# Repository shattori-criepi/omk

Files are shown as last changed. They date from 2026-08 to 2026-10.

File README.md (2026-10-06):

# OMK — おうちモニタキット

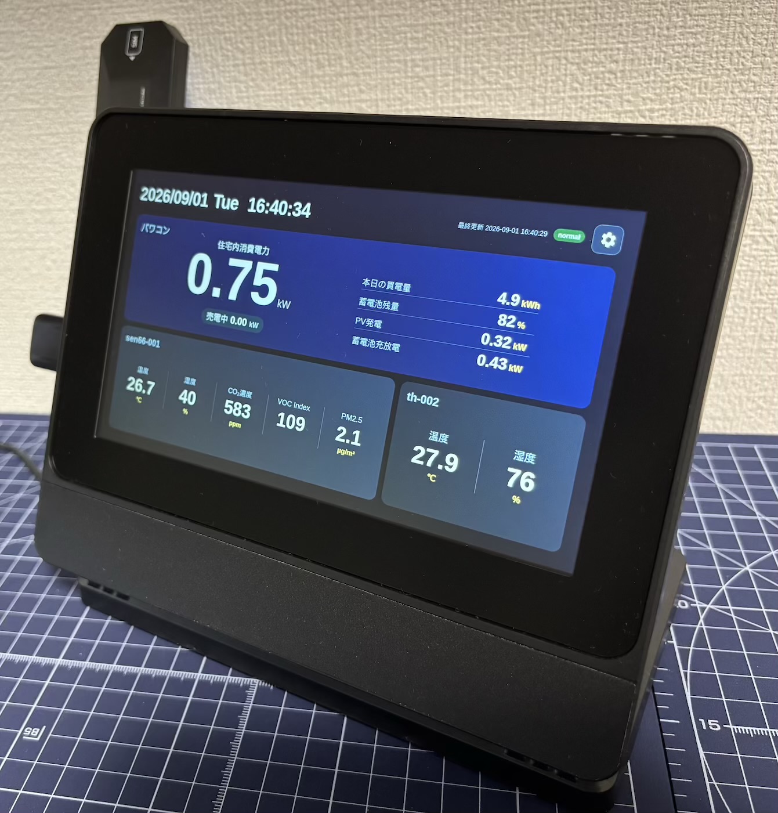
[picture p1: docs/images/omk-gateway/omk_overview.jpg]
OMK Gateway


おうちモニタキット（OMK）は、一般財団法人電力中央研究所が開発した、住宅内の電力・環境・行動を計測するオープンなIoT基盤です。計測したい項目に合わせてセンサを組み合わせ、Raspberry Piをデータ収集・保存の中心となるGatewayとして使います。標準構成では、構築後は住宅側ネットワークに依存せず運用できます。

## できること

- 対応するセンサ・機器から、住宅の温度、湿度、空気質、電力、在不在などのデータを計測・収集できます。
- Raspberry Piに計測データを保存し、長期間の履歴として蓄積できます。
- Gateway内のローカルDashboardで、現在の計測値と機器の状態を確認できます。
- 保存済みデータをCSV/ZIPとしてUSBメモリへ書き出せます。
- SORACOM Harvestを利用する場合は、計測データをクラウドへ送信して保管できます。

## OMKの製作方法

初めて製作する方は、以下を上から順に読み、各ページ末尾の「次へ」で進めてください。GatewayとSEN66 Nodeを製作し、4-1のDashboardで計測確認まで完了します。

### 1. OMKの概要

- [1-1. OMK導入ガイド](docs/user/getting-started.md)
- [1-2. 対応センサ・機器と取得データ](docs/user/supported-devices.md)

### 2. OMK Gatewayを製作・セットアップする

- [2-1. OMKのパーツ構成](docs/user/parts-list.md)
- [2-2. Gatewayの組み立て](docs/user/gateway-assembly.md)
- [2-3. Gatewayセットアップ](docs/user/gateway-setup.md)

### 3. SEN66 Nodeを製作・セットアップする

- [3-1. SEN66 Nodeの組み立て](docs/user/sen66-node-assembly.md)
- [3-2. SEN66 Nodeをセットアップする](docs/user/esp32-node-setup.md)

### 4. Dashboardを使う

- [4-1. Dashboardの使い方](docs/user/dashboard.md)

ここまでで、推奨構成のOMKの製作・セットアップとSEN66による計測確認は完了です。

## 必要に応じて行う作業

製作完了後に、目的に合うページを選んでください。

- [BLEセンサを追加する](docs/user/ble-sensor-setup.md)
- [Bルートでスマートメーターを追加する](docs/user/broute-setup.md)
- [OMK Nodeで計測範囲を拡張する](docs/user/node-and-sensors.md)
- [中継専用OMK Nodeをセットアップする](docs/user/relay-node-setup.md)
- [Gatewayソフトウェアを更新・保守する](docs/user/gateway-maintenance.md)
- [OMK Nodeを更新・再設定する](docs/user/node-maintenance.md)
- [標準構成以外・高度な構成](docs/user/advanced-configuration.md)

## 参考情報

- [用語集](docs/user/glossary.md)
- [トラブルシューティング](docs/user/troubleshooting.md)

## 対応機器と取得データ

主な対応機器と取得データは次のとおりです。計測項目、接続方式、対応範囲の詳細は[「1-2. 対応センサ・機器と取得データ」](docs/user/supported-devices.md)を参照してください。

| 機器・センサ | 主な取得データ |
| --- | --- |
| 低圧スマートメーター（Bルート） | 系統の瞬時電力、買電・売電の積算電力量、30分ごとの買電量・売電量 |
| Sensirion SEN66 | 温度、相対湿度、CO₂濃度、粒子状物質、VOC Index、NOx Index |
| SwitchBot BLEセンサ | 温湿度、CO₂濃度、人感、開閉、プラグの消費電力・スイッチ状態、防水温湿度 |

## 動作確認環境と利用上の前提

OMKで動作確認している推奨構成は次のとおりです。

- Gateway：**Raspberry Pi 4、Raspberry Pi Touch Display 2（7インチ）、SORACOM Onyx**。OSは64ビットのRaspberry Pi OSを使用します。
- SEN66 Node：Sensirion SEN66とAtomS3 Lite。

初期セットアップには、既存Wi-Fiなどのインターネット接続を使います。APはAccess Point（アクセスポイント）の略です。OMK APを有効にすると、Raspberry Piの内蔵Wi-FiはOMK AP専用となり、外部Wi-Fiには接続できません。推奨構成ではSORACOM Onyxを外部通信と遠隔管理に使います。

標準構成以外の対応範囲と制約は、[「標準構成以外・高度な構成」](docs/user/advanced-configuration.md)を参照してください。

## OMKを開発する

- [アーキテクチャ](docs/developer/architecture.md)
- [開発ガイド](docs/developer/development.md)
- [Gatewayネットワーク設計](docs/developer/networking.md)
- [データ経路とMQTT仕様](docs/developer/data-and-mqtt.md)
- [リポジトリ構成](docs/developer/repository-structure.md)
- [設計判断の記録](docs/decisions/)

各サービスとファームウェアのREADMEには、個別の起動・設定・テスト・デバッグ方法を記載しています。

## 利用上の注意

OMKは研究・実験用途のシステムであり、商用製品やサービスではありません。計測値の正確性、完全性、継続性、対応機器との互換性、安定動作および安全性は保証しません。利用、改変、機器への接続、再配布は各利用者の判断と責任で行ってください。料金精算、契約上の計量、安全制御、保護制御など、高い信頼性を要する用途での利用は想定していません。

無保証および責任制限は[LICENSE](LICENSE)を参照してください。

## 成果発表

OMKを使用した技術開発等の成果を発表・報告する際は、可能な範囲でOMKを使用した旨の表示をお願いします。

## サポートと開発方針

GitHub等から利用する場合、機器の準備、構築、設定、運用、保守は利用者自身で行います。研究所および開発者は、個別環境への導入・設定支援、機器の製作代行、トラブル対応などの個別サポート、保守、動作保証を提供しません。

活用例、アイデア、改善案など、OMK全体に有用な情報の共有は歓迎します。ただし、相談や要望に対する回答、調査、機能追加、機器対応、修正などの対応は約束しません。

特定の利用者だけに必要な機能は、利用者自身のforkで開発・維持することを想定します。OMK全体に有用なアイデアは、研究目的、汎用性、保守性、開発優先度などを踏まえて採用を検討します。提案者にPR作成を求めるとは限らず、OMK開発側が実装する場合や、実装を見送る場合もあります。

GitHubでの情報共有・提案は、次の方針で受け付けます。

- GitHub Discussions：アイデア、活用例、利用方法の情報共有に使います。無償の個別サポート窓口ではありません。
- Issue：再現可能な不具合や、対応が決まった課題の管理に使います。単なる機能追加要望はDiscussionへ投稿してください。
- コード変更・機能追加の提案：まずDiscussionで目的、背景、想定用途、OMK全体への有用性を共有してください。OMKリポジトリへの取り込みを検討する場合は、必要に応じてIssue化やPR提出を案内します。PRの常時募集は行わず、事前相談のないPRへのレビュー、マージ、対応は約束しません。

電力中央研究所が主体となる研究・実証・被験者実験で設置する場合は、研究計画に基づき、研究実施側が設置、運用、保守、トラブル対応等を行います。上記の自己責任・サポート方針によって、実験協力者へ保守責任を転嫁することはありません。

## ライセンス

OMKのソフトウェアは[使用、複製および頒布に関する条件](LICENSE)で公開します。OMKの著作権は一般財団法人電力中央研究所に帰属します。

利用、改変、再配布、商用利用については、使用許諾条件に従ってください。

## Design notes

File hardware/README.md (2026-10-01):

# ハードウェア成果物

このディレクトリには、現行構成で再現可能な筐体などのハードウェア成果物を置いています。Gateway、Docker、NetworkManagerの設定手順は[Gatewayセットアップ](../docs/user/gateway-setup.md)、内部のネットワーク設計は[ネットワーク設計](../docs/developer/networking.md)を参照してください。

## 現在の構成

- Gateway: Raspberry Pi 4、64-bit Raspberry Pi OS
- Node: AtomS3 LiteのOMK Node。SEN66等のI2CセンサとBLE relayを扱う
- Bルート: 対応USBシリアルアダプタをGatewayのhost serviceで利用
- BLE: Gateway direct BLEを主系、Node relayを補助経路として利用
- 住宅用PV・蓄電池・PCS: 現行の単一検証profile向けECHONET Lite連携はGatewayホストに任意導入するサービス

## ディレクトリ

- [`enclosures/sen66-node/`](enclosures/sen66-node/README.md): SEN66 Node試作筐体の格納済みSTLと使用上の注意
- [`enclosures/omk-gateway/`](enclosures/omk-gateway/README.md): SORACOM OnyxをGatewayへ取り付けるための固定用3Dプリント部品

SEN66計測にもBLE中継にも、AtomS3 Liteの共通Node firmwareを使用します。

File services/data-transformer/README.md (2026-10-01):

# data-transformer

`sensor-collector` が保存した日次JSONLを、分析用のParquetへ変換する独立コンポーネントです。collectorの一次データは変更しません。

```bash
cd services/data-transformer
python -m venv .venv
.venv/bin/pip install -r requirements-dev.txt
PYTHONPATH=src .venv/bin/python -m data_transformer --input ../../data/sensors/2026/07/30.jsonl --output /tmp/omk-parquet-example
PYTHONPATH=src .venv/bin/pytest -v
```

上の単体変換例は試験用出力先を使います。稼働中の`data/processed`を再処理する場合は、下記の入力パス規約を維持してください。

Raspberry Pi 4（Python 3.13.5、aarch64）では`pyarrow==20.0.0`、`duckdb==1.3.2`、`pytest==9.1.1`で検証しています。

## Parquet検証

DuckDB CLIは不要です。リポジトリ直下から、この仮想環境のPython版DuckDBで読み取り専用の検証を実行できます。

```bash
services/data-transformer/.venv/bin/python scripts/verify_parquet.py
```

`services/data-transformer`から実行する場合は、`.venv/bin/python ../../scripts/verify_parquet.py`です。

対象は`sen66`、`broute_power`、`broute_cumulative_energy`、`broute_interval_energy`です。全日付パーティションを自動で横断し、基本情報、パーティション別件数、NULL・時間別集計、SEN66受信間隔、30分値と積算差分の照合、SEN66と瞬時電力のASOF結合を表示します。Parquetや外部DBファイルを変更しません。別の出力先を確認する場合は`--data-root /path/to/processed`を指定できます。

## 変換対象と出力

変換CLIの`python -m data_transformer`では、`--input`の代わりに`--date 2026-07-30 --data-root data/sensors`を指定できます。`--dry-run`、`--log-level DEBUG`も変換CLIのオプションです。これらは上記の`verify_parquet.py`のオプションではありません。パスはコマンドを実行するディレクトリからの相対パスです。

計測トピックのBルート`power`、`cumulative-energy`、`interval-energy`、SEN66の`sen66`、Ichijoの`power-flow`、BLEの`environment`、`motion`、`contact`、`power`をParquetへ変換します。BLEは旧payloadの`sensor_id`を`device_id`として正規化し、`measured_at`がない場合はcollector受信時刻を使用します。`/power`はpayloadの`net_power_w`をBルート、`power_w`をBLEとして識別します。`omk/<device_id>/status`、`omk/node/<node_id>/status`、`omk/node/<node_id>/registration/status`、`omk/node/<node_id>/registration/ack`、`omk/node/<node_id>/registration/config`は管理情報として意図的に除外し、`ignored`と`ignored_topics`にだけ記録します。未知・不正トピックは`data/errors/transform/YYYY-MM-DD.jsonl`へ原因と元行を記録します。

出力は `data/processed/<dataset>/date=YYYY-MM-DD/data.parquet` です。データセットは`broute_power`、`broute_cumulative_energy`、`broute_interval_energy`、`sen66`、`ichijo_power_flow`、`ble_environment`、`ble_motion`、`ble_contact`、`ble_power`です。日付はBルート瞬時電力・BLE・Ichijoでは計測時刻、積算電力量では計量時刻、30分値では終了時刻、SEN66ではファームウェアが時計を持たないためcollector受信時刻のJST日付を使用します。Ichijoの`quality=degraded`レコードは計測値がnullでも`errors`（string list）とともに保持しますが、`quality=normal`では主要計測値を引き続き必須とします。今回の正常行があるpartitionは一時ファイルから原子的に置換します。置換前に同じ`source_file`の既存行だけを外してから今回の行を追加するため、同じ`source_file`表記による入力の再実行では重複せず、遅延レコードの処理で別source file由来の既存行を消しません。

### 入力パスと再処理の制約（再現確認済み）

処理済みcheckpointや別state fileはなく、毎回JSONL全体を読みます。Parquetの`source_file`に入力パスの文字列表現を保存し、merge時は今回と文字列が一致する行だけを置換します。`source_line_number`は来歴であり、record-levelの重複排除キーではありません。mtime、size、content hash、inode、timestamp/device IDによる同一性判定も行いません。

同じJSONLを同じ出力先へ別表記で投入すると、変換対象の正常行がdataset/date partitionごとに追加されます。別プロセスでの再実行でも同じ結果です。同じ表記を繰り返すだけなら増殖しませんが、既に別表記で保存された行は残ります。今回の入力に正常行がないpartitionは置換しないため、入力行の削除を既存Parquetへ反映する機能でもありません。

Python 3.13.15、固定依存のPyArrow 20.0.0 / DuckDB 1.3.2で、次を一時JSONLと新しい出力先だけを使って確認しました。

| 同じ実ファイルへの表記変更 | 再実行後 |
| --- | --- |
| 同一表記、先頭`./`、末尾スラッシュ | 重複なし。後二者はCLIの`Path`変換で除去される |
| 相対→絶対、`data/../data/...` | 重複する |
| ファイルsymlink、ディレクトリsymlink経由 | 重複する |
| リポジトリルートの`data/sensors/...`→サービス配下の`../../data/sensors/...` | 重複する |

再現試験では同一timestamp/device IDの30分値が2行になり、買電量合計も1.5 kWhから3.0 kWhへ増えました。Dashboardの日計はParquetを合計するため影響を受け、CSV exportにも重複が出ます。元JSONL、latest cache、MQTTを直接購読するHarvestの集約は、このParquet再変換では変更しません。

標準timerはホストのリポジトリルートで`--date`・`--data-root data/sensors`を使用します。同じ構成でのservice restart、Gateway reboot、setup再実行、通常updateは入力表記を変えません。collectorのDocker内`/app/data/sensors`は入力JSONL内のsource識別子ではなく、通常のtransformerはDocker外で動きます。一方、手動復旧、`--input`への切替、絶対パスの指定、別cwdからの実行、独自container/mount構成への変更では発生し得ます。

本番の手動再処理も標準timerと同じcwd・入力指定を使い、timerとの同時実行は避けてください。これは新しい別表記を増やさないための暫定運用であり、既存の重複は修復しません。

### path正規化を導入する際の互換性

新規保存だけを`Path.resolve()`へ変更すると、旧相対`source_file`と一致せず初回mergeで二重化します。旧値まで現在のcwd/symlinkで解決すると、当時と異なる実体へ対応付けて別入力の行を消す危険があります。旧Parquetは当時のcwdやsymlink先を記録しておらず、異なるcwdにある別ファイルから同一の`source_file`・行内容が生成されるケースも確認しました。この情報だけから安全な自動移行はできません。

修正候補は、新しい入力について解決済み絶対パスを保存し、同一表記差を同じ入力にする方法です。symlinkの実体切替やファイル移動は別入力として扱い、同内容の別ファイルをhashでまとめません。ただし導入には、旧形式を識別して無条件mergeを止める仕組みと、確認済みの旧source対応付け、または元JSONLが揃った状態での新しい出力先への全量再生成・比較・明示的切替が必要です。リポジトリ移動やmount先変更も移行対象になります。今回、機能コードの変更や既存Parquetの移行・修復は行っていません。

### 既存Parquetの重複候補を調べる

次はDuckDBで実行する読み取り専用SQLです。対象datasetの全partitionから、`source_file`以外の全列（`source_line_number`を含む）が同じで、source表記が複数ある行を探します。Python版DuckDBの`execute()`でも実行できます。ファイルがないdatasetには実行しません。

```sql
SELECT * EXCLUDE (source_file),
       count(*) AS copies,
       list(DISTINCT source_file) AS source_paths
FROM read_parquet('data/processed/broute_interval_energy/date=*/data.parquet')
GROUP BY ALL
HAVING count(DISTINCT source_file) > 1;
```

これは候補検出であり、同じtimestamp/device IDだけで削除を判断しません。正当な別入力に同一行がある場合も候補になり、行順変更等による重複は検出できないことがあります。元JSONL、当時の実行場所、source表記を照合して修復範囲を決めます。今回の作業環境には既存のJSONL/Parquetがなく、稼働Gatewayで既に発生しているかは未確認です。

## Raspberry Piでの1時間間隔実行

DockerではなくRaspberry Piホストのsystemd timerで実行します。リポジトリルートで次を実行してください。runtime依存のみを使うため、セットアップは`requirements.txt`をインストールします（`requirements-dev.txt`は使いません）。

```bash
chmod +x scripts/setup-data-transformer.sh scripts/run-data-transformer.sh
./scripts/setup-data-transformer.sh
```

セットアップはPython、venv、pip、`flock`を提供する`util-linux`を確認し、不足時だけ導入します。`services/data-transformer/.venv`、`data/processed`、`data/errors/transform`を作成し、実行ユーザーとリポジトリパスを埋め込んだunitを`/etc/systemd/system`へ配置します。実行ログは`logs/setup/`にも保存されます。

`omk-data-transformer.timer`は起動約2分後に開始し、その後1時間ごとに動作します。JST当日と前日をこの順で処理します。前日処理は日付切替直後に遅れて到着したレコードを取り込むためで、JSONLが存在しない日は「処理対象なし」として正常終了します。一方の日付で失敗してももう一方を処理し、最後に失敗があれば終了コード1として次回timerで再試行します。

同時起動は`data/.data-transformer.lock`への`flock`で防止します。すでに実行中ならその回は正常終了でスキップします。進行中の追記の末尾行が一時的に`invalid_json`になっても、次回の全量再変換で回復します。NULバイトなどの不正行は`data/errors/transform`へ記録され、正常行の変換は継続します。

確認と停止は次のとおりです。

```bash
sudo systemctl status omk-data-transformer.timer --no-pager
systemctl list-timers omk-data-transformer.timer
sudo journalctl -u omk-data-transformer.service --since today --no-pager
sudo systemctl disable --now omk-data-transformer.timer
```

`./scripts/setup-data-transformer.sh --print-units` は`/etc`を書き換えずにservice templateの展開結果を表示します。

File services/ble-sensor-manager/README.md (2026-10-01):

# OMK BLEセンサマネージャー

このRaspberry Piホストサービスは、BlueZ/BleakでペアリングせずBLEアドバタイズを受信し、物理的な`device_key`をOMKの論理的な`sensor_id`へ対応付け、`omk/living-env-01/environment`のようなベンダー非依存のMQTT topicをpublishします。

このサービスはDashboardコンテナの外で動作し、Dockerはホストゲートウェイ経由でポート8787へ接続します。BlueZのDBusソケットや特権コンテナは不要なため、Bluetoothへのアクセスはホストサービスに分離されたままです。setupが導入する`omk-ble-api.service`とnftables規則により、ポート8787への入力はloopbackとDocker bridgeに限定します。このAPI自体には認証がないため、この制限を維持し、ブラウザからはDashboard backendを経由します。

Pi上で`scripts/setup-ble-sensor-manager.sh`を実行すると、virtualenvの作成とsystemd unitの導入・再起動を行えます。unitは`OMK_BLE_REGISTRY`と`OMK_NODE_REGISTRY`をそれぞれ`data/ble/sensors.json`と`data/ble/nodes.json`へ設定し、`data/ble`だけを書込み可能にしたまま`ProtectSystem=strict`を維持します。登録情報はこれらの可読なJSONへ保存します。

## ESP32 Node初回Wi-Fi設定

Nodeの初回Wi-Fi設定はBLE Sensor Managerでは行わない。一般利用者はNodeをGatewayへUSB接続し、[Dashboardのセットアップ](../../docs/user/esp32-node-setup.md)でsystem-managerにprebuilt書込みとWi-Fi設定を要求する。通常firmware導入済みNodeへの開発用Wi-Fi設定には`python3 scripts/provision_omk_node_via_usb.py`も利用できる。USB transportはNode IDを取得し、credential保存・software reboot・MQTT registration statusまでを確認する。通常のBLE scan、SwitchBot relay、MQTT Node registrationはこの操作から独立して継続する。

Nodeの`node_id`はeFuse由来の物理IDであり、`logical_id`はNode自身が測定値を`omk/<logical_id>/...`へ送る場合だけの論理IDである。`logical_id`は全Nodeで一意でなければならず、Gatewayは重複した登録要求・ACK・registration statusを拒否する。BLE relay専用Nodeはrelay topicに`node_id`を使うため、`logical_id`を登録する必要はない。

新品Gatewayでも、NodeがMQTT接続時に送るretained `registration/status`の`logical_id`から登録情報を復元する。Node自身のNVSを情報源とし、以前のGateway registryやACKは不要。IDのない旧firmwareのregistered statusも受理し、既存のLogical IDを保持する。`provisioned` statusは従来どおり登録を解除する。payloadと互換性の詳細は[MQTT仕様](../../docs/developer/data-and-mqtt.md#payload)を参照。

機器管理画面では登録済みSEN66 NodeのLogical ID変更と登録解除ができる。変更はNodeのACKを受けるまでGateway上の現在値を変更せず、解除はWi-Fi credentialを残したままNodeのlogical registrationとretained ACKを消去する。オフライン中の解除要求もretain付き設定で次回接続時に適用される。

`device_key`は物理的な識別子（`switchbot:<コロンを除いた小文字MAC>`）、`sensor_id`はOMKの論理的な識別子です。registryには`device_key`、`sensor_id`、`sensor_type`、vendor、model、location、`display_name`、`enabled`だけを保存します。最新の測定値、RSSI、受信時刻、生のBLEアドバタイズデータはruntime stateとして保持し、registryへは書き込みません。

## ESP32 Node relay入力

ESP32 NodeはGatewayの`sensor_id`、SwitchBotの機種判定、decoderを持たない。Nodeはmanufacturer data、service data、BLE address、RSSIをraw observationとして次の内部MQTT topicへpublishし、Gatewayがdirect BLEと同じdecoderで`device_key`を決定する。

```text
omk-relay/<relay_node_id>/ble/raw
```

このサービスはこのtopicを購読し、既存registryで`device_key`に対応するsensorを特定します。登録済みかつ`enabled=true`のenvironment、motion、contact、power sensorだけを、Gateway受信時刻を`measured_at`として通常のsensor topicへ`source: "relay"`と`relay_node_id`を保ったまま再publishします。未登録・disabledのdevice_keyは通常sensor topicへpublishせず、自動登録もしません。

direct BLEも同じ通常のsensor topicへ`source: "direct"`でpublishします。Gatewayは有効なdirect observationを受信してから30秒未満のrelayを抑止し、direct復帰時は同値でも最初のdirectを即時publishします。経路の冗長化とJSONL/Harvestでの重複排除は[`docs/decisions/ble-direct-relay-route-selection.md`](../../docs/decisions/ble-direct-relay-route-selection.md)を参照してください。

Dashboardの機器管理内のセンサ登録フローでは、未登録のBLEアドバタイズを発見・分類し、IDを提案した後、選択した表示名とlocationで登録します。`temperature_humidity_sensor`と`waterproof_sensor`には未使用で最小の`th-xxx`、`co2_sensor`には`co2-xxx`、状態センサには対応する`motion-xxx`（人感センサーとPresence Sensor Pro）/ `contact-xxx`を提案します。センサを交換した場合は、原則として新しい論理IDを発行します。

未知のSwitchBot BLEアドバタイズは、セットアップ中にmanufacturer dataとservice dataの生hexを付けて意図的に表示します。推測した値をpublishせずに、Meter Pro CO2、人感センサ、開閉センサを実機で検証できるようにするためです。

OMKでは製品名と内部modelを分離しています。SwitchBot MeterおよびMeter Plusは`temperature_humidity_sensor`、SwitchBot Meter Pro CO2は`co2_sensor`を使用します。旧来の`meter`、`meter_plus`、`meter_pro_co2`を持つ既存registryは互換的に読み込み、次回のregistry更新時に現行名へ書き換えます。

| OMK model | Dashboard表示名 | sensor type | 正規化後の値 |
| --- | --- | --- | --- |
| `temperature_humidity_sensor` | SwitchBot 温湿度計 | `environment` | `temperature_c`, `relative_humidity_percent` |
| `co2_sensor` | SwitchBot CO2センサー | `environment` | 温度、湿度、`co2_ppm` |
| `motion_sensor` | SwitchBot 人感センサー | `motion` | `motion_state` (0=不在, 1=検知) |
| `presence_sensor` | SwitchBot Presence Sensor Pro | `motion` | `motion_state` (0=不在, 1=検知), `battery_percent`, `light_level` |
| `contact_sensor` | SwitchBot 開閉センサー | `contact` | `contact_state` (0=閉, 1=開) |
| `waterproof_sensor` | SwitchBot 防水温湿度計 | `environment` | `temperature_c`, `relative_humidity_percent` |
| `plug_sensor` | SwitchBot プラグミニ | `power` | `power_w`, `switch_state` (0=OFF, 1=ON) |

`waterproof_sensor`は屋外専用ではありません。設置用途は`location`（例: 屋外、浴室）で表します。`humidity_percent`、`outdoor_meter`、`waterproof_meter`はOMKのschema/model名ではありません。

## 登録の削除と交換

管理画面の`/admin/sensors`では、編集画面から登録済みBLEセンサを`device_key`単位で登録解除できます。この操作はregistryの登録情報だけを削除し、JSONL、Parquet、Harvest retry queue、SORACOM Harvest Data、MQTTの過去履歴には一切触れません。削除された`sensor_id`は空くため、故障交換時は旧センサを削除し、セットアップモードで発見した新品へ同じ`sensor_id`を再使用できます。

`enabled=false`は一時的な停止であり、registryと`sensor_id`の占有を維持しつつruntime stateの更新だけを続け、MQTT publishを止めます。一方、削除後はregistryから完全に外れ、以後MQTT publishしません。周囲で同じ物理デバイスのBLEアドバタイズを受信し続けていれば、未登録candidateとして再び表示され、セットアップから再登録できます。

BLEアドバタイズはペアリングなしで継続受信します。`enabled=true`のenvironmentセンサは、最初に有効な値を受信した時点で即時publishし、その後は`device_key`ごとに最短10秒間隔でpublishします。runtime stateはBLE受信ごとに更新します。motionとcontactは状態変化時に即時publishし、加えて現在状態を最短10秒間隔でpublishします。これらの制限にはmonotonic clockを使用します。Plug Miniの電力も同じ10秒制限に従いますが、`switch_state`の変化時は即時publishします。`enabled=false`のセンサもruntime stateは更新しますが、MQTTはpublishしません。Plug Miniには`plug-xxx`を提案し、`power_w`と`switch_state`を含む`omk/<sensor_id>/power`をpublishします。

対応serviceのdevice typeを先に選び、登録済みmodel hintと矛盾したらunknownにします。serviceがないmanufacturer-only packetは、既存登録のhintに対応する形式だけを検証します。長さ・実測marker・正常値だけで新規機種を判定しません。MeterとMeter Pro CO2の観測済みmanufacturer形式も同じ方針です。CO2の2個体での実測は値形式の根拠であり、16-byte長の機種固有性を保証しません。

manufacturer-only packetは自動ではunknownになります。対応するmanufacturer decoderで再検証し、成立するmodelがちょうど1種類の候補だけに「候補（未確認）」と参考値を表示します。たとえば防水温湿度計では温度・相対湿度、人感センサーでは検知状態を確認できます。複数modelが成立するpacket、不正値、矛盾するservice dataには登録ボタンを出しません。参考値はcandidate APIとDashboardの確認専用で、利用者が機種を確認して登録するまでhint、MQTT通常topic、保存・集約には使いません。Meterの`0x54` / `0x69`、CO₂センサーの`0x35`、Motion Sensorの`0x73` serviceは自動識別を維持します。Motionは妥当なmanufacturer statusがあれば、その検知状態をservice値より優先します。firmware/broadcast modeやservice取得可否により、対応製品でも未認識となる可能性があります。不正値・矛盾は空valuesとし、登録・測定値publishに使いません。登録済み一覧の未識別packetは「機種・データ未確認」と表示します。根拠分類、移行上の注意、実機確認計画は[model evidence設計](docs/switchbot-model-evidence.md)を参照してください。

将来のclassifier変更では、[2026-08-20 SwitchBot raw capture監査](docs/switchbot-raw-capture-audit-2026-08-20.md)に記録した個体数・capture数・byteごとの根拠レベルも参照してください。

## Raspberry Piでの確認事項

Pi内蔵Bluetoothでは、SwitchBot BLEアドバタイズが`manufacturer_data[0x0969]`だけで報告されることがあり、Presence Sensor ProのScan ResponseをHCIレベルで取得できない実機差が確認されている。そのため`service_data`が空でもエラーではない。AtomS3 Lite Node relayはactive scanでScan Responseを取得でき、Presence Sensor Proのmanufacturer dataとfd3d service dataを結合したraw observationを実機確認済みである。新しいfixtureを取得する際、`raw_scan`は両方の構造を出力する。

公開前の追加実機確認では、利用者が新品microSDから標準Pi4 Gatewayを構築し、旧registryなしでPresence Sensor Proを初回登録できたと報告している。service dataの取得には環境差があるという上記の観測記録と、このfresh登録成功は区別して保持する。

```sh
PYTHONPATH=src .venv/bin/python -m omk_ble.raw_scan --seconds 30
```

サービスを起動する前に、`rfkill list bluetooth`と`bluetoothctl show`でアダプタを確認します。soft blockされている場合は、`sudo rfkill unblock bluetooth`、続いて`sudo bluetoothctl power on`を実行してください。セットアップスクリプトも可能な範囲でこれらを実行します。アダプタがない、または電源を投入できない場合は、導入を失敗させず警告を記録します。

過去のRaspberry Pi実機確認記録（今回の判定変更後の実機確認は未実施）:

- SwitchBot 温湿度計: BLEアドバタイズの受信、温度・湿度のdecode。
- SwitchBot CO2センサー: BLEアドバタイズの受信、温度・湿度・CO2 ppmのdecode（2台の実機で確認）。
- SwitchBot 人感センサー: BLEアドバタイズの受信、状態遷移、定期MQTT publish。
- SwitchBot Presence Sensor Pro: BLEアドバタイズの受信、在不在状態・battery・照度のdecode。
- SwitchBot 開閉センサー: BLEアドバタイズの受信、状態遷移、定期MQTT publish。
- SwitchBot 防水温湿度計: BLEアドバタイズの受信、専用temperature/humidity manufacturer layoutのdecode。
- SwitchBot プラグミニ: BLEアドバタイズのみからの電力・switch stateのdecode。公開されている`0x67`および国内実機で観測した`0x6a`のservice typeをmanufacturer推定より優先します。電力値はMSBのoverload flagをmaskしてから、0.1 W scaleを適用します。

### SwitchBot プラグミニ実機確認

Raspberry Piと実Plug Miniで、ペアリングなしのBLEアドバタイズ受信からDashboardのBLEセットアップ、`plug-001`登録、MQTT、JSONL保存、Harvest 1分集約、SORACOM Harvest Data送信までを確認した。内部modelは`plug_sensor`、sensor typeは`power`、Dashboard表示名は「SwitchBot プラグミニ」である。

manufacturer dataではstate byteのbit 7を`switch_state`として用い、0=OFF、1=ONを実機のOFF→ON操作と照合した。電力は公式仕様に従い`raw_power = ((byte10 & 0x7f) << 8) | byte11`、`power_w = raw_power / 10.0`でdecodeする。byte10のbit 7はoverload flagであり電力値から除外する。低負荷で`0x0034`=5.2 W、`0x0035`=5.3 W（アプリ表示約5.1〜5.2 W）、高負荷で`0x05f2`=152.2 W、`0x06c4`=173.2 W、`0x06cd`=174.1 W（実負荷約170 W）を確認し、低負荷・高負荷とも0.1 W scaleが成立した。

国内実機ではfd3d Service Dataとして`6a0064`を観測した。`0x6a`は参照した公式実装にもあるが、公式BLE仕様書の`0x67`とは根拠を区別する。どちらもPlug選択の根拠とし、12-byte manufacturer layoutは選択後の値検証に使用する。

国内Plug Miniの複数個体で12-byte manufacturerアドバタイズデータを確認している。byte 8は旧個体で`0x16`、新品個体で`0x10`を観測したため、固定classifierには使用しない。service dataの公開device type `0x67`または国内実測値`0x6a`で識別できる場合、state byte（index 7）と末尾2 byteから値をdecodeする。state byteのbit 7は`switch_state`、電力は`((data[10] & 0x7f) << 8) | data[11]`に0.1 W scaleを適用する。新品実機の`...8010370037`はON / 5.5 Wとして確認した。service dataがない場合は登録済みPlug hintを要求し、未登録ではunknownにする。`0x16` markerだけでの初回識別は廃止した。`0x10`および`0x16`の意味は現時点で断定しない。

Piで行指向のraw captureを取得するには、`PYTHONPATH=src .venv/bin/python -m omk_ble.raw_scan --seconds 30`を使用します。

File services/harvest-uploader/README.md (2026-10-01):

# harvest-uploader

`harvest-uploader`はMQTTを独立クライアントとして`omk/#`購読し、受信時刻（Asia/Tokyo）の00秒から59秒までを住宅全体の1分レコードへ集約してSORACOM Harvest DataへPOSTします。受信した測定・管理メッセージのJSONL一次保存は`sensor-collector`が担い、本サービスはJSONLやParquetを読まず変更もしません。

## MQTT入力

| トピック | 使用フィールド |
| --- | --- |
| `omk/<device_id>/sen66` | `temperature_celsius`、`relative_humidity_percent`、`co2_ppm`、`pm1_0_ug_m3`、`pm2_5_ug_m3`、`pm4_0_ug_m3`、`pm10_0_ug_m3`、`voc_index`、`nox_index` |
| `omk/<device_id>/power` | `net_power_w` |
| `omk/<device_id>/cumulative-energy` | `cumulative_energy_import_kwh`、`cumulative_energy_export_kwh` |
| `omk/<device_id>/power-flow` | `pv_power_w`、`load_power_w`、`grid_import_power_w`、`grid_export_power_w`、`pcs_ac_output_power_w`、`battery_soc_percent`、`battery_charge_power_w`、`battery_discharge_power_w` |
| `omk/<sensor_id>/environment` | `temperature_c`、`relative_humidity_percent`、`co2_ppm`（存在する項目のみ） |
| `omk/<sensor_id>/motion` | `motion_state` |
| `omk/<sensor_id>/contact` | `contact_state` |
| `omk/<sensor_id>/power` | `power_w`、`switch_state`（Plug Mini等の電力センサ） |

Bルート`power`の`net_power_w`は正値が買電、負値が売電です。Plugの`power_w`とは区別します。電圧・電流・力率、蓄電池の運転状態はHarvestへ送信しません。不正JSON、JSON objectではないpayload、非有限数は安全に無視します。

### Thread model

Paho MQTTのnetwork callbackは、topic・payload・callback時点のJST受信時刻をthread-safeなFIFO inboxへ投入するだけです。集約、SQLite durable outbox、Harvest送信、retryは実行ループのmain threadだけがinboxをdrainした後に処理します。このため、処理遅延が分境界をまたいでも集約にはcallback時点の受信分を使い、SQLite connectionを複数threadで共有しません。

## Harvestフィールドと集約

SEN66はMQTT topicのLogical ID（1〜48文字の英数字、`-`、`_`）をfield prefixに使います。たとえば`omk/sen66-001/sen66`は`sen66-001_temperature_c`、`sen66-001_relative_humidity_percent`、`sen66-001_co2_ppm`、`sen66-001_pm1_0_ug_m3`、`sen66-001_pm2_5_ug_m3`、`sen66-001_pm4_0_ug_m3`、`sen66-001_pm10_0_ug_m3`、`sen66-001_voc_index`、`sen66-001_nox_index`を生成します。`sen66-002`も同じ規則で別fieldになり、同一分の平均値はSEN66ごとに独立します。Bルートは`broute_grid_power_w`、`broute_grid_import_power_w`、`broute_grid_export_power_w`、`broute_grid_import_energy_kwh`、`broute_grid_export_energy_kwh`です。電力系は`power_system_pv_power_w`、`power_system_load_power_w`、`power_system_grid_import_power_w`、`power_system_grid_export_power_w`、`power_system_pcs_ac_output_power_w`、`power_system_battery_soc_percent`、`power_system_battery_charge_power_w`、`power_system_battery_discharge_power_w`です。

`time`は区間開始時刻（例: `2026-08-05T10:34:00+09:00`）です。温湿度・空気質・各瞬時電力は有効サンプルの平均、積算買売電量とSOCは区間末の最新値です。欠測フィールドはJSONから省略し、全項目欠測の区間は送信しません。開いた1分区間はメモリだけに保持するため、再起動時には意図的に破棄されます。

`environment` は汎用のセンサ入力です。許可された `sensor_id`（英数字、`-`、`_`）ごとに、`<sensor_id>_temperature_c`、`<sensor_id>_relative_humidity_percent`、`<sensor_id>_co2_ppm` を生成し、存在する各項目を1分平均で送信します。これらはSEN66のLogical IDベースfieldと独立して共存します。

`motion` は `<sensor_id>_motion_state` をその1分の最大値として送信します（0=その分に検知なし、1=一度以上検知）。`contact` は開閉回数を保存せず、状態変化が一度でもあれば `<sensor_id>_contact_changed` を1、最後に観測した状態を `<sensor_id>_contact_state` として送信します（0=閉、1=開）。分境界をまたぐ状態変化は次の分の変化として扱い、再起動後の最初の観測は変化に数えません。

電力センサの`power` payloadに`power_w`または`switch_state`がある場合は、許可された`sensor_id`ごとに`<sensor_id>_power_w`（1分平均）と`<sensor_id>_switch_state`（分内の最後の正常値、0=OFF、1=ON）を送信する。Bルートの既存`power` fieldとは独立して共存する。

SwitchBot Plug MiniのPi実機では、`plug-001_power_w`と`plug-001_switch_state`が SORACOM Harvest Dataへ送信されることを確認した。分内で負荷を変えた例では瞬時値が約170 Wに達する一方、1分平均の`plug-001_power_w`は137.3 W、最後の状態`plug-001_switch_state`は1となった。これは電力を平均、switch stateを最後の正常値として扱う仕様どおりである。

## 再送と設定

HTTP成功は2xxです。確定した1分レコードは送信前にoutboxへ保存し、成功後に削除します。失敗したレコードは`HARVEST_QUEUE_PATH`のSQLite outboxに保持され、再送時刻に到達したものを古い順に1回の処理で最大1件ずつ、最大60秒の指数バックオフで再送します。作成から`HARVEST_RETRY_MAX_AGE_SECONDS`（既定3600秒）を超えたものは警告ログとともに破棄します。SQLiteにより再起動後も再送待ちデータを保持します。

環境変数は`MQTT_HOST`（既定`mosquitto`）、`MQTT_PORT`（`1883`）、`MQTT_CLIENT_ID`（`omk-harvest-uploader`）、`MQTT_TOPIC`（`omk/#`）、`HARVEST_ENDPOINT`（`http://harvest.soracom.io`）、`HARVEST_TIMEOUT_SECONDS`（`10`）、`HARVEST_RETRY_MAX_AGE_SECONDS`（`3600`）、`HARVEST_QUEUE_PATH`、`TZ`です。認証情報・APIキーをpayloadやソースへ入れません。

Compose外で起動する場合や既定値を確認する場合は、secretを含まない[`.env.example`](.env.example)を参照してください。必要に応じてこれをローカルの`.env`へコピーし、接続先などを設定します。アプリ自体は`.env`を自動読込みしないため、Compose外では起動するプロセスへ環境変数として渡してください。

Harvest Data側では、731日保持とカスタムタイムスタンプを利用できる設定を別途有効化してください。

## 起動・テスト

```bash
docker compose up -d --build harvest-uploader
docker compose logs -f harvest-uploader

cd services/harvest-uploader
python3 -m venv .venv
.venv/bin/pip install -r requirements-dev.txt
PYTHONPATH=src .venv/bin/python -m pytest
```

ローカルでHTTP送信を確認する場合は、POSTを受け付けて2xxを返すモックサーバーを用意し、`HARVEST_ENDPOINT`へそのURLを指定します。`python3 -m http.server`の標準ハンドラはPOSTを受け付けないため、送信成功の確認には使えません。HTTP応答と再送の単体テストは上記のpytestで実行できます。実Harvestへの本番送信はこのリポジトリのテスト対象外です。

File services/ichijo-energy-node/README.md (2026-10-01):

# ichijo-energy-node

開発者宅の住宅用PV・蓄電池・PCS設備がローカルLANで公開するECHONET Lite値を、OMKのMQTTブローカーへ送る読み取り専用サービスです。標準ライブラリの小さなUDP実装を使い、GET以外のECHONET Lite要求、機器設定変更、探索、ブロードキャスト、ルーティングは行いません。

## 位置づけ

`ichijo-energy-node`は、OMKの標準構成や必須サービスには含まれないオプションサービスです。service名は検証profileの由来を示す内部識別子であり、住宅販売会社や機器メーカーの対応範囲を表すものではありません。

現時点では、開発者宅の**1住宅・1メーカー・単一機種／設備構成**でのみ動作確認しています。同一または近い設備を含め、他個体、他型番、他構成での動作は保証しません。住宅販売会社・機器メーカーが公式提供または想定するAPI／利用方法ではありません。対象設備がないOMK環境では、導入、設定、起動する必要はありません。

既存のBルート、SEN66、sensor-collectorとは独立したサービスであり、未使用時にOMKの標準機能へ影響しません。同種の住宅設備やパワーコンディショナのローカルデータをMQTTへ変換するエッジノードを実装する際の参考実装として、OMKリポジトリ内に保持します。

この検証profile固有のECHONET Liteオブジェクト、プロパティ、単位、符号規則、状態コードを前提とするため、現時点では汎用的な`power-conditioner-node`などへ改名しません。collectorの固定EOJ/EPCは、この単一の実機確認済みprofile専用であり、EOJやinstanceの自動探索は行いません。他設備へ流用する場合は、対象実機でEOJ、EPC、単位、符号、状態コードをあらためて確認してください。

```text
Validated PV / battery / PCS ECHONET Lite profile -- UDP/3610, GET only --> Raspberry Pi --> MQTT --> OMK collector (omk/#)
```

`sensor-collector`はすでに`omk/#`を購読しているため、`power-flow`と`status`は変更なしでJSONL一次保存されます。正常な`power-flow`は表示用の`data/latest/ichijo_power_flow.json`も更新し、dashboardのPV・蓄電池表示に使用されます。

## Validated equipment profile

このprofileは開発者宅の1住宅・1メーカー・単一機種／設備構成での確認結果であり、他設備への互換性を示すものではありません。検証profileの由来として住宅販売会社名を内部service名に残していますが、同社または各機器メーカーの公式API／公式利用方法ではありません。

| 項目 | 現在の記録 |
| --- | --- |
| PCS manufacturer / model | **TODO — human confirmation required** |
| battery manufacturer / model | **TODO — human confirmation required** |
| communication device manufacturer / model | **TODO — human confirmation required** |
| firmware version | **TODO — human confirmation required** |
| verification date | **TODO — human confirmation required** |
| 接続方式 | 同一L2上のIPv4 UDP/3610、ECHONET Lite Format 1、GET-only/read-only |

ここにない機器情報は推測しません。型番または構成が異なる設備へ適用する前に、下記のEOJ、EPC、単位、符号、状態コードを実機で確認してください。

## 対象と変換

| 値 | EOJ / EPC | EDT | 実機確認済みの規則 |
| --- | --- | --- | --- |
| PV瞬時発電 | `027901` / `E0` | unsigned 2 bytes | W、正値 |
| 蓄電池SOC | `027D01` / `E4` | unsigned 1 byte | % |
| 蓄電池充放電 | `027D01` / `D3` | signed 4 bytes | 正=充電、負=放電 |
| 蓄電池運転状態 | `027D01` / `CF` | unsigned 1 byte | `42` charging、`43` discharging、`44` standby |
| 系統瞬時電力 | `028701` / `C6` | signed 4 bytes | 正=買電、負=売電 |
| PCS交流瞬時電力 | `02A501` / `E7` | signed 4 bytes | 実機で負=交流側出力 |

未知の状態コードは`unknown`とし、`battery_operating_state_raw`にも生コードを残します。PCS E7は現時点の実機確認範囲に基づき`pcs_ac_output_power_w = max(-raw, 0)`とします。正値の意味（系統から蓄電池への充電など）は未確認です。

住宅消費電力は`PCS交流出力 + 買電 - 売電`で計算します。PVと蓄電池電力は個別の計測値として保持しますが、各ECHONET Liteプロパティは順次取得されるため、急変時の時刻差の影響を抑える目的で住宅消費の計算には使いません。必須値が欠けた場合は`load_power_w`を`null`、`quality`を`degraded`にします。負の収支値は0に丸めず保持し、同じく`degraded`とします。`measured_at`は全プロパティを読み終えた取得サイクル終了時刻で、JSTのISO 8601です。

## 設定と起動

`cp .env.example .env`の後、実機値に合わせて環境変数を設定します（`.env`はGit管理外）。主な値は`ICHIJO_DEVICE_ID`（既定`ichijo-001`）、`ICHIJO_ECHONET_TARGET_IP`（必須。空欄不可）、`ICHIJO_ECHONET_INTERFACE`（`eth0`）、`ICHIJO_POLL_INTERVAL_SECONDS`（`10`）、`ICHIJO_ECHONET_TIMEOUT_SECONDS`（`2`）、`ICHIJO_ECHONET_RETRY_COUNT`（`1`）、`ICHIJO_PROPERTY_INTERVAL_SECONDS`（`0.05`）、`MQTT_HOST`（Gateway上では`127.0.0.1`）、`MQTT_PORT`（`1883`）、`MQTT_KEEPALIVE_SECONDS`（`60`）です。ローカルIPは指定インターフェースから取得し、UDP送受信とも3610を使います。

```bash
cd services/ichijo-energy-node
python3 -m venv .venv
.venv/bin/pip install -r requirements-dev.txt
# 自分で作成・確認した.envを環境変数へ読み込む（アプリは自動読込みしない）
set -a
. ./.env
set +a
PYTHONPATH=src .venv/bin/python -m ichijo_energy_node

# 実機導入時: MQTTへ送らず1サイクルを標準出力
PYTHONPATH=src .venv/bin/python -m ichijo_energy_node --once --no-mqtt

# 実機ネットワークなしの単体テスト
PYTHONPATH=src .venv/bin/python -m pytest
```

## Raspberry Piでのsystemd常時運用

実運用では、リポジトリルートから次を実行します。スクリプト全体を`sudo`で起動せず、必要な管理操作だけでsudoを使います。runtime依存だけを`requirements.txt`から導入し、systemdサービスを有効化して起動します。

```bash
./scripts/setup-ichijo-energy-node.sh --dry-run
./scripts/setup-ichijo-energy-node.sh --print-unit
./scripts/setup-ichijo-energy-node.sh
```

事前にsystemdユニットの展開結果だけを確認する場合は、root権限やファイル変更を必要としません。

```bash
scripts/setup-ichijo-energy-node.sh --print-unit
```

実運用の設定は`/etc/omk/ichijo-energy-node.env`に置きます。初回セットアップ時だけ`.env.example`から`root:root`・`0600`で生成されます。その直後は`ICHIJO_ECHONET_TARGET_IP`を設定してsetupを再実行するまでserviceを有効化・起動しません。既存ファイルは上書きせず、必要なキー名と対象IPの設定有無だけを検査します。旧`ICHJO_*`キーを検出した場合は内容を変更せず、`ICHIJO_*`へ移行してから再実行するよう安全に停止します。設定値はdry-runやログへ表示しません。systemdの`EnvironmentFile`として読むため、`KEY=value`だけを記述し、`export`やshell展開には依存しないでください。設定を編集しただけでは反映されないため、次で再起動します。

```bash
sudo systemctl restart omk-ichijo-energy-node.service
```

unitは内容が異なる場合だけ更新され、同一なら維持されます。通常setupはpipを実行するため、activeなサービスへ依存関係を反映する目的でrestartします。setupログは`logs/setup/ichijo-energy-node-setup-YYYYMMDD-HHMMSS.log`です。既存の実測データや`data/latest/ichijo_power_flow.json`には影響しません。状態とログは次で確認できます。

```bash
sudo systemctl status omk-ichijo-energy-node.service --no-pager
sudo journalctl -u omk-ichijo-energy-node.service -f
systemctl is-enabled omk-ichijo-energy-node.service
systemctl is-active omk-ichijo-energy-node.service
```

停止して自動起動を無効化するには次を実行します。

```bash
sudo systemctl disable --now omk-ichijo-energy-node.service
```

`network-online.target`はネットワーク準備の補助に留めます。起動時に`eth0`へIPv4がなければアプリケーションは終了し、systemdが10秒ごとに再起動して後から復旧します。MQTT未接続中もECHONETの収集は続きますが、MQTTメッセージのローカル永続バッファはありません。systemd導入後も、上記の`--once --no-mqtt`診断モードを手動で使えます。

## MQTT

QoSは0です。`omk/<device_id>/power-flow`はサイクルごとに1件、retainなしで送ります。`omk/<device_id>/status`はretainありで、接続時`online`、正常終了時`offline`を送信し、Last Willにも`offline`を設定します。Paho MQTTの1～30秒指数バックオフを使用します。

```json
{"device_id":"ichijo-001","measured_at":"2026-08-03T15:32:14+09:00","pv_power_w":410,"battery_soc_percent":48,"battery_charge_power_w":0,"battery_discharge_power_w":683,"battery_operating_state":"discharging","battery_operating_state_raw":67,"grid_import_power_w":14,"grid_export_power_w":0,"pcs_ac_output_power_w":1093,"load_power_w":1107,"quality":"normal","errors":[]}
```

## トラブルシューティングと未確認事項

`Network configuration error`は対象インターフェースにIPv4がない状態です。`ECHONET timeout`は対象IP、同一L2接続、UDP 3610、送信元が3610であることを確認します。DEBUGログで生フレームを確認できますが、通常ログへは出しません。

対象IPの将来的な変更、自動探索、E7正値の意味、長期連続運転、ネットワーク切断からの実機復旧、OMK専用AP経由のMQTTは未実装・未確認です。`power-flow`のJSONL→Parquet変換とlatest JSON経由のdashboard表示は対応済みです。dashboardはこのprofileのデータが10分を超えて古い場合、Bルート電力へフォールバックします。

旧設定で`MQTT_HOST=192.168.50.1`を指定している場合は、`/etc/omk/ichijo-energy-node.env`を`127.0.0.1`へ変更してからsetupを再実行してください。setupはこの旧設定を検出すると、service変更前に停止します。

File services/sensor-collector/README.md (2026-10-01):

# sensor-collector

Mosquittoの`omk/#`を購読し、payloadの機種別仕様を解釈せず日次JSONLへ追記するサービスです。`status`トピックも収集します。ただし通常のBLE測定topicでは保存前に`device_id`と`source`を確認し、direct受信から30秒未満のrelay観測を除外します。対象は`environment`、`motion`、`contact`、`power`で、値が同じかどうかによる重複除去ではありません。

各取得処理と保存処理を分離するための一次保存サービスです。MQTTトピックは`omk/<device_id>/<data_type>`を基本とし、新しいセンサや測定項目の追加にcollectorの変更は必要ありません。CSV変換、分析、可視化、外部送信は別コンポーネントで行います。Harvest uploaderはMQTTを独立して購読し、JSONL保存の完了を待ちません。

## 設定

| 環境変数 | デフォルト | 説明 |
| --- | --- | --- |
| `MQTT_HOST` | `mosquitto` | MQTT brokerのComposeサービス名 |
| `MQTT_PORT` | `1883` | MQTT brokerポート |
| `MQTT_TOPIC` | `omk/#` | 購読トピック |
| `DATA_ROOT` | `/app/data/sensors` | JSONL保存先 |
| `LATEST_DATA_ROOT` | `/app/data/latest` | dashboard向け最新状態JSONの保存先 |
| `TZ` | `Asia/Tokyo` | コンテナのタイムゾーン |
| `LOG_LEVEL` | `INFO` | ログレベル |

各行には、Raspberry Pi側で付与した`received_at`、`topic`、`qos`、`retain`、および受信payloadを入れます。通常のJSON payloadは`payload`にそのままネストします。不正JSONは`payload_raw`と解析エラーを、UTF-8でないデータはBase64を保存します。

## 汎用latest store（Dashboard可変化の基盤）

JSONLへの保存成功後、正常なJSON payloadのうち、`omk/<topic-device-id>/<data-type>`かつ payloadに文字列`device_id`を持つレコードから、表示候補になり得るscalar値を`LATEST_DATA_ROOT/items/<stable-item-id>.json`へ保存します。同時に`LATEST_DATA_ROOT/catalog.json`を更新するため、Dashboardは全候補をディレクトリ走査なしで列挙できます。Dashboardはこのstoreを表示候補と表示設定の基準として使用します。

stable item IDは`SHA-256(topic + NUL + device_id + NUL + field)`のhexに`item_v1_`を付けたものです。したがって同じ`power` topic typeや`temperature_c` fieldでも、topicまたはdevice_idが異なれば衝突しません。itemファイルには最新のraw scalar値、型、`measured_at`（payloadにある場合）、`received_at`、MQTT QoS/retainを、catalogにはID、source、型、最終受信時刻を保存します。catalogは検出済み候補を自動削除しないため、受信停止や collector再起動後も候補は残ります。

候補は有限のnumber、boolean、64文字以下の制御文字を含まないstringです。`device_id`、`*_at`、`*_id`、`*_raw`、quality、errors、source、firmware、uptime等の時刻・識別子・診断メタデータは除外します。表示名、単位、精度、カテゴリ、意味上の電力スロットはDashboardで解釈します。

各JSONは同一ディレクトリの一時ファイルからatomic replaceで更新し、`0644`で公開します。10秒程度の更新頻度では、対象scalarごとのitem置換と1回の小さなcatalog置換だけを行います。

### 既存Dashboardとの互換性

互換性のため固定latestも併行して維持します。Bルート`power`で`net_power_w`を持つものは`broute_power.json`、`sen66`は`sen66.json`、`power-flow`は`ichijo_power_flow.json`へ従来どおり保存します。BLE Plugの`power_w`/`switch_state`はgeneric storeには保存されますが、`broute_power.json`を上書きしません。

不正JSON、Base64 payload、topic形式または`device_id`が不正なpayloadはgeneric latestを更新しません。最新状態の保存に失敗しても、JSONL収集は継続します。

latest JSONは置換後に`0644`へ設定するため、ホストユーザーおよび読み取り専用でマウントしたdashboardから読み取れます。

## 実行と確認

```bash
docker compose up -d --build sensor-collector
docker compose logs --tail=100 sensor-collector
tail -n 1 data/sensors/$(date +%Y)/$(date +%m)/$(date +%d).jsonl | python3 -m json.tool
```

MQTTの初回接続、broker再起動後の再接続には、Paho MQTTの上限60秒の指数バックオフを使用します。collectorを再起動しても既存の日次ファイルへ追記します。

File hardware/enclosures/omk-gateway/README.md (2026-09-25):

# OMK Gateway筐体

このディレクトリには、SORACOM OnyxをOMK Gatewayへ省スペースに取り付けるための3Dプリント部品を格納しています。

## 用途

回転式USB-A変換コネクタを使ってOnyxの向きを90度変更し、この部品でOnyxを固定する参考構成です。Onyxの利用や設定に必須ではありません。

## 使用する参考部品

- [SORACOM Onyx LTE USBドングル](https://soracom.jp/store/7326/)
- [エスエスエーサービス USB A変換コネクタ（Aメス/Aオス 回転式）](https://www.amazon.co.jp/dp/B00OPYC7DK)

## STL

- [onyx-usb-holder.stl](onyx-usb-holder.stl): Onyx固定用部品

## 注意

- この部品は試作ハードウェア成果物です。
- Raspberry Pi、ケース、USBコネクタなどの個体差を確認して使用してください。
- USB端子へ無理な力を加えないでください。
- Onyxの放熱や通信を妨げないよう、実際の設置状態を確認してください。

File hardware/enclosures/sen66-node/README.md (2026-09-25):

# SEN66 Node試作筐体

このディレクトリには、AtomS3 LiteとSEN66を主な対象とするSEN66 Node用3Dプリント試作筐体のSTLを格納しています。

## 格納済みSTL

- [sen66-node-body.stl](sen66-node-body.stl): 本体
- [sen66-node-lid.stl](sen66-node-lid.stl): 蓋
- [sen66-node-cable-jig.stl](sen66-node-cable-jig.stl): USB-Cケーブルの引張による抜けを軽減するための固定治具

現時点では試作筐体です。SEN66の吸気・排気を塞がず、センサの設置向きと通気を考慮して使用してください。

組み立てにはM3×8mmネジを6本使用します。3Dプリントしたネジ穴にはM3タップ加工が必要です。印刷方向、材料、積層条件は未確定のため、根拠のない推奨値は記載しません。筐体成果物はこのディレクトリで管理します。

ケーブル固定治具は、現在Anker Zolo USB-C & USB-A ケーブルでのみ適合を確認しています。USB-Cプラグのモールド形状が異なるケーブルには適合しない可能性があります。

利用者向けの組み立て概要は[SEN66 Nodeの組み立て](../../../docs/user/sen66-node-assembly.md)を参照してください。

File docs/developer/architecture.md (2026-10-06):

# アーキテクチャ

この文書は現行OMK実装の構成を説明します。利用手順は[利用者向け文書](../user/getting-started.md)、設計判断の採否履歴は[decisions](../decisions/)、原則は[設計原則](../design-principles.md)を参照してください。

## 全体構成

```text
センサ / Bルート / パワコン / BLE / ESP32 Node
                     ↓ MQTT
Mosquitto → sensor-collector → JSONL → data-transformer → Parquet → Dashboard
                                                        └→ data-exporter → CSV/ZIP → USB
     └── harvest-uploader → 1分集約 → SORACOM Harvest
```

Gatewayの正式な動作確認対象はRaspberry Pi 4（64-bit Raspberry Pi OS）です。Docker ComposeにはMosquitto、sensor-collector、Dashboard、harvest-uploaderを置き、OS権限や物理デバイスに強く依存するものはhost systemdで動作します。

## Gatewayとhost service

- `omk-system-manager.service`: DashboardからのBルート設定、Gateway reboot/shutdown、OMK AP credential参照、USB Nodeセットアップ・再セットアップ、USBデータ書き出し開始を限定APIで仲介する。Bルート専用ではない。
- `data-exporter`: 既存のParquetを読み、CSV/ZIPを生成する。JSONLやParquetを変更せず、data-transformerも起動しない。
- `omk-broute-meter.service`: USBシリアル、PANA認証を要するBルート計測。
- `omk-ble-sensor-manager.service`: BlueZによるBLE探索・登録・受信。
- `omk-data-transformer.timer`: 1時間ごとにJST当日・前日のJSONLを日付partition済みParquetへ変換。
- `omk-dashboard-kiosk.service`: GUI session内で起動する標準のChromium kiosk。ディスプレイがない場合もunitと設定は標準setupで準備される。
- `omk-ichijo-energy-node.service`: Gatewayホストで動作する任意導入の、単一の検証profile向け住宅用PV・蓄電池・PCS ECHONET Lite連携。汎用PCS collectorではない。

DashboardのUSB書き出しはDashboard backendから認証済みsystem-managerを経由して固定の`omk-export-usb`を起動する。system-managerは非rootのまま、mount/unmountだけを限定root helperへ委譲する。helperはbrowserやsystem-managerから任意のdevice pathを受け取らず、自身で対応USBを再検出する。system-managerのfilesystem sandboxを維持するため、helperは`nsenter --mount=/proc/1/ns/mnt`でPID 1のhost mount namespace内に入り、USB検出、mount、unmountを実行する。

system-managerはDashboardの`host.docker.internal`経由の要求をBearer tokenで認証します。ブラウザへhost権限やこのtoken、保存済みBルート認証情報は渡しません。APのSSID/PSKは管理画面の明示的な「表示」操作でブラウザへ返すため、Dashboardの公開先をloopbackとOMK APに限定します。USB Node書込みはsystem-managerの非rootユーザーがdialout権限と固定版esptoolで行い、USBデータ書き出しのmount helperとは分離します。

## 限定的な動作確認済み住宅設備連携

**動作確認は、開発者宅の一条工務店住宅1戸・単一の設備構成に限られます。** 他の住宅・機種・構成での動作は未確認で、太陽光発電・蓄電池・PCSやECHONET Lite対応機器全般に対応する機能ではありません。

| 設備 | 接続方法 | 取得できる値・状態 | 対応上の注意 |
| --- | --- | --- | --- |
| 太陽光発電・蓄電池・PCS設備（上記の確認済み構成） | OMK APとは別に、対象設備と同じローカルネットワークへGatewayを接続 | 太陽光発電電力（W）、蓄電池残量（%）、蓄電池の充電電力・放電電力（W）、蓄電池の運転状態、買電電力・売電電力（W）、PCS交流出力電力（W）、住宅内消費電力（W） | 読み取り専用の任意連携で、OMKの標準構成には含まれません。住宅販売会社・機器メーカーの公式APIではありません。 |

実装と設定は[「ichijo-energy-node」](../../services/ichijo-energy-node/README.md)を参照してください。

## Node、ESP-WIFI-MESH、BLE

共通ESP32 NodeはUSB Serial/JTAG Provisioning、ESP-WIFI-MESH、Wi-Fi/IP/MQTT、SEN66などのI2Cセンサ、BLE relayを同時に扱います。SEN66が未接続でもBLE relayとして利用でき、SEN66とBLE relayを接続したNodeも同じfirmwareで動作します。production対象はAtomS3 Liteです。初回登録に物理ボタン操作は必要ありません。

保存済みGateway SSID/PSKを使ってESP-WIFI-MESHを自動形成する。topologyはrootを頂点に各childがparentへ接続するtreeであり、全Nodeが相互に直接通信する構成ではない。Nodeごとのparent、root、SSID、IPの手動指定は行わない。rootはGateway APへ通常STA接続し、childはMesh parent経由のinternal IP networkへDHCP接続する。rootはinternal subnet (`10.0.0.1/16`) のDHCP/DNS/NAPTを提供するため、root/childのどちらも通常TCPのMQTTで`192.168.50.1:1883`へ到達できる。

Nodeは計測・BLE relay・Mesh中継を兼ねる。配置と電波条件に応じてroot/parent/childは自動選択され、parentまたはrootを失うとMeshが再構成される。Gatewayは通常のAPとMosquittoだけを提供し、専用Mesh daemonや独自relay protocolを必要としない。市販Wi-Fi中継機は必須ではないが、到達性はNode配置、壁、階層、RSSIに依存する。AC電源を前提とし、電池駆動の省電力Meshとしては設計しない。

SwitchBot BLE sensorはGateway direct BLEを主系とし、ESP32 Node raw relayをfallbackにします。Nodeはactive scanでADVとScan Responseを取得してGateway decoderへ渡し、directが30秒以上途絶した場合だけrelayのデータを通常のsensor topicへpublishします。direct復帰時は同値でも最初のdirectから戻ります。BLEアドバタイズ単位の厳密dedupより、1分集約用途の経路冗長化を優先します。詳細な入力topicと選択理由は[データ経路とMQTT](data-and-mqtt.md)および[decision](../decisions/ble-direct-relay-route-selection.md)を参照してください。

Mesh診断status、credential導出、再構成時の観測上の注意は[ESP-WIFI-MESH Node networking decision](../decisions/esp-wifi-mesh-node-networking.md)に記載しています。

## 保存・表示・送信

`sensor-collector`は`omk/#`を購読してJSONLへ一次保存し、generic latest storeと互換latest JSONを更新します。Dashboardはlatest JSONから瞬時値を、DuckDBのメモリ内接続でParquetから日計を読み、表示設定を`data/dashboard/settings.json`へ保存します。`data-exporter`は保存済みParquetをCSV/ZIPとして書き出す別経路であり、CSVを一次保存形式として扱いません。`harvest-uploader`はJSONLやParquetを読まず、MQTTを別clientとして直接購読し1分集約します。確定した送信レコードは`data/harvest-uploader/queue.sqlite3`へ保存し、送信成功後に削除します。SQLiteはこのoutbox用で、Dashboardや計測履歴のDBではありません。

MQTT topic、payload、保存形式は[データ経路とMQTT](data-and-mqtt.md)で定義します。OMK APの隔離とDocker公開ポートの扱いは[ネットワーク設計](networking.md)を参照してください。

## セキュリティ境界

USB書き出しの権限境界は`Browser → Dashboard backend → authenticated system-manager → fixed USB export command → narrow root helper`です。Browserへsystem-manager token、root権限、device path指定能力を渡しません。

OMK AP clientはGatewayのローカルサービスと公開MQTT/Dashboardへ接続できますが、Internetへは転送されません。MQTTは現在OMK専用LAN内の匿名・平文接続です。認証、ACL、TLSは未実装の将来課題です。

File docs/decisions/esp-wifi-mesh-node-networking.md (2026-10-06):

# ESP-WIFI-MESHを共通Nodeの通信層として採用

- **決定日:** 2026-08-20
- **ステータス:** 採用
- **production対象:** AtomS3 Lite

## 決定

共通Node firmwareの通信層としてESP-WIFI-MESH internal IP networking/NAPTを採用する。1台のNodeはSEN66計測、BLE scan/SwitchBot relay、Mesh中継、通常TCP MQTT publishを同時に担う。root/parent/childは固定せず、保存済みGateway SSID/PSKを共通入力としてMeshが自動選択・自動再構成する。

Meshはrootを頂点とするtree topologyであり、各childはparentを経由する。rootはGateway APへ通常STA接続し、internal subnet `10.0.0.1/16`のDHCP/DNS/NAPTを提供する。childはMesh parent経由でDHCP接続し、rootのNAPTを通じて`mqtt://192.168.50.1:1883`へ通常TCP接続する。Gatewayには特別なMesh daemon、routing daemon、独自relay protocolを追加しない。市販Wi-Fi中継機は必須にしない。NodeはAC電源前提である。

## credential導出

Mesh IDとMesh AP passwordはsource固定値、NVSの別平文値、Node固有値ではない。保存済みGateway credentialから次の固定バイト列をSHA-256へ入力してruntime導出する。

```text
SHA-256("OMK-MESH-ID-v1" || NUL || SSID bytes || NUL || PSK bytes)[0:6]
SHA-256("OMK-MESH-PSK-v1" || NUL || SSID bytes || NUL || PSK bytes)[0:16]
```

`NUL`は1 byteの`0x00`を表す。後者の16 byteはlowercase hex 32文字をMesh AP passwordとして使う。SSID、PSK、hash入力、導出値はログへ出さない。決定的な非秘密test vectorをfirmwareとhost pytestで検証する。

Gateway SSID/PSKはNVS namespace `omk_net`、key `gw_cred`のversioned recordとしてread-back検証付きで保存する。これはESP-WIFI-MESHがroot router接続やchild parent接続に使うruntime `WIFI_IF_STA` configurationと意図的に分離する。新recordがない旧Nodeは、legacy STA configがBSSID固定でなく、かつ既定Mesh内部AP名でもない場合だけ一度移行する。内部parent stateまたは判定不能な値は移行せず、USB再Provisioningを要求する。

この安全側migrationでは、credential分離版へ更新した既存NodeにUSB再Provisioningが必要になる場合がある。特にMesh runtimeが旧`WIFI_IF_STA`へ親Nodeの内部AP情報を書いた後は、その値をGateway credentialとして採用しない。GatewayへNodeをUSB接続して次を実行し、`USB provisioning confirmed for node_id=...`を確認する。

```bash
python3 scripts/provision_omk_node_via_usb.py --device /dev/ttyACM0 --profile omk-ap
```

この復旧手順はNodeの物理ボタン操作やUSB抜き差しを通常のreboot手段として要求しない。

## 診断と運用上の解釈

diagnostic topicと全fieldは[データ経路とMQTT仕様](../developer/data-and-mqtt.md#mesh診断status)で定義する。`parent_disconnect_count`はraw Mesh event回数であり、利用者が知覚する通信断回数ではない。起動やtopology再構成時に複数回増加してよい。`mesh_layer=-1`や旧parent BSSIDなどのtransient観測値も起こり得る。parent切断時のcurrent IPは`0.0.0.0`へclearする。現行BLE managerのNode online判定はDiscovery BLE、raw relay、SEN66の受信鮮度を使い、このMesh診断topicによるstabilization判定は実装していない。

Mesh/MQTTの復旧判断は、全Node共通の`mesh_recovery.c`に集約する。MQTT-onlyの180秒liveness条件は維持し、parent lossと共通の永続restart budgetを使う（下記）。rootlessはtreeにrootがない状態であり、ローカルparentのSTA切断とは別に保持する。

実住宅試験では、同一SSID・異BSSIDのGateway／市販Wi-Fi中継機が同時に見える環境で、別root/treeが形成されるリスクを確認した。また、非同期起動やNode移設後に最適rootへ自動復帰するとは限らない。採用当初は診断収集を先行したが、現在は下記の2段階root recoveryを実装している。市販中継機との併用や配置ごとの最適性は引き続き実機評価対象である。

WPA2暗号化Mesh APのassociation expiryはESP-IDFの推奨に従い30秒とする。router BSSIDの固定やmanual parent選択は行わない。同一Meshの複数root競合は`esp_mesh_allow_root_conflicts(false)`で無効化している。

## 標準parent selection・RSSI policy（2026-10-06）

最優先はSEN66/BLEの長期データ到達性である。ESP-WIFI-MESH標準のpreferred parent選択は候補の浅いlayerを優先し、同じlayerではchild数の少ない候補を優先する。OMK独自の最小layer最適化は追加しない。候補にRSSI thresholdがあることと、`mesh_rssi_threshold_t.low`が厳密な候補足切り値であることは同義ではない。ローカルheaderが説明するhigh/medium/lowはparent間のRSSI range比較と継続的なweak RSSI通知の境界である。

AtomS3 Liteを含めhigh/medium/lowをESP-IDF標準の **−78/−82/−85 dBm** に統一する。Atom固有の−78/−80/−82を廃止し、実住宅で通信できた−84〜−85 dBm付近を過度に厳しく扱わない。これは任意の−85 dBmリンクの採用・維持を保証しない。

### IDF 6.0.1で確認したAPIと確認限界

実装前にローカル`framework-espidf/version.txt`、`components/esp_wifi/include/{esp_mesh.h,esp_mesh_internal.h}`、`examples/mesh/{ip_internal_network,internal_communication,manual_networking}/main/mesh_main.c`を確認した。Mesh実装は`components/esp_wifi/lib/esp32s3/libmesh.a`のbinary配布で、parent switching内部sourceは含まれない。公開header・exampleと[同版の公式self-organized networking仕様](https://docs.espressif.com/projects/esp-idf/en/v6.0.1/esp32s3/api-reference/network/esp-wifi-mesh.html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)を根拠とする。

| API・型・event | 確認した意味／今回の扱い |
| --- | --- |
| `mesh_switch_parent_t.duration_ms` | parentの弱RSSI監視時間。継続すると新parentを探索する |
| `cnx_rssi` | parent接続のRSSI閾値。−120 dBmより大きい設定で監視timerがarmされる |
| `select_rssi` / `switch_rssi` / `backoff_rssi` | headerはそれぞれ選択閾値／切断・切替閾値／root接続閾値と説明し、`select_rssi > switch_rssi`を要求する。ただし改善幅や内部相互作用・全制約は確定できない |
| `esp_mesh_get_switch_parent_paras()` / `esp_mesh_set_switch_parent_paras()` | read/set APIは存在するが、数値defaultの公開定義はない。setterは使わず、Mesh start後に全fieldとself-organized状態をread-back/loggingする。実機を操作しない今回、実測runtime defaultは未取得 |
| `esp_mesh_set_rssi_threshold()` | headerに標準−78/−82/−85が明記されている。設定後read-backする |
| `esp_mesh_set_self_organized(true, true)` | non-rootはpreferred parentを選び直す。接続済みなら一度切断する。rootはrouterとchildを切断しroot roleを放棄する |
| `esp_mesh_set_self_organized(true, false)` + `esp_mesh_connect()` | root roleを維持してrouterへ再接続する公式手順。前段が失敗したらconnectは呼ばない |
| `PARENT_CONNECTED` / `PARENT_DISCONNECTED` | ローカルSTA parentの接続／切断。rootではrouter。切断payloadは`wifi_event_sta_disconnected_t`のalias |
| `NETWORK_STATE` | `mesh_event_network_state_t.is_rootless`。rootless解除をSTA再接続eventの代用にしない |
| `NO_PARENT_FOUND` | `mesh_event_no_parent_found_t.scan_times`。回数・最後のscan_times・孤立中の理由を記録する。eventごとに猶予timerを延長しない |
| `STOP_RECONNECTION` | headerはrootのrouter再接続／non-rootのparent再接続停止と定義する。exampleはログのみで、詳細な発生条件はbinary内のため未確定。回数・孤立中の理由を記録し、接続状態と経過時間と併用する。単独eventで切断扱い・再起動しない |

self-organized networkingは標準で有効で、root選択・preferred parent選択・再接続を担当する。OMKでswitchパラメータを設定していなかったことは、標準parent switching無効の根拠にはならない。−82 dBm前後・30〜60秒・明確な改善幅という独自hysteresis設定は、今回の情報だけでは安全に定義できないため採用せず、runtime値を維持する。標準動作と同じ周期の探索をOMKで追加しない。

manual networking、`esp_mesh_set_parent()`、applicationからのWi-Fi scan/connect/disconnectは追加しない。独自parent選択にはscan制御、layer、loop防止、child capacity、root整合、self-organizedとの排他まで必要になる。実住宅評価後も不足する場合に限りPhase 2としてparent scoringを検討する。

## 全Nodeのparent-loss recoveryとbounded restart

30秒のstatus周期で`mesh_recovery.c`が1つのactionを選ぶ。Mesh/IP eventと周期処理をdefault event loopへ直列化し、timer callbackはeventをpostするだけにする。切断・rootless・IP lossも観測へ渡し、周期間の短い断絶で正常継続時間が誤って繋がらないようにする。MQTTはdisconnect counterの変化も見る。

- `healthy`: Mesh起動済み、parent接続、非rootless、有効IP、MQTT接続。parentだけ戻った場合は`wait_ip`または`mqtt_wait`であり、正常扱いしない。
- `self_healing`: 起動後parent未接続、parent切断、rootlessで開始。短い断絶ではOMKからAPIを呼ばない。parent接続かつ非rootlessでloss timerとexplicit状態をclearする。
- `explicit`: 猶予後、non-rootは`true,true`、router未接続rootは`true,false`＋`connect()`。rootがrouterに接続したままrootless通知を受けた場合はroleを放棄しない。実行直前にもrole・接続状態を確認する。
- `restart_pending` / `budget_hold`: 下表の時間と成功したexplicit要求が揃った場合のみrestart候補になる。budget消費済みなら再起動せず低頻度の再選択を継続する。APIが失敗し続けて要求を受け付けられない場合もrestartしない。

| 条件 | 時間 | 選定理由 |
| --- | --- | --- |
| self-healing猶予 | 120秒＋ID jitter 0〜60秒 | 短い断絶・標準再構成を待つ |
| explicit成功後の次回探索 | 300秒＋同0〜60秒 | 探索を繰り返して収束を妨げない |
| parent/rootless restart | 孤立600秒＋ID jitter 0〜120秒、かつ最後のexplicit成功後180秒以上 | 再選択に十分な猶予を与えた最終fallback |
| budget消費後 | 300秒＋同0〜60秒で探索。API失敗でも同間隔 | 届かないNodeでもrestart loopやAPI stormを起こさない |
| budget回復 | `healthy`が900秒連続 | root recoveryの15分cooldownと揃え、一時復帰では再armしない |
| MQTT-only | 既存の適格条件で180秒＋ID jitter 0〜120秒 | broker断時にも同時再起動を減らす |
| 未受付API失敗 | 次のstatus周期で再試行 | 成功時のgrace/cooldownを誤って消費しない |

時刻はunsigned差分で32-bit ms wrapを扱う。ID全byteのhashからjitterを決定し、全Nodeを同じtimeoutで再起動させない。hash衝突や30秒周期への丸めによる同時動作の可能性は残る。event起点の判定からactionまでは最大1 status周期が加わり、起動時未接続は最初の周期で観測する。

NVS `omk_recovery/budget_v1`の単一versioned blobに、消費済みflag・累積restart予約回数・最後の理由を保存する。**commit後にhandleを開き直してread-back一致した場合だけ** `esp_restart()`へ進む。NVS open/read/format/write/commit/read-back失敗はrestartを禁止し、RAM budgetも閉じる。初回のkey未作成だけを新規budgetと扱う。再起動直前に電源断しても、markerが永続化済みならbudgetは消費したままとなる（予約回数と実際のsoftware reset回数はこの境界で一致しない場合がある）。

parent lossとMQTT-onlyは同じbudgetを消費する。再起動、role変更、短いparent/MQTT復帰、理由の変化ではbudgetを回復しない。900秒正常継続後、NVSへのclear・read-backが成功して初めて次episodeの1回を許可する。再起動後も孤立なら同episodeのまま探索を継続する。NVS初期化・factory eraseはこの保証の範囲外であり、自動recoveryではNVSを消去しない。

優先順位は **parent/rootless → weak-root Level 2 → root Level 1 → MQTT-only**。上位の猶予中も下位へfall-throughしない。root router再接続の2 APIは1つのactionとして扱い、失敗時も同じ周期に別actionを呼ばない。budgetの再armもこのarbiterで行う。

## 既存2段階root recoveryとの統合

`mesh_root_recovery.c`は、30秒ごとのstatus処理でGatewayリンクを観測し、次の2段階を同じ制御経路から選択する。実行時にもroot・parent接続済み・rootlessでないことを確認する。

- **Level 1: root再選挙。** rootでの`MESH_EVENT_ROUTING_TABLE_ADD`後に60秒の安定待ちを置く。待機中の追加参加は待ち時間を延長する。また、rootの有効RSSIが−80 dBm以下で、前回観測からの増分が「parent切断3回以上」または「MQTT切断2回以上」の場合も要求する。`esp_mesh_waive_root(NULL, MESH_VOTE_REASON_ROOT_INITIATED)`で、より良いroot候補への交代を試みる。候補がなければ現在のrootが残るため、この段階では弱RSSIだけを理由に投票しない。API成功後はLevel 1に15分のcooldownを置く。
- **Level 2: root放棄とparent再探索。** rootかつRSSI validかつGateway RSSIが−85 dBm以下の観測が180秒継続した場合、`esp_mesh_set_self_organized(true, true)`を呼ぶ。ESP-IDF 6.0.1ではrootがrouterおよびchildとの接続を解除し、root roleを放棄して通常Nodeとしてpreferred parentを探索する。parentの選択はESP-WIFI-MESHへ任せ、OMKによるparent固定や独自の周辺RSSI scanは行わない。短時間の切断回数やLevel 1の実行有無は、この段階の必須条件にしない。

Level 2の継続時間とcooldownはLevel 1と分離する。Level 1を実行しても継続時間はリセットせず、たとえば最初の弱RSSI観測を`t=0`として、`t=30秒`のLevel 1後もroot／−89 dBmのままなら`t=180秒`でLevel 2へ進める。RSSIが−85 dBmより改善、non-root化、RSSI invalidのいずれかをstatus処理で観測すると継続時間をリセットする。最初の該当観測から180秒を数えるため、物理的な劣化開始からの遅れには最大1 status周期が加わる。

同じ周期で両段階が成立した場合はLevel 2を優先し、API失敗時にも同じ周期でLevel 1を続けて呼ばない。Level 2成功後は専用の15分cooldownへ入り、継続時間と未実行のLevel 1要求をリセットし、Level 1にも15分のcooldownを適用して再構成を保護する。cooldown中もリンク観測を続け、終了時に再び180秒の継続条件を満たしていれば再実行できる。Level 2 API失敗では成功時刻・cooldown・graceを更新せず、条件が続けば次の30秒周期で再試行する。時刻比較は`uint32_t`のwrapを考慮する。

どちらのAPI成功後も120秒はparent-loss actionとMQTT-only restartを抑止する。通常通信条件が失われればliveness計測をリセットし、grace後も上記の共通budget・jitterを通してのみrestartを許可する。APIの`ESP_OK`は回復要求の成功として扱い、実際のroot交代・parent接続・MQTT復旧の完了を意味しない。

Level 1は`root reelection requested/executed: ... (level=1)`、Level 2は`root recovery requested: sustained_weak_root (level=2)`と`root parent reselection executed: sustained_weak_root (level=2)`で区別する。失敗時は理由と`esp_err_to_name()`によるESP-IDF errorを記録する。既存`omk/node/<node_id>/status`の1152-byte上限とfieldを維持し、追加診断は30秒周期の`omk/node/<node_id>/mesh_recovery/status`（768-byte buffer、QoS 0、非retain）へ分ける。stage、最後の理由、no-parent/stop/reselection回数、scan_times、loss秒数、budget、永続restart予約回数と理由を送る。孤立中はGatewayへ送れないため、復帰後のstatusとbootを跨ぐrestart理由を併用する。data-transformerはこのtopicをstatusとして扱い、計測変換エラーにしない。

[ESP-IDF 6.0.1のself-organized networking仕様](https://docs.espressif.com/projects/esp-idf/en/v6.0.1/esp32s3/api-reference/network/esp-wifi-mesh.html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)と同版の`esp_mesh.h`の型・利用条件に基づく。特定treeへの統合や最適rootへの交代を保証するものではない。root conflicts無効化と最大layerは維持し、Atom固有RSSI閾値は今回標準値へ戻した。下記の過去のフェイルオーバー試験と、この追加policyの実機検証は区別する。継続時間のリセット、段階間の優先順位、API失敗、cooldown、liveness grace、時刻wrapはhost testで確認する。実機では弱rootとそのchildの再接続、既存treeへの統合可否、MQTT／SEN66／BLE relay復旧、15分以内の再探索抑止を確認する。

## 今回の根拠と未検証範囲

実住宅でroot `09dda0d5a8f2` → layer2 `55f94c790e12` → layer3 `9490b46aee0d`（`sen66-002`）が成立し、前者リンクが約−84〜−85、後者が約−63〜−65 dBmだったという報告を入力とする。後に後二者が消失し、layer2物理再起動後も2分超復帰せず、別のroot/childは通信継続した。

コードから確定できるのは、旧livenessが`parent_connected=true`を要し、parent未接続の長期孤立を処理しなかったこと、Atom profileが標準より厳しかったこと、旧MQTT restartに永続budgetがなかったことである。実際の切断trigger、候補不足、scan/reconnect停止、別tree形成、IP/NAPT停滞のいずれが原因かは、報告だけでは確定しない。今回のpolicy・時間定数・parent switching runtime値は実機未検証であり、以下の過去確認済み項目からその効果を推定しない。

host testは短い断絶、起動時孤立、再選択成功／失敗、同episodeの再起動抑止、NVS障害と複数boot、正常900秒の再arm、途中のIP/parent/rootless/MQTT断、role変更、Level 1/2/MQTT排他、event連発、ms wrap、ID jitter、実際のdiagnostic formatter容量を対象とする。NVS実デバイスでの電源断耐性やRF挙動はhost stubだけでは検証できない。

次回の最小実機確認は、起動時のRSSI/switch read-back、短いparent断で無介入、長いparent断とGateway/router断でAPI分岐が正しいこと、圏外継続でboot_countが1回だけ増加すること、復帰後のMQTT/SEN66/BLEのデータ受信と900秒後のbudget回復である。MQTT-onlyのbroker断も共通budgetで最大1回となることを確認する。新しい良好なparentの存在・別tree統合・無欠測は保証しない。parent接続済みかつ非rootlessのままIP未取得だけが永久に続くケースは`wait_ip`として診断し、この変更では新たなDHCP再起動policyを追加しない。

## 実機確認済み範囲

- AtomS3 Lite単体のroot/layer 1、Gateway MQTT、30秒status publish
- BLE relayとMesh/MQTTの同時動作
- SEN66、BLE relay、Mesh/MQTTの同時動作
- AtomS3 Lite 2台のroot/layer 1とchild/layer 2
- 遠方layer 2から約10秒周期のSEN66とBLE relay同時publish
- layer 2 RSSI約`-75`〜`-77 dBm`での継続通信

AtomS3 Lite 2台で、root/layer 1とchild/layer 2、childからのSEN66約10秒周期publish、registration status/ack、BLE relay、Mesh/MQTTの並行動作を確認した。root/child役割、MAC、IPアドレスは固定割当仕様ではない。既存Nodeでcredential分離用のNVS recordがない場合は、USB provisioningで`omk_net/gw_cred`を保存してから接続する。

### Gateway AP一時消失後の自動復旧

Gateway APの一時消失・復帰後も、root external STAはDHCP、IPv4、MQTTを自動再確立することを確認済みの採用要件とする。root/parent/childの固定、特定MACへの依存、固定IP割当をこの要件の実現方法にしない。childのinternal DHCPとrootのDHCP/DNS/NAPT経路は維持する。

root parent再接続時は`esp_netif_action_connected()`でnetifをupにし、DHCP clientを開始する。parent disconnect時にはdiagnostic statusのcurrent IPを`0.0.0.0`相当にclearする。Gateway APの一時消失・復帰後、rootのDHCP、IPv4、MQTT、SEN66 publish、BLE relay publishが自動復帰することをAtomS3 Lite 2台で確認した。Node再起動、USB操作、手動再Provisioningは不要である。

検討したnon-rootからraw Mesh application packetでrootへ送りMQTT relayする方式は採用しない。Espressif `ip_internal_network`方式でchildが通常LwIP/TCP/IPとESP-MQTTを使う構成が実機で成立したためである。

## 初期検証から移管した知見

初期検証から得た必要な知見、すなわちdefault STA netifをWi-Fi初期化前に作る順序、`esp_mesh_start()`成功後のreceive task開始、childからrootへの`MESH_PROTO_AP`/`MESH_DATA_TODS` frame転送、rootからchildへの`MESH_PROTO_STA` frame転送、root外部IP取得後のinternal DHCP/DNS/NAPT開始は`firmware/esp32/omk-node/`へ移植済みで、host testで重要な順序とframe経路を回帰確認する。

routing-table配布、button入力、`/topic/ip_mesh` demo publish、固定Mesh credentialを含む実験固有処理は本番要件ではなく、移植しない。本番仕様は`firmware/esp32/omk-node/`とこのdecisionに記載する。

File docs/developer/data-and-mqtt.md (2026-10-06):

# データ経路とMQTT仕様

MQTTは、各データ取得処理をRaspberry Piへ集約するLAN内の内部データバスである。ESP32などのセンサノードはOMK専用Wi-Fi経由で`192.168.50.1:1883`へ送信し、クラウドへ直接接続しない。Composeはbrokerを`127.0.0.1:1883`だけへ公開し、`wlan0`にbindしたsystemd socket proxyがAP clientの接続を中継する。Gateway上のhost serviceは`127.0.0.1:1883`を使用する。

現行の主経路は、センサ・Bルート・パワコン・BLEからMQTT、`sensor-collector`、JSONL、`data-transformer`、processed Parquet、Dashboardです。`harvest-uploader`は別clientとしてMQTTを直接購読し、JSONLやParquetを読まずに1分集約してSORACOM Harvestへ送信します。

## トピックとdevice_id

`device_id`は測定元を識別する論理設定値である。SEN66ではNodeの`logical_id`、BLEではregistryの`sensor_id`、Bルート・Ichijoでは各サービスの設定値を使う。物理Nodeの`node_id`やBLEの`device_key`とは区別する。測定トピックは`omk/<device_id>/<data_type>`を基本とする。OMK Nodeの登録状態は、eFuse由来の`node_id`を使う専用のregistration topicで通知する。

| 用途 | トピック | QoS | retain |
| --- | --- | --- | --- |
| Bルート瞬時電力 | `omk/<device_id>/power` | 0 | false |
| Bルート積算電力量 | `omk/<device_id>/cumulative-energy` | 0 | false |
| Bルート30分電力量 | `omk/<device_id>/interval-energy` | 0 | false |
| Ichijo電力フロー | `omk/<device_id>/power-flow` | 0 | false |
| Bルート・Ichijo可用性 | `omk/<device_id>/status` | 0 | true |
| Node登録設定 | `omk/node/<node_id>/registration/config` | 1 | 登録/変更はfalse、解除はtrue |
| Node登録ACK | `omk/node/<node_id>/registration/ack` | 1 | true |
| Node raw BLE relay | `omk-relay/<relay_node_id>/ble/raw` | 0 | false |
| SEN66測定値 | `omk/<device_id>/sen66` | 0 | false |
| 論理device可用性 | `omk/<logical_id>/status` | 0 | true |
| OMK Node登録状態 | `omk/node/<node_id>/registration/status` | 1 | true |
| OMK Node Mesh診断 | `omk/node/<node_id>/status` | 0 | false |
| BLE環境センサ | `omk/<sensor_id>/environment` | 0 | false |
| BLE人感状態変化 | `omk/<sensor_id>/motion` | 0 | false |
| BLE開閉状態変化 | `omk/<sensor_id>/contact` | 0 | false |
| BLEプラグ電力 | `omk/<sensor_id>/power` | 0 | false |

表のQoSはpublisher側の設定である。Bルート・Ichijoがそれぞれの測定値と可用性を、NodeがSEN66・可用性・registration status/ack・Mesh診断・raw relayをpublishする。BLE Sensor Managerはraw relayをdecodeして通常のBLE測定値をpublishし、Nodeへのregistration configも送信する。Nodeは自分のconfigをQoS 1で購読する。BLE Sensor Managerはregistration status/ackをQoS 1、SEN66とraw relayをQoS 0で購読し、Node registryと受信鮮度を更新する。

collectorとHarvestは`omk/#`をQoS 0で購読する。collectorは管理メッセージもJSONLへ保存するが、transformerは管理topicをParquetから除外し、Harvestも測定対象以外を集約しない。USB provisioningの完了確認も対象Nodeのregistration statusを使用する。

SEN66測定トピックの例は`omk/sen66-001/sen66`である。

登録済みOMK NodeはMQTT接続時に`omk/<logical_id>/status`へretain付きで`online`を送信する。予期しないMQTT切断時は同一topicのretain付きLast Will`offline`がbrokerから送信される。これはlogical deviceのMQTT到達性であり、SEN66など個別測定値の鮮度は最新telemetryのGateway受信時刻で判定する。したがって復旧後の接続時`online`が古いretained `offline`を必ず上書きする。

## Payload

### Bルート・Ichijo

Bルートpayloadはすべて`device_id`を持ち、次のfieldを送る。

| data type | 時刻field | 測定field・品質 |
| --- | --- | --- |
| `power` | `measured_at` | `net_power_w`（買電が正、売電が負） |
| `cumulative-energy` | `metered_at`、`received_at` | `cumulative_energy_import_kwh`、`cumulative_energy_export_kwh` |
| `interval-energy` | `start_at`、`end_at` | `import_energy_kwh`、`export_energy_kwh`、`quality_status` |

時刻はoffset付きISO 8601。積算payloadの`received_at`はBルート取得側の時刻で、collectorの外側の`received_at`とは別である。30分値は正常時`quality_status=normal`、逆方向非対応時は`reverse_not_supported`で売電量が`null`となる。前回値なし・非30分間隔・負の積算差分では30分値自体を生成・publishしない。瞬時・積算payloadには`quality`や`source`を付けない。

Ichijoの`power-flow`は取得サイクル終了時の`measured_at`、PV・系統・蓄電池・PCS・負荷の値、`quality`（`normal`/`degraded`）、`errors`を持つ。取得失敗は`null`で保持する。全fieldとJSON例は[Ichijo README](../../services/ichijo-energy-node/README.md#mqtt)を参照する。Bルート・Ichijoの可用性payloadは`device_id`と`status`（`online`/`offline`）を持ち、Ichijoだけが`timestamp`も付ける。statusは接続時・正常終了時・Last Will用で、計測時刻や品質の代わりにはならない。

### SEN66・Node登録

測定値はSEN66の取得成功時に送信する。未取得値は非標準の`NaN`ではなくJSONの`null`にする。ESP32は時刻同期をしていないため`measured_at`を含めず、sensor-collectorが付与するGateway受信時刻`received_at`を保存・集計に使用する。

```json
{"device_id":"sen66-001","uptime_ms":123456,"pm1_0_ug_m3":4.1,"pm2_5_ug_m3":6.8,"pm4_0_ug_m3":8.2,"pm10_0_ug_m3":10.5,"relative_humidity_percent":48.2,"temperature_celsius":25.3,"voc_index":92.0,"nox_index":null,"co2_ppm":612.0}
```

`harvest-uploader`はSEN66のtopic中のLogical IDをHarvest field prefixに使う。たとえば`omk/sen66-001/sen66`は`sen66-001_temperature_c`と`sen66-001_co2_ppm`を生成し、`omk/sen66-002/sen66`は別の`sen66-002_temperature_c`と`sen66-002_co2_ppm`を生成する。複数SEN66の1分平均は相互に混合しない。

OMK NodeはMQTT接続後と登録変更時に、QoS 1・retain付きでregistration statusを送信する。登録済みの場合はNodeのNVSから読んだ`logical_id`を含める。

```json
{"protocol_version":1,"node_id":"112233445566","registration_state":"registered","logical_id":"sen66-001","capabilities":3,"connected_sensors":["sen66"]}
```

新品Gatewayは、このstatusだけからNode registryのLogical IDを復元できる。旧Gatewayのregistryやretained ACKは不要。GatewayはIDの形式（1〜48文字のASCII英数字・`-`・`_`）と、他Nodeの確定済み・要求中IDとの重複を検証する。既存のprotocol version、capabilities、connected sensors、registration state、status受信時刻も保存する。

旧firmwareの`logical_id`を含まないregistered statusも受理し、Gatewayに保存済みのIDは消さない。明示的な`provisioned` statusは登録情報を解除する。firmwareはこの状態で`logical_id`を出力しない。Gatewayで解除済みの登録は、古いretained statusでは復活させない。

登録・変更要求のconfigは`{"protocol_version":1,"logical_id":"sen66-001"}`、解除要求は`{"protocol_version":1,"logical_id":null}`である。登録ACKは`protocol_version`、`node_id`、`logical_id`、`registration_state: "registered"`を持つ。解除成功時はretained config/ackを空payloadで消去し、`provisioned` statusを送る。SEN66の診断情報がある場合、registration statusには`sen66_rc`（recovery総数）と`sen66_to`（liveness timeout数）も加わる。

`registration/ack`は引き続き設定要求への応答であり、単なるMQTT再接続では送らない。GatewayからのID変更要求が進行中の場合は、従来どおり対応するACKで現在値を確定する。retained registration status自体はNodeのonline判定には使わない。

### Mesh診断status

ESP-WIFI-MESH Nodeは30秒ごとに非retainの診断statusを送信する。

```text
omk/node/<node_id>/status
```

```json
{"node_id":"112233445566","mesh_layer":2,"is_root":false,"parent_bssid":"02:00:00:00:00:01","rssi_dbm":-76,"rssi_valid":true,"ip":"10.0.0.2","parent_change_count":0,"parent_disconnect_count":2,"is_rootless":false,"rootless_duration_s":0,"last_parent_disconnect_reason":201,"last_wifi_disconnect_reason":201,"root_switch_count":0,"mqtt_disconnect_count":1,"mqtt_connected":true,"mqtt_disconnected_duration_s":0,"mqtt_last_connected_uptime_s":123,"mesh_rx_success_count":456,"mesh_tx_success_count":78,"mesh_tx_failure_count":0,"mesh_last_rx_success_uptime_s":122,"mesh_last_tx_success_uptime_s":123,"uptime_s":123,"free_heap_bytes":223000,"minimum_free_heap_bytes":180000,"reset_reason":"poweron","reset_reason_code":1,"boot_count":4,"last_omk_restart_reason":"none","mesh_mqtt_liveness_restart_count":0}
```

| Field | 意味 |
| --- | --- |
| `node_id` | eFuse由来の12桁Node ID |
| `mesh_layer` | ESP-WIFI-MESH layer。transition中は`-1`になり得る |
| `is_root` | 観測時点のroot状態 |
| `parent_bssid` | 観測済みparent BSSID。transition中は旧値が残り得る |
| `rssi_dbm` / `rssi_valid` | STA接続先RSSIと取得可否。取得失敗時は`rssi_valid=false` |
| `ip` | 現在のSTA/internal-network IPv4。parent切断時は`0.0.0.0`へclearし、IP再取得時に更新する |
| `parent_change_count` | 前回と異なるparent BSSIDへの接続回数 |
| `parent_disconnect_count` | raw `MESH_EVENT_PARENT_DISCONNECTED` 回数 |
| `is_rootless` | `MESH_EVENT_NETWORK_STATE`が示す、現在のMesh networkにrootがいない状態 |
| `rootless_duration_s` | rootless状態の継続秒数。rootまたはparent接続成立時は0 |
| `last_parent_disconnect_reason` | 最後の`MESH_EVENT_PARENT_DISCONNECTED`のWi-Fi reason。未取得時は`0` |
| `last_wifi_disconnect_reason` | 最後のMesh管理STA切断reason。`MESH_EVENT_PARENT_DISCONNECTED` payloadから取得し、`201`は`WIFI_REASON_NO_AP_FOUND`。未取得時は`0` |
| `root_switch_count` | 初期root選出を除く、Node自身のroot role変化回数。同一transitionの重複eventは数えない |
| `mqtt_disconnect_count` | `MQTT_EVENT_DISCONNECTED` 回数 |
| `mqtt_connected` | status生成時点でMQTT brokerへ接続中か |
| `mqtt_disconnected_duration_s` | MQTT client開始後、現在の未接続状態が継続している秒数。接続中は0 |
| `mqtt_last_connected_uptime_s` | 最後にMQTT接続が成立した時点のNode uptime秒。一度も接続していない場合は0 |
| `mesh_rx_success_count` | Mesh internal networkで正常受信したpacketの累積数 |
| `mesh_tx_success_count` | `esp_mesh_send()`成功の累積数 |
| `mesh_tx_failure_count` | `esp_mesh_send()`失敗の累積数 |
| `mesh_last_rx_success_uptime_s` | 最後にMesh受信成功した時点のuptime秒 |
| `mesh_last_tx_success_uptime_s` | 最後にMesh送信成功した時点のuptime秒 |
| `uptime_s` | boot後秒数 |
| `free_heap_bytes` | 観測時点のfree heap |
| `minimum_free_heap_bytes` | boot後の最小free heap |
| `reset_reason` / `reset_reason_code` | ESP reset reasonの名前とコード |
| `boot_count` | NVSに保持するboot回数 |
| `last_omk_restart_reason` | OMK自身が意図的にsoftware restartした直近理由。liveness timeout時は`mesh_mqtt_liveness_timeout` |
| `mesh_mqtt_liveness_restart_count` | Mesh/MQTT liveness timeoutによるsoftware restart累積回数。NVSに保持する |

`parent_disconnect_count`と`mqtt_disconnect_count`は障害回数ではない。起動とtopology再構成の1回の事象で複数回増え得る。Dashboardや監視は単発のcounterで異常判定せず、MQTT接続状態、継続時間、計測欠測などを組み合わせて扱う。

Mesh/MQTT recoveryのpolicyは[networking decision](../decisions/esp-wifi-mesh-node-networking.md#全nodeのparent-loss-recoveryとbounded-restart)で定義する。MQTT-onlyはMesh起動・parent接続・非rootless・有効IP・MQTT開始済み・MQTT未接続が180秒＋Node ID jitter（0〜120秒）続いた場合の最終fallbackとする。parent-lossと共有するNVS budgetはepisode中1回だけ消費可能で、15分の正常継続後だけ回復する。従来の`last_omk_restart_reason`とMQTT restart countも継続する。

追加の復旧診断は`omk/node/<node_id>/mesh_recovery/status`へ30秒周期、QoS 0、非retainで送る。既存Node statusは1152-byte bufferを維持し、追加topicは768-byte bufferに収める。両方に`node_id`と`uptime_s`を含む。

| field | 意味 |
| --- | --- |
| `recovery_stage` | `idle` / `healthy` / `self_healing` / `explicit` / `wait_ip` / `mqtt_wait` / `budget_hold` / `restart_pending` |
| `last_recovery_reason` | `none` / `parent_loss` / `router_loss` / `rootless` / `no_parent_found` / `stop_reconnection` / `mqtt_only` / `sustained_weak_root` / `topology_change` / `root_link_unhealthy`。復帰後も直近理由を保持 |
| `no_parent_found_count`, `last_scan_times` | boot内のevent回数と最後のscan_times（payloadなしは−1） |
| `stop_reconnection_count` | boot内のreconnection停止event回数。これだけで再起動しない |
| `parent_reselection_count` | boot内のOMK parent再選択要求の受付成功回数（child lossとweak-root Level 2）。復旧完了回数ではない |
| `parent_loss_duration_s` | parent未接続またはrootlessの連続秒数。解除後は0 |
| `restart_budget_spent` | trueなら自動restart禁止。NVS障害時もtrue |
| `recovery_restart_count`, `last_restart_reason` | NVSの累積restart予約回数と最後の予約理由。bootを跨ぐ。commit後の電源断などでは実reset回数と異なり得る |

孤立中のMQTT送信はできない。復帰後のboot内counter・最後の理由と、bootを跨ぐrestart診断を合わせて読む。data-transformerではこのtopicもstatusとして計測変換から除外する。

`is_rootless`、layer、parent BSSID、IPも再構成の途中値である。特に同一SSIDで異なるBSSIDを持つGateway／市販中継機の環境では、異なるroot/treeが形成されるリスクを実機評価中である。非同期起動やNode移設後に最適rootへ自動復帰する保証はないため、現在はNode参加後の安定待ちや、弱いroot uplinkでの切断増加を条件にroot再選出を要求する。成功後のcooldownと120秒のliveness restart抑止を含む[現行policy](../decisions/esp-wifi-mesh-node-networking.md#現行のroot再選出とlivenessの関係)を参照する。市販中継機との併用自体は否定せず、今後の実住宅試験で評価する。

## 汎用JSONL収集

`sensor-collector`は`omk/#`をQoS 0で購読し、測定値とOMK Nodeのregistration statusを収集する。JSONLのpayloadを機種別の列へ展開しない。ただし保存前に、通常BLE topicの`device_id`と`source`に基づくdirect優先フィルタを適用する。direct受信から30秒未満のrelay観測はJSONL・latestともに更新しない。sourceがない旧payloadは従来どおり保存する。

Raspberry Pi側でAsia/Tokyoの受信時刻をミリ秒付きISO 8601形式で付与し、`data/sensors/YYYY/MM/DD.jsonl`へ1メッセージ1行で追記する。通常のJSON payloadの共通構造は次のとおりである。

```json
{"received_at":"2026-07-30T10:54:12.123+09:00","topic":"omk/sen66-001/sen66","qos":0,"retain":false,"payload":{"device_id":"sen66-001"}}
```

JSONとして解析できないUTF-8 payloadは`payload_raw`と`payload_parse_error`を記録する。UTF-8でないpayloadは`payload_base64`と`payload_encoding: "base64"`で保持し、メッセージを破棄しない。汎用経路のCSVはParquetから後段で生成する。Bルートサービスは別途、専用CSVをMQTT配送前にも保存する。

## latest状態キャッシュ

JSONL保存に成功した正常JSON payloadは、payloadの`device_id`、MQTT topic、payload fieldを組み合わせた汎用latest storeにも記録される。`data/latest/items/<stable-item-id>.json`は各scalar値の最新レコード、`data/latest/catalog.json`は検出済みsource/value候補の一覧である。IDは`SHA-256(topic + NUL + device_id + NUL + field)`由来のため、BルートとBLE Plugが同じ`power` data typeを使っても衝突しない。catalogは通信断で候補を削除しない。候補から除くメタデータと保存形式は[sensor-collector README](../../services/sensor-collector/README.md)を参照する。

現行Dashboardとの互換のため、Bルート`power`（`net_power_w`を持つpayload）、SEN66`sen66`、住宅用PV・蓄電池・PCS profileの`power-flow`は、それぞれ`data/latest/broute_power.json`、`sen66.json`、`ichijo_power_flow.json`にも更新する。Plugの`power`はこの旧Bルートcacheを更新しない。collectorは同一ディレクトリの一時ファイルをatomic置換するため、Dashboardは読取り途中のJSONを参照しない。Display Item選択、推奨表示、custom表示と設定保存は現在のDashboardに実装され、設定は`data/dashboard/settings.json`へ保存される。

## BLEセンサ

SwitchBot等のBLE受信は Dashboard ではなく Raspberry Pi ホスト上の`omk-ble-sensor-manager` が行う。登録の物理 `device_key` と論理`sensor_id` を分離し、MQTT payload の `device_id` には後者だけを使用する。environment payload は `device_id`、`measured_at`、`quality`、利用可能な `temperature_c`、`relative_humidity_percent`、`co2_ppm`、`battery_percent` を含む。collector は従来通り型を解釈せず JSONL に保存する。

Gateway direct BLEとESP32 Node relayを併用するSwitchBot BLE sensorでは、Nodeは論理`sensor_id`や`device_key`を生成せず、manufacturer data、service data、BLE address、RSSIを`omk-relay/<relay_node_id>/ble/raw`へpublishする。この内部topicは`sensor-collector`と`harvest-uploader`の`omk/#`購読対象外である。BLE Sensor Managerがdirect BLEと同じdecoderとregistryでsensorを特定した後だけ、通常の`omk/<sensor_id>/{environment,motion,contact,power}`へメッセージをpublishする。direct/relayの経路選択仕様とpayload例は[BLE direct / ESP32 Node relayの経路選択](../decisions/ble-direct-relay-route-selection.md)を参照する。

BLE測定値には`source: "direct"`または`"relay"`を付け、relayの場合だけ`relay_node_id`を加える。`measured_at`はGatewayでのBLE callback/raw relay受信時刻で、センサ本体の計測時計ではない。`quality: "normal"`はenvironmentとpowerに付け、motion/contactには付けない。下記のJSONは主要測定fieldの抜粋であり、batteryやlight等もdecoderが取得できた場合は含む。

BLEアドバタイズは常時受信し、登録済み一覧のruntime latest値、RSSI、受信時刻はdirect受信で更新する。この一覧の受信状態とrelay由来のMQTT測定値は別である。environmentは初回の正常値を即時publishし、以後は`device_key`ごとに最短10秒間隔でpublishする。Motion Sensorは状態変化時に即時publishし、同一状態も最短10秒間隔で `{"device_id":"motion-001","measured_at":"...","motion_state":1}`の形でpublishする。`motion_state`は0=不在、1=検知である。

Contact Sensorも状態変化時に即時publishし、同一状態も最短10秒間隔で`{"device_id":"contact-001","measured_at":"...","contact_state":1}` を publishする。`contact_state`は0=閉、1=開で、公式のtimeout-not-closeも開（1）として正規化する。direct/relay経路の切替時は同値でも最初の観測を即時publishする。各rate limitはmonotonic clockを使い、`enabled=false`ではBLE observationと runtime更新を継続する一方、MQTT publishは停止する。したがってJSONLへのSwitchBot 一次保存は厳密な固定周期ではなく、通常は最短約10秒間隔となる。

Plug Miniは`{"device_id":"plug-001","measured_at":"...","power_w":173.2,"switch_state":1}`を`omk/<sensor_id>/power`へpublishする。`switch_state`は 0=OFF、1=ONで、初回は即時、同一状態は最短10秒間隔、状態変化は即時publishする。Pi実機では`omk/plug-001/power`がsensor-collectorの日次JSONLへ保存され、`power_w`と`switch_state`がpayloadのまま記録されることを確認した。BLEの受信時刻に依存するため厳密な10秒固定ではないが、通常は最短約10秒間隔で保存される。

## Bルート接続

Bルート通信はUSBシリアル、OS権限、認証、PANA通信に依存するため、当面はホスト上のsystemdサービスで実行し、コンテナ化しない。Bルート値は`omk/<device_id>/power`などへpublishされ、collectorのJSONL保存とlatest状態キャッシュへ反映される。現在は専用CSVへ保存した後、MQTTへbest-effortで送信する。MQTT切断中の値はMQTT再送用に保持しないため、CSVとcollectorのJSONLの件数が常に一致するとは限らない。

## セキュリティと運用

現在のMosquitto設定はOMK専用LAN内の匿名・平文接続である。認証、ACL、TLSは未実装である。MQTTポートをSORACOM側または他のホストインターフェースに公開してはならない。

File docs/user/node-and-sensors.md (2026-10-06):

# OMK Nodeで計測範囲を拡張する

Gatewayから離れた部屋や別の階でも計測したいときに、OMK Nodeを追加する必要があるかを判断するページです。OMK Nodeは、AtomS3 LiteにOMK用ファームウェアと設定を導入した端末です。SEN66を接続して計測するほか、センサや別のNodeから届いたデータをGatewayへ送る役割も担えます。

## Gatewayへ直接届く場合は、そのまま使う

BLEセンサの電波がGatewayへ届き、計測値が更新されていれば、そのセンサのためにNodeを追加する必要はありません。SEN66 NodeもGatewayと通信できていれば、1台で計測を続けられます。

```mermaid
flowchart LR
    ble["BLEセンサ"] -->|BLE| gw["Gateway"]
    sen["SEN66 Node"] -->|Wi-Fi| gw
```

## BLEセンサの電波が届かない場合

Gatewayへ直接届かないBLEセンサの近くにNodeを置き、そのNodeがセンサの電波を受信してGatewayへデータを送れます。これが「BLE中継」です。Nodeは、対象のBLEセンサの電波が届き、Gatewayとも通信できる位置に置きます。

```mermaid
flowchart LR
    ble["離れた場所のBLEセンサ"] -->|BLE| node["近くのOMK Node"]
    node -->|Wi-Fi| gw["Gateway"]
```

BLEセンサの初回登録はGatewayの近くで行います。Node経由でのみ受信している未登録センサは探索候補に表示されないためです。登録後に設置場所へ戻して中継を利用します。

## 離れたNodeの通信が届かない場合

SEN66 NodeなどがGatewayと直接通信できないときは、その間に別のNodeを置き、Node同士でデータを運べます。これが「Mesh中継」です。間に置くNodeには、離れたNodeとGatewayの両方へ通信できる位置を選びます。

```mermaid
flowchart LR
    far["離れたSEN66 Node"] -->|Mesh| middle["間に置くOMK Node"]
    middle -->|Wi-Fi| gw["Gateway"]
```

BLE中継は「BLEセンサの電波をNodeが受ける機能」、Mesh中継は「Nodeからのデータを別のNode経由でGatewayへ運ぶ機能」で、別の機能です。同じNodeで両方を使えます。例えば、Nodeが受信したBLEデータを、さらに別のNode経由でGatewayへ届けることもできます。

図は通信経路の例です。実際のNode間通信にはESP-WIFI-MESHを使い、配置や電波の状態に応じて経路が選ばれます。すべてのNode同士が直接つながる必要はありません。

## SEN66 Nodeと中継専用Nodeを選ぶ

SEN66 Node自身も、SEN66を計測しながらBLE中継やMesh中継を行い、通信経路の一部になれます。既に設置したSEN66 Nodeで届くなら、専用のNodeを増やす必要はありません。

その場所でSEN66を計測する必要がなく、通信範囲を広げたい場合は、センサを接続しない「中継専用Node」を置きます。どちらのNodeも設置場所でUSB電源から常時給電するため、電源を確保できる場所を選びます。壁や階、金属によって電波の届き方が変わるので、設置後に通信を確認して位置を調整します。

中継専用Nodeが必要と判断したら、[「中継専用OMK Nodeをセットアップする」](relay-node-setup.md)で準備・設定・設置を行います。SEN66の計測も追加する場合は、[「3-1. SEN66 Nodeの組み立て」](sen66-node-assembly.md)を参照してください。

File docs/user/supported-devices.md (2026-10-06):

# 1-2. 対応センサ・機器と取得データ

OMKで使える機器、取得できる値、接続方法の一覧です。「対応」は表に記載したデータを取得する機能があることを示し、製品の全機能や、すべての個体・ファームウェアでの動作確認を意味しません。対応範囲はこのページに記載している機器・データに限ります。計測値は設置環境や機器の状態により取得できないことがあります。

## 一覧

OMKで一般的に利用する機器カテゴリと、主な計測項目です。

| 機器・センサ | 接続方法 | 取得できる値・状態 | 対応上の注意 |
| --- | --- | --- | --- |
| 低圧スマートメーター（Bルート） | RS-WSUHA-PをGatewayへUSB接続し、スマートメーターから無線で受信 | 系統の瞬時電力（W）、買電・売電の積算電力量（kWh）、30分ごとの買電量・売電量（kWh） | 売電の積算電力量・30分ごとの売電量は、スマートメーターが逆方向の計量に対応している場合に取得します。瞬時電力は買電時が正、売電時が負です。 |
| [Sensirion SEN66（公式製品情報）](https://sensirion.com/jp/products/catalog/SEN66) | SEN66をOMK Nodeへ接続し、NodeからGatewayへ送信 | 温度（℃）、相対湿度（%）、CO₂濃度（ppm）、PM1.0・PM2.5・PM4.0・PM10濃度（µg/m³）、VOC Index、NOx Index | SEN66を接続したAtomS3 Liteを使います。詳細な仕様やVOC Index・NOx Indexの説明は、公式製品情報と同ページ掲載のデータシートを参照してください。 |
| SwitchBot BLEセンサ | BLE | 温湿度、CO₂濃度、人感・在不在、開閉、消費電力など（機種による） | 対応機種の詳細は[次節](#switchbot対応機器)を参照してください。 |

## SwitchBot対応機器

以下の機器がBLEで送信する計測値や状態を、Gatewayで受信します。OMKで計測値を受信するために、GatewayとのBluetoothペアリングやSwitchBotハブとの接続は必要ありません。同型・類似製品でも、ファームウェアや送信内容の違いにより利用できない場合があります。

| 機器・センサ | 接続方法 | 取得できる値・状態 | 対応上の注意 |
| --- | --- | --- | --- |
| SwitchBot 温湿度計（Meter、Meter Plus） | BLE | 温度（℃）、相対湿度（%） | — |
| SwitchBot CO2センサー（Meter Pro CO2） | BLE | 温度（℃）、相対湿度（%）、CO₂濃度（ppm） | — |
| SwitchBot 人感センサー | BLE | 人感状態 | 状態変化時のほか、定期的に送信される状態も取得します。 |
| SwitchBot 人感センサーPro | BLE | 人感／在不在状態、バッテリー残量、照度レベル（0～15の16段階） | バッテリー残量は取得できない場合があります。 |
| SwitchBot 開閉センサー | BLE | 開閉状態 | 状態変化時のほか、定期的に送信される状態も取得します。 |
| SwitchBot プラグミニ | BLE | 消費電力（W）、ON／OFF状態 | — |
| SwitchBot 防水温湿度計 | BLE | 温度（℃）、相対湿度（%） | — |

次へ：[「2-1. OMKのパーツ構成」](parts-list.md)

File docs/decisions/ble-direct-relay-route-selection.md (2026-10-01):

# BLE direct / ESP32 Node relayの経路選択

- **決定日:** 2026-08-17
- **ステータス:** 採用
- **対象:** SwitchBot BLE sensorをGateway direct BLEとESP32 Node relayの両方で受信する経路

## 背景

OMKでは、BLEセンサを次の二つの経路で受信できる。

1. Gateway Raspberry PiがBlueZで直接BLEアドバタイズを受信する経路
2. ESP32 NodeがBLEアドバタイズを受信し、Wi-Fi/MQTTでGatewayへrelayする経路

これはBLE到達範囲の拡大と通信冗長化に有効である。一方、同じ物理センサを両方が受信すると、同じ測定値がJSONL一次保存とHarvestの1分集約へ二重に入る。特にHarvestでは、二つの経路をそのまま平均に加えると値の重み付けが変わり、データの信頼性を損なう。

## 決定

BLEアドバタイズ単位で「同じBLE受信データか」を厳密に照合しない。OMKでは10秒値をBLE受信ごとに完全に保存することより、最終的な1分集約値を安定させることを優先する。そのため、測定値の同一性ではなく、deviceごとに現在採用する受信経路を選択する。

- Gateway direct BLEを主系とする。
- ESP32 Node relayをfallbackとする。
- 有効なdirect observationを受信したら、通常のsensor topicへのpublishのrate limitや値変化と独立してdeviceごとの`last_direct_seen`を更新する。
- direct受信から30秒**未満**のrelayは破棄する。
- direct受信から30秒**以上**経過したrelayは採用する。
- directが復帰したら、その最初のdirectから即時に主系へ戻す。
- freshness判定はwall clockではなくmonotonic時刻で行う。
- 状態はdeviceごとに独立させる。

SwitchBot等は通常およそ10秒周期で受信できるため、30秒は1〜2回程度BLEアドバタイズを受信できなくてもrelayへ切り替えず、約3周期のdirect未受信でfallbackとする値である。30秒ちょうどはrelayを採用する境界とする。

## Gatewayでのsensor特定とrelay入力

ESP32 NodeはGatewayの論理`sensor_id`を持たない。NodeはSwitchBotの機種判定、decode、`device_key`生成を行わず、manufacturer dataとfd3d service data、BLE address、RSSIをraw observationとしてrelayする。Gatewayがdirect BLEと同じ`switchbot.decode()`でphysical identityと`device_key`を決める。

```text
switchbot:<12桁lowercase hex>
```

例:

```text
switchbot:020000000001
```

NodeからGatewayへの入力は、通常のsensor topicではなく次の内部topicである。

```text
omk-relay/<relay_node_id>/ble/raw
```

```json
{
  "protocol_version": 1,
  "relay_node_id": "112233445566",
  "ble_address": "020000000001",
  "rssi": -45,
  "manufacturer_data": [{"company_id": 2409, "data": "..."}],
  "service_data": [{"uuid": "0000fd3d-0000-1000-8000-00805f9b34fb", "data": "..."}]
}
```

`omk-relay/...`は`sensor-collector`と`harvest-uploader`が購読する`omk/#`の外に置く。したがって、Gatewayでsensorを特定する前のrelay入力はJSONL保存・Harvest集約へ入らない。

GatewayのBLE Sensor Managerは既存registryで`device_key`に対応するsensorを特定する。登録済みかつenabledなenvironment、motion、contact、power sensorを、それぞれの通常topicへ再publishする。次は`switchbot:020000000001`を`th-001`へ対応付けるenvironmentの例である。`measured_at`にはNodeの時計ではなくGateway受信時刻を付与する。

```text
omk/th-001/environment
```

```json
{
  "device_id": "th-001",
  "measured_at": "...",
  "quality": "normal",
  "temperature_c": 24.4,
  "relative_humidity_percent": 48,
  "source": "relay",
  "relay_node_id": "112233445566"
}
```

未登録またはdisabledの`device_key`は通常のsensor topicへpublishしない。自動登録もしない。direct側も同じ`omk/th-001/environment`へ`source: "direct"`を付けてpublishするため、後段は経路に関係なく同じ`device_id`単位で判定できる。

Node自身の`logical_id`（例: `sen66-001`）と、NodeがrelayするBLE sensorの`device_key`およびGatewayの`sensor_id`は別概念である。Nodeのlogical IDをBLE sensor IDへ流用しない。

## selectorの適用位置

BLE Sensor Managerは、登録済みsensorの有効なdirect observationを受信するたびにfreshnessを更新し、directが新しい間はrelayを通常topicへpublishしない。direct復帰時は通常のrate limitにかかわらず最初のdirectをpublishする。

MQTT broker上でdirectとrelayが同じ`omk/<sensor_id>/{environment,motion,contact,power}`へ届いた場合にも備え、独立したsinkでも同じ30秒境界の選択を行う。

- `sensor-collector`: JSONL append直前
- `harvest-uploader`: `MinuteAggregator.ingest()`直前

両サービスは独立したMQTT clientとして`omk/#`を購読し、各clientが受信したdirectメッセージの時刻を基準に選択する。BLE Sensor Managerが持つBLE受信ごとの時刻は共有しない。`source`がない旧payloadは移行互換のため従来どおり通過させる。SEN66、Bルート、住宅用PV・蓄電池・PCS profileの`power-flow`などBLE sensorの通常topic以外は対象外である。

## 採用時の実機E2E確認

以下は採用時の試験記録である。現在は上記のとおりBLE Sensor Managerでもrelayを抑止するため、direct正常時に両sourceがbrokerへ流れることは通常動作の要件ではない。

- **direct + relay同時動作:** broker上で`omk/th-001/environment`の`source=direct`と`source=relay`を確認した。collector JSONLにはdirectだけが保存され、relayは抑止された。
- **direct停止:** Gateway Bluetoothを`rfkill`でsoft blockし、BLE Sensor Managerを動作させたままdirectを途絶させた。30秒以上経過後、collector JSONLへ`source=relay`が保存された。
- **direct復帰:** Gateway Bluetoothを復帰させてBLE scanを再開すると、最初のdirectから即時に`source=direct`へ戻り、以降のrelayは再びJSONLから抑止された。

したがって、`direct正常 → direct断 → relay fallback → direct復帰`のE2E動作を確認済みである。

Presence Sensor Proでは、Node relayがmanufacturer dataとfd3d service dataを結合して送信できることを確認した。Gateway内蔵Bluetoothでは同機器のScan Responseを取得できない実機差があるため、Node relayとは別のdirect BLE側制約として扱う。SEN66とraw relayの同時動作では、不要なraw publishを発生源で抑えることで、SEN66 telemetry、Mesh status、MQTTが継続することを確認した。

## 制約と今後

採用時の試験では、Gateway Bluetoothを`rfkill block bluetooth`後に`rfkill unblock bluetooth`してもBlueZ scanは自動復帰せず、BLE Sensor Managerの再起動が必要だった。これはroute selectorとは別の復旧上の制約である。

Node relayには次の現時点の制約がある。

- Meter / Meter Plus、Meter Pro CO2、防水温湿度計、人感、Presence Sensor Pro、開閉、Plug MiniをGateway decoderと同じ経路で扱う。
- raw relayはdeviceごとに原則最短10秒に制限する。active scanでADVとScan Responseが結合してmanufacturer dataまたはservice dataが追加される場合だけ、10秒内に1回の完全化更新を許可する。
- rate-limit状態はメモリ上だけに保持する。
- 同時追跡は固定16台までである。

長期運用では、SEN66の欠測、relay経由の異常、`parent_disconnect_count`、`mqtt_disconnect_count`、Mesh parent変更、root交代、意図しない再起動、heapの継続的低下を確認する。

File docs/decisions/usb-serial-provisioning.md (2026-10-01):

# USB Serial/JTAG Provisioningを正式採用

## 決定

Node初回登録の正式方式はUSB Serial/JTAG Provisioningとする。初回だけNodeをGatewayへUSB接続し、Gateway CLIがUSB serial候補を列挙してversioned `identify` JSON応答からNode IDを取得する。GatewayのOMK AP SSID/PSKを送信すると、Nodeは既存Wi-Fi credential storageへ保存してread-back照合し、software reboot後に通常のWi-Fi STA/MQTT registrationを開始する。AtomS3 LiteでMQTT registration statusまでのE2Eを確認済みである。

SSID、PSK、Node ID、物理ボタンの入力は不要である。USB抜き差しをreset手段として前提にせず、共通firmwareへcredentialだけを後から追加設定する。

現在の一般利用者向け初回導入は、[Gateway USB Node setup](usb-node-setup.md)で追加したDashboardからのprebuilt書込みとUSB provisioningを使用する。この文書のCLIは、通常firmwareが動作しているNodeへのWi-Fi設定・開発検証用として維持する。

## 不採用方式

- BLE GATT provisioning: Raspberry PiからAtomS3 Liteへの接続が不安定で、`le-connection-abort-by-local`、HCI `0x3e`が発生した。PPCP/MTU/PHY等の低レイヤ調査は停止し、保守コストを許容しない。
- BLEアドバタイズ設定用transport: Raspberry Pi kernel 6.18とBlueZ 5.82でLEアドバタイズ登録が`Invalid Parameters (0x0d)`となり、Gateway依存が強い。
- Temporary SoftAP + HTTP: Node側のWPA2 SoftAP、`/health`、`/config`、Node固有setup PSK、credential保存はPoC済み。ただし単一`wlan0`をOMK AP→STA→Node SoftAP→OMK APと切替えるGateway経路が不安定だった。
- ESP-NOW / Wi-Fi Aware等: Raspberry Pi側の特殊実装・driver依存・長期保守負担がUSB方式より大きい。

USB方式はLinux BLE stackやGateway Wi-Fi構成に依存せず、通常firmwareと通常のBLE sensor relayを維持できる。

## USB identity guard（protocol v2）

公開前監査H1/H2への対応として、USBだけprotocol v2へ更新する。BLE Discovery、MQTT、Node IDの生成方式はv1のまま維持する。上記E2E確認は旧実装の記録であり、以下の変更は実機再確認を必要とする。

- 自動探索は対応候補全体をidentifyし、realpathでまとめた物理portが0台なら失敗、1台なら自動選択、複数なら停止する。異なるportの同じnode_idをaliasとしてまとめない。
- `--device`はそのportをidentifyして選択する。`--node-id`だけなら全候補から一意に選択する。両方指定なら一致を要求する。`--clear-wifi`はどちらかの明示指定が必要。
- Dashboardはカードのnode_idとportをbackendへ送る。backendは再探索で照合し、最終操作にも同じnode_idを渡す。
- Pythonは操作用のserial接続を開いた後、v2 identifyと期待IDの照合を行い、同じ接続でのみ状態変更を送信する。不一致／timeout／旧protocolなら状態変更要求を送らない。
- `set_wifi`／`clear_wifi`の要求には`expected_node_id`が必須。firmwareは12桁小文字hexの自身のIDとの一致を確認してから保存／消去する。欠落・不一致なら`node_identity_changed`で拒否し、再起動も予約しない。v1状態変更要求は`invalid_request`。探索用identifyはv1も受け付け、返信はv2とする。
- USB処理の状態変更commandは上記2種類。accepted後の再起動も同じguardの後に予約する。開発用firmware書込みスクリプトは別経路で、今回変更しない。

旧firmwareへの自動fallbackは行わない。GatewayのCLI/system-managerとNode firmwareを両方更新し、system-managerを再起動する。通常firmware更新後にUSB設定を実行する。保存済みcredentialやlogical_idのデータ形式は変更しない。

この照合は偶発的な個体取り違えを防ぐためのもので、node_idを偽装する機器への暗号学的認証ではない。操作中に通信が切れた場合は別portへ自動で操作を転送せず、失敗として再選択する。

### 自動テスト

リポジトリルートから実行する。Python環境にはpytestを含む関連サービスの開発依存が必要。

```sh
OMK_TEST_CJSON_DIR="$PWD/firmware/esp32/omk-node/managed_components/espressif__cjson/cJSON" \
python -m pytest scripts/tests/test_provision_omk_node_via_usb.py scripts/tests/test_usb_node_provisioning_service.py firmware/esp32/omk-node/tests/test_usb_provisioning_protocol.py
```

firmwareテストは実際のCコマンドhandlerとcJSONをホストcompilerでコンパイルし、NVS相当の保存／消去呼出しをfakeへ置換して回数を検証する。`cc`とcJSON sourceが必要。現行ESP-IDF 6環境では`OMK_TEST_CJSON_DIR`に`firmware/esp32/omk-node/managed_components/espressif__cjson/cJSON/`の絶対パスを指定する。別配置でも同変数に`cJSON.c`と`cJSON.h`のあるディレクトリを指定する。依存がない場合はskipになるため、公開前確認ではこのテストが実行されたことを確認する。

### 実機再確認手順（未実施）

実機試験は人が行う。秘密情報・実在IDをfixtureや文書に転記しない。

| 条件 | 操作 | 期待結果 |
| --- | --- | --- |
| 1台・CLI自動 | 更新済みNodeを1台接続し、CLIを引数なしで実行 | 1台を選択し、設定・再起動・MQTT確認成功 |
| 2台・CLI自動 | 更新済みA/Bを同時接続し、CLIを引数なしで実行 | 曖昧エラー。どちらのWi-Fi設定も変わらない |
| 列挙順変更 | 2台の接続順・USB口を変えて同じ操作 | どちらの順でも曖昧エラー |
| alias | 1台のby-idとttyACMが両方存在する状態でCLI自動実行 | 2台扱いせず1台として成功 |
| Dashboard選択 | A/BのカードからAを選択して設定 | Aのみ設定・再起動。Bは変更なし |
| CLI明示選択 | `--device <Aのport>`、`--node-id <AのID>`、両方指定を試す | Aだけ成功。Aのport＋BのIDは送信前に失敗 |
| 画面表示後の交換 | Aのカードを表示後、Aを外してBが旧ttyを取得する状態でAの設定を実行 | 拒否。Bへcredentialを送らない |
| identify後の交換 | 開発debuggerで最初の選択完了後、操作用open前に停止し、A→Bへ交換して再開 | 操作用identify不一致で停止。set_wifi送信なし、Bの設定変更なし |
| 同一接続中の切断 | 開発debuggerで操作用identify後に停止し、抜き差しして再開 | 元接続の失敗。別portへ再openして送信しない |
| clear_wifi | 明示Aで成功を確認し、上記差し替え条件も試す | 正常時はAのみ消去。不一致時はBの保存済み設定・再起動状態とも変更なし |
| firmware最終防御 | テスト用credentialでexpected ID欠落／不一致のv2要求を手動送信 | 保存・消去・再起動なし。適合要求だけ成功 |
| 旧版混在 | 新Gateway＋旧Node、および旧CLI＋新Nodeを試す | 設定失敗。旧protocolへのfallbackや状態変更なし |

差し替え試験ではUSB要求commandの順と保存／消去の有無を確認し、PSK本文をログへ残さない。v1 Nodeも読み取り専用探索で台数に数える。新旧2台が応答した場合も自動選択は拒否し、旧Nodeを明示選択しても操作用v2確認で停止する。

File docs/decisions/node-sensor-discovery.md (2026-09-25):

# Node有線センサのdiscovery / identity（M4）

## 境界と今回の実装

I2C addressへのACKはendpointの存在確認であり、model identityではない。探索ではread-onlyのidentity commandを優先し、機種確定前にreset、設定変更、measurement startを送らない。値がもっともらしいことも機種識別根拠にしない。

`firmware/esp32/omk-node/src/`の責務は次のとおり。

| ファイル | 責務 |
| --- | --- |
| `sensor_driver.h` | transport / endpoint、identity結果、driverのidentify/start/read/publish/close契約 |
| `sensor_driver.c` | 全候補driverのevidenceを評価して選択 |
| `sensor_drivers.c` | production driver registryとSEN66の既存MQTTへのadapter |
| `sensor_manager.c` | endpointごとのcontext・接続状態・計測・再探索・復旧 |
| `sen66_sensor.c` | SEN66の存在確認、Product Name検証、初期化、計測 |

endpointはtransport、handle、I2C address / UART port / ADC channelのunionを持つ。addressは候補driverを絞るためだけに使用する。現在のboard profileはI2C `0x6B`の1 endpoint、production registryはSEN66の1 driver。managerはendpointごとのslotを扱い、機種名による分岐を持たない。現時点でUART/ADCの探索・計測や設定保存を実装したわけではない。

identityは`EXACT`、`AMBIGUOUS`（familyを含む）、`NO_MATCH`、`ERROR`（不正応答含む）、`CONFIGURATION_REQUIRED`を区別する。複数exactまたはfamily evidenceが残ればambiguous、他候補のerror/configuration requiredが残れば自動選択しない。全候補を評価し、唯一のexactだけを採用する。driverの順番を変えても選択は変わらない。

他protocolへのprobeがtimeoutしたことを機械的にno-matchへ弱めない。このため将来、別driverのexactとSEN66 probe errorが同時に出るendpointも未認識になる。その場合は安全性を確認した共通protocol discriminator、または明示profileによる候補制限を追加する。未知deviceへの全commandの無害性はaddressだけでは保証できない。driver追加時には同じendpointの他機種に対してもprobeが設定変更等にならないか確認し、根拠がない組合せは自動探索へ入れない。

## SEN66の識別と復旧

1. `0x6B` ACK後、仮のdevice handleで`Get Product Name (0xD014)`を読む。
2. 32 data bytes（CRC込み48 bytes）を要求する。通信失敗、各2 bytesのCRC不一致を拒否する。CRCはinit `0xFF`、polynomial `0x31`。
3. NULまでの文字をprintable ASCIIとして検証し、空文字・NUL欠落を拒否する。NUL後のpaddingは規定しないが、全wordのCRCは必須。
4. `SEN66`の完全一致だけexact。`SEN63C` / `SEN65` / `SEN68`はfamily/ambiguous。他文字列や`SEN66-extra`をSEN66にしない。
5. 選択後も状態変更直前に再識別する。確認できたSEN66にのみstopを送り、1.4秒待ち、再度identityを検証してreset / startへ進む。

ESP-IDF receive APIには実受信長の返却がないため、固定48 bytesの成功と全word CRCを要求する。未受信領域は`0xFF`で初期化し、短い応答を補完して正常扱いしない。Product Nameはmodel identityであり、個体serialを意味しない。`0xD033` Serial Numberは今回使わない。

SEN66が計測を継続したままMCUだけ再起動した場合やliveness復旧でも、idle専用のresetを安全に行えるようstopを入れる。既にidleならstopが失敗する場合を許容するが、その後のidentityとresetの成功は必須。探索中のstopは行わない。

計測前にもProduct Nameを読み、別機種や不正identityならその周期の値をpublishせず、即座にconnected=falseとしてlocal handle/contextを解放する。recovery時には古い機種だと仮定したstopを送らない。60秒後の再探索でexactを得てから初期化し直す。通常readの3回連続失敗と60秒measurement liveness timeoutも同じ再探索へ進む。未接続時も60秒ごとに探索するので、relay Nodeへの後付けに対応する。

計測待ち10秒、成功計測を基準としたliveness、Logical ID待ち、MQTT失敗時の継続、既存measurement変換・topic/payload・diagnosticsは維持する。確認とreadの間の瞬間的な交換までI2C transactionで原子的に防ぐものではない。同型機種への交換もserialで追跡しない。

## 将来driverを追加する際

registryへdescriptorとendpointごとのcontextを追加し、read-only identifyと確定後startを分ける。closeは交換先へ旧protocolのcommandを送らず、local resourceを解放する。復旧時に停止が必要なら、start側で再識別後に行う。現在のmanagerが要求するread/publish/connected/diagnostics callbackも実装する。

### SEN0466等のprotocol識別

DFRobot公式資料ではSEN0466はI2C/UARTを扱い、address group 3には`0x68` / `0x69` / `0x6A` / `0x6B`がある。従って`0x6B`はSEN66専用ではない。

公式MultiGasSensor実装の`queryGasType()`は濃度照会protocolの応答からgas typeを読む。将来driverでは少なくとも次を独立に検証する。

- 設定済みinterface / endpoint。UARTはport、baud等を明示し、未知portへ無差別にcommandを送らない。
- 9-byte frameの完全受信、先頭・応答commandとの対応（passive濃度照会は`FF 86`）、checksum。
- gas typeフィールド（byte 4、COは`0x04`）。checksumはSensirion CRCとは別の加算checksum。
- I2Cのregister/framingとUARTのactive/passive応答を混同しない。公式libraryの返却lengthを鵜呑みにせず実受信長を検証する。

これらはprotocol / CO familyの根拠であり、SEN0466というSKUの唯一性を保証する根拠ではない。固有model evidenceが不足する場合はfamily/configuration requiredとする。mode、address、alarm等を変更してidentityを得るprobeは採用しない。今回のテストには同じaddressの架空の第2driverを入れているが、SEN0466の実protocol実装・実機互換性試験ではない。

### 自動識別できないanalog sensor

特定製品向けの例外を作らない。電圧値やADC値からmodelを推定しない。現在はanalog endpointを必ず`CONFIGURATION_REQUIRED`とし、driverの自動probeも実行しない。UARTも今回の自動探索対象外で同じ結果とする。

将来はversionedなboard/利用者profileで、driver/model、物理channel、測定量・単位、入力電圧上限、ADC設定、基準電圧、変換式と係数、校正、許容範囲を明示する。profileの機種指定は「実物を自動識別したevidence」と区別する。未設定・不整合・未対応profileでは開始しない。profile変更時は古いcontext・測定値・Logical IDとの結び付けを再評価する。profileの保存/UIとADC measurement driverは今回未実装。

OMRONの公式D6F-W/V資料はアナログ電圧出力の例である。D6Fシリーズにはinterfaceの異なる製品があるため、シリーズ名だけでI2C対応や自動識別可能性を仮定しない。同じ設計方針を他社のアナログ電圧出力センサにも適用する。

## Gateway互換性と残課題

SEN66 adapterは既存`mqtt_registration_set_sen66_connected()`、diagnostics、publish関数を呼ぶ。Node registration、Logical ID、`connected_sensors`の生成経路は変更しない。capabilityはfirmwareの対応能力であり、現在接続されているsensorではない。未識別endpointをconnectedとして報告しない。後付け時は識別・開始成功によるconnected statusで既存Node一覧の登録操作へつながる。

slot構造は複数endpointを持てるが、現在のNode登録は1 Logical ID、connected statusもSEN66中心である。第2production driverやmulti-sensorを有効化する前に、endpoint/modelとLogical IDのbinding、sensorごとのconnected/diagnosticsとMQTT schemaを設計する必要がある。別modelに旧SEN66 Logical IDを渡す実装を追加してはならない。今回はGateway/UI/schemaを拡張しない。

同一bus/addressに2個体を並列接続すると、CRC異常等で拒否できても、整合した同一応答が重なるケースをソフトウェアで必ず検知できるとは限らない。物理address conflictは別bus、mux、address設定等で解消し、解消不能ならconfiguration requiredとして運用する。

## 根拠・検証

公式資料確認: 2026-09-10。

- [Sensirion SEN6x datasheet v0.9 Engineering Samples](https://sensirion.com/media/documents/057555E9/673DA8E3/Sensirion_Datasheet_SEN6x_v0.9_Distribution_Engineering_Samples.pdf): §4.8.18 Product Name（idle/measurement両方、20ms）、§4.9 CRC、stop/reset/startの条件。取得できた版はengineering sample資料であり、量産実機確認の代用とはしない。
- [Sensirion公式SEN66 C driver](https://github.com/Sensirion/embedded-i2c-sen66/blob/master/sen66_i2c.c): `sen66_get_product_name()`の32-byte読取りと20ms待機。
- [DFRobot SEN0466公式資料](https://wiki.dfrobot.com/sen0466/docs/24489)、[公式MultiGasSensor実装](https://github.com/DFRobot/DFRobot_MultiGasSensor/blob/master/DFRobot_MultiGasSensor.cpp): interface/address、gas type、framing/checksum。
- [OMRON D6F-W/V user manual](https://omronfs.omron.com/en_US/ecb/products/pdf/en-D6F-W_D6F-V_users_manual.pdf): アナログ出力例。D6F-W固有driverを今回実装する根拠には用いない。

`tests/test_sensor_identity.py`はproductionのmanager・registry・SEN66 Cコードをホストでコンパイルし、模擬I2C/time/MQTTで実行する。exact、未知device、別SEN6x、CRC・長さ・ASCII異常、初期化前の交換、複数driver競合、明示設定必須、未接続・再接続・別機種交換、liveness、MQTT/Logical ID待ちを検証する。実機操作は行っていない。新しいProduct Name確認と復旧シーケンスは実機再試験が必要。

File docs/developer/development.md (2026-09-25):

# 開発ガイド

OMKはPython services、Docker Compose、host systemd、ESP-IDF firmwareで構成されています。日常開発はWindows + WSL2でも行えますが、Gateway固有のNetworkManager、BLE、USB、systemdはRaspberry Pi実機で確認します。

## 基本環境

- Python service: 各`services/*/requirements*.txt`とREADMEに従う
- ESP32 Node: ESP-IDF/PlatformIO環境と[共通Node README](../../firmware/esp32/omk-node/README.md)
- Gateway: Raspberry Pi 4（正式な動作確認対象）、64-bit Raspberry Pi OS、Docker Compose
- 実運用構成: `compose.yaml`。Bルートのmock・container testは`compose.dev.yaml`を明示して実行する。`compose.mock.yaml`、`compose.windows-hardware.yaml`、`compose.pi.yaml`は現行リポジトリに存在しない

## Gatewayでの確認

新規Gatewayは`./scripts/setup-omk-gateway.sh --with-base`、既存Gatewayの再実行は`./scripts/setup-omk-gateway.sh`を使います。標準Composeサービスは次です。

```bash
docker compose ps
docker compose logs --tail 100 mosquitto sensor-collector dashboard harvest-uploader
curl http://localhost:8000/health
```

host serviceは対象を明示して確認します。

```bash
sudo systemctl status omk-system-manager.service --no-pager
sudo systemctl status omk-data-transformer.timer --no-pager
```

## テスト

各サービスの単体テストは対応READMEに従います。リポジトリ全体では、変更対象に応じてPython test、shell setup test、Compose設定検証を実行します。実機依存のBLE、Bルート、LTE、kioskは、対応ハードウェアを使ってRaspberry Pi上で検証します。

秘密情報、実測データ、SSID/PSK、Bルート認証情報、API tokenをテスト出力・fixture・Gitへ含めません。変更後は少なくとも対象テスト、`git diff --check`、関連文書リンクを確認してください。

## Fresh Gateway Principle

「既に設定・データが揃った開発機で動く」だけでは完了としません。機能実装・setup変更時は、初期設定ファイルなし、runtime dataなし、sensor登録なし、optional service未導入、一部の機器のみ存在、setup再実行の各状態を考慮します。

特にsetup scriptでは「新品状態 → setup実行 → 利用可能」を第一級のテストケースにします。開発機に残ったconfig、credentials、runtime data、registered devices、catalog、database、systemd unit、venvによって成功する実装にせず、既存設定保持・idempotencyとは別に「何もない状態から作れるか」を必ずテストしてください。

Dashboardデモも、catalog・latest・Parquet・登録済みセンサがない環境と、一部機器だけの環境を必須テスト条件にします。模擬項目は表示時の一時的な補完とし、実データ・登録情報・通常の表示設定へ保存しません。

## 変更の境界

コンポーネント単体の開発・デバッグは各READMEを参照してください。全体設計は[アーキテクチャ](architecture.md)、MQTT契約は[データ経路とMQTT](data-and-mqtt.md)、AP設計は[ネットワーク設計](networking.md)を参照してください。

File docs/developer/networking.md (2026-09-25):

# Gatewayネットワーク設計

この文書でOMK APとGatewayのネットワーク境界を定義します。利用者向けの設定手順は[Gatewayセットアップ](../user/gateway-setup.md)を参照してください。

## 境界

- Gateway自身は`wwan0`、EthernetなどのWAN経路からInternetへ接続できる。
- OMK AP clientはGatewayのローカルサービスへ接続できる。
- AP clientはMQTT（`192.168.50.1:1883`）とDashboard（`192.168.50.1:8000`）へ接続できる。
- AP clientをWANや他の外部インターフェースへ転送しない。
- AP側IPv6は無効にする。

`NetworkManager`の`ipv4.method shared`はDHCP払い出しに使うだけで、Internet共有を目的にしません。shared-mode dnsmasqには`no-resolv`を設定し、AP clientの上流DNS解決も停止します。

## ESP-WIFI-MESH Node internal network

AtomS3 Lite NodeはGateway APの外側にESP-WIFI-MESH internal IP networkを形成できる。root NodeだけがGateway APへ通常STA接続し、rootは`10.0.0.1/16`でMesh childへDHCP/DNSを提供してNAPTを有効化する。childの`10.0.0.x`通信はrootでNAPTされ、Gateway Mosquittoの`192.168.50.1:1883`へ通常TCPで到達する。

これはGatewayの`wlan0`にMesh専用プロトコルを追加するものではない。Gateway側にはMesh daemon、static route、Node別IP設定を置かず、既存のAP、AP専用MQTT socket、nftables境界を維持する。NodeのMesh AP credentialは保存済みGateway SSID/PSKからruntime導出し、Gateway credential、導出値ともログやsourceへ出さない。

共通firmwareではroot/parent/childをNode IDへ固定しない。配置、電波条件、起動順により役割は変わる。2026-08-20のAtomS3 Lite 2台試験ではrootがGateway側IPを取得し、childが`10.0.0.2`を取得して通常ESP-MQTTでMosquittoへ到達した。これは実測例であり、IPや役割の固定仕様ではない。E2E範囲とcredential migrationは[ESP-WIFI-MESH Node networking decision](../decisions/esp-wifi-mesh-node-networking.md)を参照する。

## forwardingルール

`setup-wifi-access-point.sh`は専用nftables tableに次のルールを導入します。

```nft
iifname "wlan0" oifname != "wlan0" drop
```

ComposeはMQTTとDashboardをそれぞれ`127.0.0.1:1883`、`127.0.0.1:8000`だけへ公開します。AP側には`FreeBind=yes`と`BindToDevice=wlan0`を指定したIPv4 systemd socketを置き、`systemd-socket-proxyd`でloopback backendへ中継します。prepareではunitを配置するだけとし、Composeのloopback移行とbackend healthの後にsocketを起動します。socketはAP addressの付与前に起動できるため、Docker image buildとruntime healthを初期Wi-Fiのまま完了できます。

DockerはAP addressやwildcardへpublishしません。socketは`wlan0`に固定し、forwarding ruleはAPから外部interfaceへの転送をdropします。この組み合わせにより、AP clientからGateway上のMQTT/Dashboardは使えますが、`wwan0`、Ethernet、将来追加するWANへは公開しません。

AP profileのprepare中はinactive profileの`connection.autoconnect`を`no`にします。全health checkとcredential handoff後、固定の`omk-ap-activation.service`がSSH sessionから独立してautoconnectを有効化し、APをactivateします。失敗時はautoconnectを`no`へ戻し、直前のWi-Fi profile UUIDが取得できていれば復帰を試みます。

## 現行実装と長期方針

現在のAP既定SSIDは`OMK-XXXXXX`、接続名は`omk-ap`です。これは現行実装のデフォルトであり、中央組織によるOMK ID発行や固定prefixへの長期依存を意味しません。公開版でも第三者が任意の識別子・SSIDで構築できる設計を維持します。

SSIDの`XXXXXX`は`/etc/machine-id`のSHA-256先頭6桁を大文字16進数にしたものです。machine-idを読めない場合はWi-Fi MAC addressを同じ方法でハッシュします。

PSKは初回プロファイル作成時だけ、OSのCSPRNG（`/dev/urandom`）から生成する24文字の英数字です。machine-id、MAC address、SSIDなどのGateway固有値からPSKを導出してはいけません。既存プロファイルの保存済みPSKは最優先で維持し、`OMK_AP_PSK`が指定されていても暗黙に上書きしません。既存PSKが欠落している場合だけ、`OMK_AP_PSK`または新規乱数を設定します。

PSKは`nmcli connection edit`の標準入力で設定し、argvやセットアップログへ出力しません。`--print-config`もPSK本文ではなく`[MASKED]`だけを表示します。

## setupの再実行と検証

旧AP-address Docker publishは、新socketを起動する前に解放します。移行前に稼働中production containerのimmutable image IDとpublishを保存します。移行中のbackend/socket失敗では新containerを停止し、保存したimage IDと旧publishで復旧を試みます。AP profileはdown/upしません。復旧後はimage ID一致、稼働状態、Dashboard HTTPとMQTT CONNACKを検証し、migration失敗とrollback失敗を別々に記録します。rollback失敗時は秘密情報を含まない復旧snapshotをmode 0600で残し、ログに場所を示します。新socketを確認するまで旧forwarding ruleを維持し、nft tableの置換は1 transactionで行います。

`wlan0`がfirmware crash等で一度消失すると、`BindToDevice=wlan0`のsocket unitは停止しうる。一方、`sockets.target`はすでにactiveなので、NetworkManagerの再activationだけではsocket unitは再startされない。setupは`/etc/NetworkManager/dispatcher.d/90-omk-ap-proxy-sockets`を配置する。これはNetworkManagerの`wlan0 up`イベントで、現在のconnectionが`omk-ap`であり、`192.168.50.1/24`が付与済みであることを確認してから、MQTT/Dashboard socket unitをstartする。addressやprofileが未確認なら何もbindせず終了する。常駐監視・pollingは行わない。

`./scripts/lib/validate-ap-socket-units.sh /etc/systemd/system --runtime`は、drop-inを含むunit、systemd実効property、`ss --inet-sockopt`の実listenerを検証します。IPv4/wlan0 bindingに加え実socketの`freebind`も必要です。unit変更時にはsocketとproxyを更新し、同一設定の再実行では不要なrestartを避けます。

activation workerの時間枠はpreflight 30秒、request 20秒、activation 60秒、結果確認15秒、rollback 90秒です。unitは余裕を含め260秒、停止時のcleanupは100秒を許します。rollbackは現在のwlan0接続を再確認し、別connectionへの手動復旧や既に正常なAPを維持します。非同期deactivation後は90秒のrollback共通枠内で1秒ごとにcurrent UUIDを確認し、AP UUIDが消えてから旧Wi-Fiへの復帰を要求します。第三者UUIDまたは既に復帰した旧Wi-Fiは維持します。復帰待ち中には再度connection upを発行しません。

## BLE管理APIの接続制限

`setup-ble-sensor-manager.sh`は`omk-ble-api.service`と専用nftables tableを導入します。認証を持たないTCP 8787への直接接続は、loopbackと標準Docker bridge（`docker0`、`br-*`）だけに限定します。AP、有線LAN、LTEからの直接アクセスは遮断し、利用者はDashboard経由で操作します。BLE serviceはこの制限の適用成功後に起動します。再適用はtable単位のtransactionで行い、停止時もルールを残します。独自名のDocker bridgeは正式setupの対象外です。

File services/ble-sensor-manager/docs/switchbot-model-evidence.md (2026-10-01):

# SwitchBot model evidence と payload validation（M1 / M2）

## 判定と保存

機種選択は `switchbot._select_model()`、選択済み形式の復号は `_decode_selected()`、
数値の妥当性は `_values_valid()` に分ける。長さや正常値から機種候補を順番に試す
処理は廃止した。特に12-byte manufacturer dataはPlug / Outdoor両方の値として
成立し得るので、値の妥当性を機種固有性とみなさない。

1. 対応するfd3d service device typeを優先する。型を先に選び、その形式だけを検証する。
2. 登録済みphysical deviceのmodel hintと明示typeが矛盾したらunknownにする。
   正常なmanufacturer layoutでも矛盾を救済しない。
3. serviceがない場合だけ、既存registryのhintで選んだmanufacturer形式を検証する。
   Presenceの実測`00 20` service付き形式、およびPi内蔵Bluetoothでserviceが取得できない
   12-byte manufacturer-only形式は機種固有と確認できないため、Presence hintがある場合に
   限って対応形式を検証する。
4. 未登録のmanufacturer-only packet、未知service type、矛盾する複数service fieldは
   unknown。辞書・decoderの並び順で決めない。未知serviceを無視してhintへ戻らない。
5. 選択した形式や値が不正ならpacket全体をunknown・空valuesにする。別modelを再試行しない。

unknownはraw確認用candidateには表示するが、自動のID提案・登録・MQTT測定値
publishは不可。下記の未確認候補の明示選択に限り、利用者が機種を確認した上で登録できる。rawの`classification`に`evidence`と`status`を残す。
`invalid_payload`、`conflicting_model_hint`、`ambiguous_service`等を区別できる。
directの登録済み一覧には矛盾・不正packetの値を渡さず、`status=unrecognized`とし、管理画面は
「機種・データ未確認」と表示する。受信していることと正常に復号できることを区別する。

BLE address、manufacturer先頭6 bytes、`device_key_for()`、registered sensor IDの
生成・対応規則は変更しない。Meter / Meter Plusの内部modelを共通にする既存設計と
registryの旧名migrationも維持する。API schemaを増やして機種名を分割しない。

## 根拠の分類

Aは公式BLE仕様、Bは複数実機、Cは1個体の実測、Dは固有性未確認のコード上の仮定。
**公式配下の実装コードは公式仕様書とは区別**し、参照commitと対象形式を限定する。
既存captureの個体数・packet数は[過去のraw監査](switchbot-raw-capture-audit-2026-08-20.md)
の記録に基づく。今回、新しい実機captureは行っていない。

| 製品 / 内部model | 機種選択の根拠 | 復号形式と限界 |
| --- | --- | --- |
| Meter / `temperature_humidity_sensor` | A: service `0x54` | 6-byte serviceの温湿度・battery。C: manufacturer 11 bytes / index 7=`03`は既存hint時の形式条件だけ |
| Meter Plus / 同上 | A: service `0x69` | Meterと同じ6-byte値形式。service typeは区別できるがOMK schemaは意図的に共通。別個体実測の根拠は今回確認できていない |
| Meter Pro CO2 / `co2_sensor` | 参照した公式実装: service `0x35`、既存hint、または利用者明示確認 | B: 2個体の16-byte manufacturer形式。可変index 6/7/11/12/15を固定しない。byte 15は意味未特定で、classifier・validity条件に使用しない。7-byte serviceの別broadcast modeは未対応 |
| Motion / `motion_sensor` | A: service `0x73`、または既存hint | 公式6-byte service単独でも復号可能。C: manufacturer 10 bytes / status下位6 bit=`2c`はhint時の対応形式。index 8の`da`等も受容 |
| Presence Sensor Pro / `presence_sensor` | 参照した公式実装: service `0x70`。実測の`00 20` service付き・manufacturer-only形式は既存hintまたは利用者明示確認が必須 | C: 12+7 bytes、およびPi4内蔵Bluetoothで得た12-byte manufacturer-only。公式実装のstatus/照度のbit解釈と実測を使用する。長さの組合せだけで初回識別しない。`0x70`形式は参照実装由来の合成テストであり、今回の実機確認ではない |
| Contact / `contact_sensor` | A: service `0x64`、または既存hint | 完全な9-byte service。暗号化bit付きは未対応。manufacturer 13 bytes / status下位nibble=`c`は既存fixture系列に基づくC相当で個体差未確認。serviceの状態が古い実測があるため、同じmodelに選択した後は妥当なmanufacturer状態を優先 |
| Plug Mini / `plug_sensor` | A: `0x67`。参照公式実装・B: 国内複数個体の`0x6a` | 3-byte service、12-byte manufacturer。stateと電力の解釈はA。index 8の`10` / `16`や電力末尾`00`を機種IDとして使わない |
| Outdoor Meter / `waterproof_sensor` | `0x77`: 公式repo内の**非公式community補足**、参照公式実装、CのOMK実測 | 3-byte service、12-byte manufacturer。温湿度を復号。末尾`00`は対応形式条件だけ。型なし未登録packetはunknown |

Dだった「正常範囲なら機種確定」「12+7ならPresence」「末尾0ならOutdoor」
「16 bytesならCO2」「`0x16`ならPlug」は、初回model判定には使用しない。
登録済みhintは追加情報であり、layout自体に固有性を与えるものではない。

参照した一次資料:

- [SwitchBot BLE API device types](https://github.com/OpenWonderLabs/SwitchBotAPI-BLE/tree/latest)
- [Meter仕様とOutdoor community補足](https://github.com/OpenWonderLabs/SwitchBotAPI-BLE/blob/latest/devicetypes/meter.md)
- [Motion仕様](https://github.com/OpenWonderLabs/SwitchBotAPI-BLE/blob/latest/devicetypes/motionsensor.md)
- [Contact仕様](https://github.com/OpenWonderLabs/SwitchBotAPI-BLE/blob/latest/devicetypes/contactsensor.md)
- [Plug Mini仕様](https://github.com/OpenWonderLabs/SwitchBotAPI-BLE/blob/latest/devicetypes/plugmini.md)
- [既存Presence decoderが参照していた公式実装commit](https://github.com/OpenWonderLabs/node-switchbot/blob/d2eafbaa7bee75a907633f108329b3716c61e82b/src/device.ts)

参照commitではCO2=`5`、Outdoor=`w`、Presence=`p`。
一方、新しいSDKの[enum](https://openwonderlabs.github.io/node-switchbot/enums/SwitchBotBLEModel.html)
には異なる割当てがある。SDKのenumだけを新しいwire typeの証拠としてalias追加しない。
このdecoderは上表の対応形式を対象とし、例えば`0x77`に16-byte CO2 layoutが来ても
Outdoorとして値を返さずunknownにする。全firmware・全broadcast modeへの保証ではない。

## 値の検証

- battery / RHは0〜100%。温度小数のBCD相当nibbleは0〜9。flag bitは仕様に従って分離する。
- 温度はOMKの既存受入範囲−20〜60℃、CO2は400〜10,000 ppm。物理的に不可能という
  断定ではなく、この形式でOMKが受け入れる範囲である。範囲外をclampしない。
- Contact HAL state 3は拒否。Motion serviceは未対応のreserved status/light/distanceを拒否。
- Presenceはstatusの既存妥当性確認を維持し、motionはstatus bit 6から得る。末尾byteは
  bit 7をLED state、bit 0〜3を照度levelとして扱う。bit 4〜6は未解釈であり、立っていても
  packetを拒否しない。照度は0〜15のlevelでありluxではない。serviceがある形式だけbatteryを
  得て、manufacturer-only形式には`battery_percent`キーを作らない。serviceの未解釈tailを
  機種IDや測定値と推測しない。
- Plugはstate `00` / `80`を検証。電力のoverload bitを分離し0.1 W単位で復号する。
  0 W、低負荷、flag/counterが0のpacketも型またはhintがあれば扱える。
- 不正serviceがあれば正常manufacturerでも救済しない。供給されたmanufacturer測定
  payloadが選択modelに適合しなければ、正常serviceへのfallbackもしない。

## 登録済みhintと移行

hintは通常と同じphysical keyを作ってregistryから読み取る。新規candidateから
manufacturer推定でhintを作成・永続化しない。矛盾時にregistryを書き換える処理もない。
過去の誤登録が疑われる場合は実機の製品名とpacket evidenceを照合し、明示的な
serviceで安全に再識別できることを確認してから、管理者が登録解除・再登録する。
履歴データの自動修正は行わない。

従来manufacturer-only推定で新規登録できた機器は、serviceが取れなければ今回から
unknownになる。Presenceの実測`00 20`形式も未登録時は同様。既存登録は対応形式・
値が妥当なら継続利用できるが、既存hint自体が誤っている場合、矛盾する明示serviceが
来ない限り自動検出できない。対応形式の取得を確認する前に既存登録を削除しない。
未認識の新規個体を長さだけで自動判定しない。Presence、Meter、CO₂の明示選択方式は下記に限定する。

## direct / relay

BlueZ/Bleakのdirect callbackはmanufacturer/service辞書を共通decoderへ渡す。
NodeはAD type FFのcompany `0x0969`とtype 16のUUID `fd3d`を取り出し、company ID / UUID
を除いたpayload、BLE address、RSSIをprotocol v1のJSONで送る。上表のpayloadは
manufacturer最大16 bytes、service最大9 bytesで、各31-byte上限とJSON 512-byte上限内。
Gatewayは長すぎるデータを切り詰めず拒否し、UUIDの大小文字を正規化した重複も拒否する。

relayは同じBLE addressのADV / SCAN_RSPを結合する。fragment間に2秒を超える無受信期間が
あれば以前のfieldを破棄する。これはfieldごとの厳密な最大経過時間ではなく、連続受信中は
以前の片側fieldが残る可能性がある。原子的な同一packetの証明ではない。
受信fieldが同じならdirect/relayのmodel/value/keyは同じ。情報欠落ではunknownを許容し、
別modelへのメーカーlayout推定は行わない。relayのunknownは測定処理へ渡さない。
従来どおり登録済み一覧のlatestはdirect受信だけで更新する。relayによるMQTT測定値と
この一覧の受信状態は別で、relayだけの不正packetで一覧をunrecognizedには更新しない。
firmware、relay protocol、slot数、送信頻度は変更していない。

## 自動テストと実機確認計画

自動テストは衝突、hint矛盾、不正数値・状態、service欠落、同長未知payload、全8製品の
入力経路・MQTT・登録候補・登録済み一覧を確認する。既存captureの識別子は例示用に
置換し、温湿度・sequence・counter・state等の可変byteは別テストで変化させる。
MACのみの置換テストはidentity独立性の検査として区別する。relay C sourceは変更せず
ホストでfake clock/MQTTとコンパイルし、fragment完成前・結合後・gap失効後を確認する。

**エージェントによる実機操作は未実施**。候補版に対する利用者のPresence試験結果は下記に記録する。
過去の記録・利用者の試験・今回の自動テストを混同しない。
管理者が手元の個体で以下を確認する。新規captureを共有する場合は識別子を匿名化する。

| 機種 | 実機で確認すること | 別個体・firmware差 |
| --- | --- | --- |
| Plug Mini | service付きで新規識別、0 W/低負荷/ON-OFF、service欠落時は登録hintで継続。Outdoor表示にならない | 過去は複数個体、今回未実施。別firmwareを推奨 |
| Outdoor Meter | service `77`、温湿度・負温度、Plug風末尾値のときもservice/hintと一致 | 過去は1個体、2個体目を推奨 |
| Presence Sensor Pro | `00 20`のunknown候補から機種を明示確認して新規登録、再起動後のhint・在不在・battery・照度。不正値を蓄積しない。`70`形式は存在を含め別途確認 | 利用者が既存hint時の正常動作に加え、公開前の標準Pi4 fresh Gatewayで旧registryなしの初回登録を確認。受信形式・登録方式の別は未記録。別個体・modeを推奨 |
| Meter | `54` serviceの取得可否、manufacturer-onlyの未確認preview・明示登録、温湿度変化 | serviceなしで24.0 ℃ / 52 %の一致を利用者が確認。別個体を推奨 |
| Meter Plus | `69` service、温湿度・battery、共通内部modelと正常表示 | 別個体実測の確認資料なし。実機試験を推奨 |
| Meter Pro CO2 | `35` short service、manufacturer-onlyの未確認preview・明示登録、温湿度・CO2と本体表示の照合 | serviceなしの2台目で766 ppm / 25.5 ℃ / 45 %の一致を利用者が確認。異なるfirmware/modeを推奨 |
| Motion | `73` service単独、manufacturer-onlyはhint、検知/不在遷移、照度設定 | 過去は1個体、別個体を推奨 |
| Contact | `64` service、閉/開/閉じ忘れ、manufacturerとserviceの時間差、暗号化modeの拒否 | 既存fixture系列のみ。別個体を推奨 |

各試験で同じ内容のdirect/relay受信を比較し、登録候補・Dashboard値・MQTT・保存先に
誤modelの値が出ないことを確認する。受信fieldが違う場合はunknownを許容する。
残る限界は、未検証firmware/encoding、既存誤hint、BLE identityの偽装、fragmentの時間差。
今回、暗号学的identity確認や全SwitchBot model間のwire type一意性を証明したものではない。

## Presence service付き・manufacturer-only形式の初回登録

利用者がM1/M2候補版をGatewayで試験し、既存hintで在不在・照度・batteryの更新が
正常である一方、1台の登録を削除すると`unsupported_service_type`でunknownになると報告した。
今回報告されたrawの範囲は7-byte serviceの`00 20 xx xx xx xx xx`であり、完全な新規rawや
firmware番号は提供されていない。過去captureと先頭・長さは一致するが、残りのbyteまで
一致した、別個体を確認した、とは扱わない。

過去の保存済み監査・fixtureではserviceは`00 20 64 01 10 cc c8`。
manufacturerは先頭6-byte identityの後に`20 8c 00 04 00 8c`、
`1b cc 00 08 00 8c`等を観測した。

今回の追加実測は、新品microSDから構築したRaspberry Pi 4 Gateway、SwitchBotアプリで
Presence Sensor Proと確認した1個体で行われた。Pi内蔵Bluetoothではservice dataは取得できず、
匿名化した6-byte identityに続く12-byte manufacturer広告を継続受信した。未検出時は
`… 0a 8c 00 35 00 91` / `… 0e 8c 00 39 00 91`、検出時は
`… 0f cc 00 00 00 91` / `… 0f cc 00 01 00 91` / `… 0f cc 00 08 00 91` /
`… 0f cc 00 10 00 91`だった。実機操作でstatusが`0x8c → 0xcc`へ変化することと検知が
一致したため、既存どおりstatus bit 6をmotionとして使用する。末尾`0x91`はLED bit 7と
照度level 1を含む。これは1個体のlayout解釈の根拠であり、Presence固有の自動classifier根拠ではない。

| 部分 | 根拠と扱い |
| --- | --- |
| manufacturer index 6 | sequence（参照実装、実測で変動）。固定しない |
| manufacturer index 7 | adaptive / motion / battery range bits（参照実装）。在不在で`8c`/`cc`が変化。正常範囲は識別証拠ではない |
| manufacturer index 8/9 | 実測で`00 04`/`00 08`。固有性未確認、固定しない |
| manufacturer index 10 | trigger flag（参照実装）。実測の0を識別条件にしない |
| manufacturer index 11 | LED / light（参照実装、実測）。照度で変化、固定しない |
| service index 0/1 | `00 20`を同一個体で観測。機種固有という公開根拠なし |
| service index 2 | battery。過去は100%、今回利用者は更新を確認。0〜100を検証し固定しない |
| service index 3〜6 | 過去は`01 10 cc c8`。意味・個体差・firmware差が不明、固有IDとして使わない |

再調査した[公式BLE資料の機種一覧](https://github.com/OpenWonderLabs/SwitchBotAPI-BLE/tree/latest/devicetypes)
には、このPresence形式の公開仕様を確認できなかった。
旧参照commit `d2eafbaa`は`p` (`70`)からPresence parserを呼び、上記のmanufacturer値を
復号するが、`00 20`を一意に選択する規則はない。
現行参照commit [`0d2e215d96ae5d53e9467a70c99dc6747e457d3e`](https://github.com/OpenWonderLabs/node-switchbot/tree/0d2e215d96ae5d53e9467a70c99dc6747e457d3e)
の`src/types/ble.ts`はPresence=`06`とし、`src/ble.ts`は先頭byteの下位7 bitでmodelを選ぶ。
`src/devices/wo-presence.ts`も`00 20`の複合識別規則を提供していない。
この差だけではfirmware / broadcast modeの対応関係を証明できないため、`06`を追加せず、
既存`70`対応は参照実装由来・実機未確認として残す。

**判断B: 自動識別の根拠は不足。** 未知機器でも満たせる長さ・正常値・実測固定値を
組み合わせて`presence_legacy_observed`として確定することはしない。

### Presenceの未確認候補・明示登録方式

- 自動decoderの結果は`unknown_switchbot`のまま。candidate本体の`model`と`values`は
  unknown／空のままにする。正常センサの測定値ではない。
- serviceが空の12-byte manufacturer-only形式、または`00 20` service付きで既存Presence
  decoderを検証できる形式に限り、candidate APIに
  `manual_registration_models: ["presence_sensor"]`と`unconfirmed_preview`を付ける。
  これは識別結果ではなく登録選択肢。
- Dashboardで「Presence Sensor Pro と確認して登録」を選び、実物と対象候補を照合したことを未選択の
  checkboxで明示確認する。一般のunknownや他機種を任意modelへ変更するUIは作らない。
- 登録requestの`confirmed_model: "presence_sensor"`を利用者の機種指定として受け付ける。
  ID提案はregistryを変更しない。登録時には最新candidateのrawを再検証し、不正・未知type・
  明示typeとの矛盾・重複serviceは拒否する。登録済みidentityの重複は既存registryが拒否する。
- 検証に成功した場合だけ既存schemaでphysical keyに`presence_sensor`を保存する。
  確認直後のraw evidenceは`user_confirmed_presence_sensor`、再受信時は`registered_hint`になる。
  確認evidenceを永続保存するschema追加は行わない。
- 登録後も同じvalidationを通す。service付きではbattery/status/lightを返し、serviceなしでは
  status/lightだけを返す。M1の優先順位も不変。
- この形式を検証できたcandidateにだけ、`unconfirmed_preview.values`を付ける。Dashboardは
  「未確認プレビュー」「Presence Sensor Proとして解釈した参考値」
  と表示し、RSSI、最終受信時刻、identifier suffixとともに実物の操作との連動確認に使う。
  previewはhint、sensor ID、registered sensor、MQTT通常topic、Parquet・研究データ保存へ
  渡さない。packet更新時にはpreviewだけを更新し、malformed・矛盾・他機種のpacketでは消す。
- Dashboardはsetup scan中にcandidate APIを5秒ごとに`no-store`で再取得する。同じphysical
  keyの最新snapshotで候補カードを描き直すため、preview、RSSI、最終受信時刻、highlightも更新
  される。登録dialogは候補一覧の外にあるため、checkboxなどの入力状態は再描画しない。
  candidateの保持・scan終了時の既存ルールは変更しない。最終受信時刻を現在値と誤解しない。

### Motionの機種識別と測定値

- service type `0x73`はMotion Sensorの明示的な**機種識別**根拠である。未登録のmanufacturer-only packetは自動判定ではunknownのままとする。既存decoderで各modelとして再検証し、妥当な候補がちょうど1種類の場合だけ、利用者確認付きの「SwitchBot 人感センサー候補（未確認）」として登録できる。防水温湿度計等と同じ安全設計で、複数modelが成立する場合や妥当性を確認できない場合は登録選択肢を出さない。登録時も最新packetを再検証し、確認前のpreviewを通常の計測値として保存・送信しない。
- manufacturer 10-byte statusは機種識別根拠ではない。OMK実機ではserviceが約40秒
  `73 80 64 00 dd 0a`のままでもmanufacturer statusが`2c`から`6c`へ変化し、実物の
  検知と一致した。このstatus bit 6を**測定値**として使用する。
- Motionとしてserviceまたは登録hintで選択済みなら、妥当なmanufacturer statusをserviceの
  `motion_state`より優先する。両fieldは同じ時点のsnapshotとは限らないため、矛盾をunknownに
  しない。manufacturerが不正なら、妥当な`0x73` serviceの値へfallbackする。
- 登録済みMotionのmanufacturer-only受信は、既存hintとmanufacturer layout validationで継続復号する。
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

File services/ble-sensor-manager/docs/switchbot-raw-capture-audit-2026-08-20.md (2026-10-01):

# SwitchBot BLE raw capture監査（2026-08-20）

> この文書は過去の観測・当時の判定方針の記録です。M1/M2修正後はmanufacturer長・marker・正常値だけで新規modelを確定しません。現在の方針と根拠の再分類は[model evidence設計](switchbot-model-evidence.md)を参照してください。

## 目的と適用範囲

2026-08-19、SwitchBot CO2センサーのmanufacturer packetで、少数capture時に固定と見えたbyteをclassifierに使ったため、有効なBLEアドバタイズをdecoderが拒否した。この文書は、同じ問題を他機種で繰り返さないために、2026-08-20に所有実機から採取したraw BLEアドバタイズの観測結果を記録するものである。
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

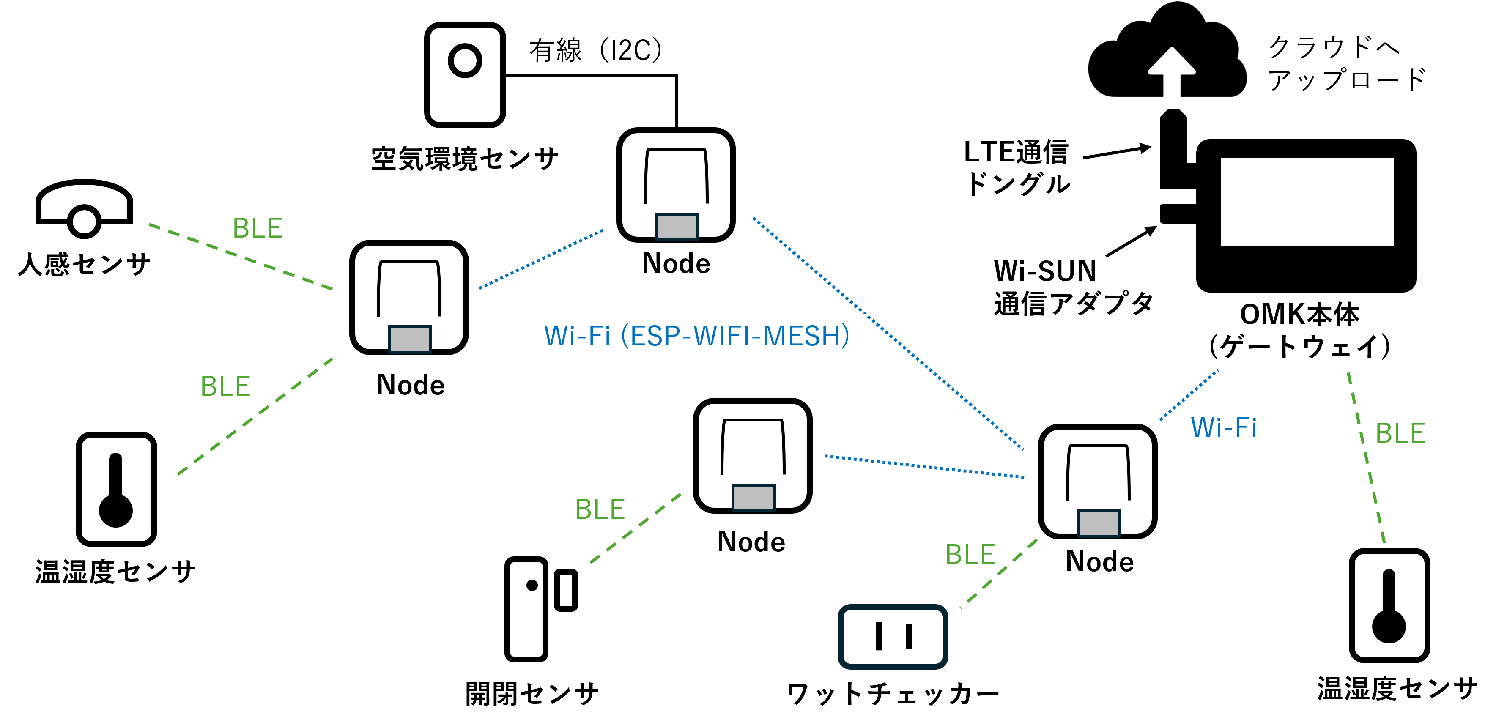
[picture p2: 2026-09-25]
docs/images/esp32-node/esp32-node-network-overview.png

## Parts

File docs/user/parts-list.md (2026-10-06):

# 2-1. OMKのパーツ構成

GatewayとSEN66 Nodeの製作に必要な部品・用品をそろえます。掲載している製品・購入先は参考例です。

- **必須**：Gatewayを動かすために必要なものです。センサ・Nodeの表では、その用途を選んだ場合に必要なものを示します。
- **推奨**：OMKで動作確認している構成に含まれるものです。
- **任意**：設置方法や用途に合わせて追加するものです。

初回は、以下のGateway構成（ケースを含む）と初回セットアップ用品、[SEN66 Node 1台分](#sen66-nodeを使う場合)、[工具・作業用品](#工具作業用品)をそろえてください。Bルートを使う予定でアダプタを用意している場合は、Gatewayの組み立て時に接続します。

## Gateway構成

OMKで動作確認している推奨構成は、Raspberry Pi 4、Raspberry Pi Touch Display 2（7インチ）、SORACOM Onyxです。

| 区分 | 部品 | 参考製品・実使用例 | 役割・選定条件 |
| --- | --- | --- | --- |
| 必須 | Gateway本体 | [Raspberry Pi 4 Model B / 2GB](https://www.switch-science.com/products/5681) | データの収集・保存とDashboardの表示 |
| 必須 | 電源 | [Raspberry Pi公式ACアダプター](https://www.switch-science.com/products/10259) | Raspberry Pi 4へ安定して給電できるもの |
| 必須 | microSDカード | SanDisk microSDXC 64GB SDSQQNR-064Gなど | OS・OMK・計測データの保存用。64GB以上を目安に、高耐久タイプを選びます。 |
| 推奨 | ディスプレイ | [Raspberry Pi Touch Display 2（7インチ）](https://www.switch-science.com/products/9940) | Gateway本体でDashboardを表示・操作 |
| 推奨 | 外部通信機器 | [SORACOM Onyx LTE USBドングル（SC-QGLC4-C1）](https://soracom.jp/store/7326/) | Gatewayのインターネット接続用 |
| Onyx利用時に必須 | SIM | [SORACOM Air SIMカード plan-D ナノSIM](https://soracom.jp/store/13380/) | 通信契約・通信料金が別途必要 |
| 推奨 | ディスプレイ用ケース | [SmartiPi Touch Pro 3 サイズS](https://smarticase.com/products/smartipi-touch-pro-3) | Raspberry Pi 4とTouch Display 2（7インチ）の両方に対応するもの |

このガイドではケースを含めて組み立てます。

### 初回セットアップに用意するもの

| 機材・環境 | 用途・必要になる場合 |
| --- | --- |
| Windows PC | Raspberry Pi ImagerでmicroSDへOSを書き込み、SSHでGatewayの初期設定を行う |
| microSDカードリーダー | PCにmicroSDカードスロットがない場合 |
| インターネットに接続できる既存Wi-Fi | 初回セットアップ時 |
| USBキーボード | AP切り替え後にGatewayのターミナルでBLE・Bルートサービスを設定する |

### 外部通信

標準構成ではOnyxと利用開始済みのSORACOM Air SIM（plan-D）を使います。事前に[SORACOM公式「利用開始手順」](https://users.soracom.io/ja-jp/guides/getting-started/)を参照し、アカウントとSIMを用意してください。

### Onyxの取り付け用部品（任意）

| 部品 | 参考製品・成果物 | 用途 |
| --- | --- | --- |
| USB回転コネクタ | [エスエスエーサービス USB A変換コネクタ（Aメス/Aオス 回転式）](https://www.amazon.co.jp/dp/B00OPYC7DK) | Onyxの向きを90度変えてGatewayの側面に沿わせる |
| Onyx固定用部品 | [onyx-usb-holder.stl](../../hardware/enclosures/omk-gateway/onyx-usb-holder.stl) | Onyxを固定する部品を3Dプリントする |

## Bルートを使う場合（任意）

| 区分 | 部品・情報 | 参考製品 | 用途 |
| --- | --- | --- | --- |
| 必須 | Wi-SUN USBアダプター | [ラトックシステム RS-WSUHA-P](https://www.ratocsystems.com/products/wisun/usb-wisun/rs-wsuha/) | GatewayへUSB接続し、低圧スマートメーターの電力データを受信 |
| 必須 | Bルートの利用申し込みとID・パスワード | 電力会社から発行される情報 | スマートメーターへの接続用 |

Bルートを使わない場合は、これらの準備は不要です。ID・パスワードが未発行でもGatewayのセットアップは進められます。

## SEN66 Nodeを使う場合

温度、相対湿度、CO₂、PM1.0、PM2.5、PM4.0、PM10、VOC Index、NOx Indexを計測する構成です。

| 区分 | 部品 | 参考製品・実使用例 | 用途・選定条件 |
| --- | --- | --- | --- |
| 必須 | 空気質センサ | [Sensirion SEN66](https://www.digikey.jp/ja/products/detail/sensirion-ag/SEN66-SIN-T/25700945) | 空気環境の計測 |
| 必須 | 接続基板 | [Adafruit SEN6x Breakout for Sensirion SEN66 - STEMMA QT / Qwiic](https://www.digikey.jp/ja/products/detail/adafruit-industries-llc/6331/26761418) | SEN66とAtomS3 Liteの接続 |
| 必須 | 小型端末 | [M5Stack AtomS3 Lite](https://www.switch-science.com/products/8778) | センサの値をGatewayへ送信 |
| 必須 | Grove/Qwiic変換ケーブル | [Adafruit 4-PIN STEMMA/GROVE - QT/QWIIC 4"変換ケーブル](https://www.digikey.jp/ja/products/detail/adafruit-industries-llc/4528/11627737) | 接続基板とAtomS3 Liteを接続 |
| 必須 | SEN66用ケーブル | [Adafruit #5754 JST GH 1.25MM PITCH 6 PIN CABLE](https://www.digikey.jp/ja/products/detail/adafruit-industries-llc/5754/21839797) | 両端のコネクタの表裏の向きが反転したもの。代替品はAdafruit 5754と向き・配線が同じものを選びます。 |
| 必須 | USB-C to USB-Aケーブル | [Anker Zolo USB-C & USB-A ケーブル 1.0m](https://www.ankerjapan.com/products/a8052)など | 初期設定にも使うため、データ通信・給電の両方に対応したもの |
| 必須 | USB電源 | USB-A出力のACアダプター（5V、1A以上を目安） | 設置場所での常時給電 |
| 初回ガイドで使用 | ケース | [ケースのSTLデータ](../../hardware/enclosures/sen66-node/) | ケース本体と蓋を3Dプリントする |
| 初回ガイドで使用 | ネジ | M3×8mmネジ6本 | ケースの蓋を固定する |
| 任意 | ケーブル固定具 | [sen66-node-cable-jig.stl](../../hardware/enclosures/sen66-node/sen66-node-cable-jig.stl) | 適合するUSBケーブルが抜けにくくなる。固定具なしでも利用できます。 |

ケーブル固定具はAnker Zolo USB-C & USB-A ケーブルへの適合を確認しています。別製品はUSB-Cプラグ周辺の形状が合わない場合があります。

## 工具・作業用品

GatewayとSEN66 Nodeの組み立てで使う工具を、作業前に用意してください。

| 工具・作業用品 | 用途・条件 |
| --- | --- |
| ケース組み立て用ドライバー | SmartiPi Touch Pro 3の付属ネジに合うもの |
| カッター | SmartiPi Touch Pro 3 サイズSのポートカバーを、使用する端子に合わせて切り抜く作業に使用 |
| M3タップとタップハンドルなどの加工用工具 | 電子部品を入れる前にSEN66ケースのネジ穴を加工する |
| SEN66ケース用ドライバー | 用意したM3×8mmネジの頭に合うもの。Gateway用と合えば兼用できます。 |

## このページの完了と次の手順

GatewayとSEN66 Node 1台分の部品、初期設定用のPC・ネットワーク・工具を用意できたら準備完了です。

次へ：[「2-2. Gatewayの組み立て」](gateway-assembly.md)

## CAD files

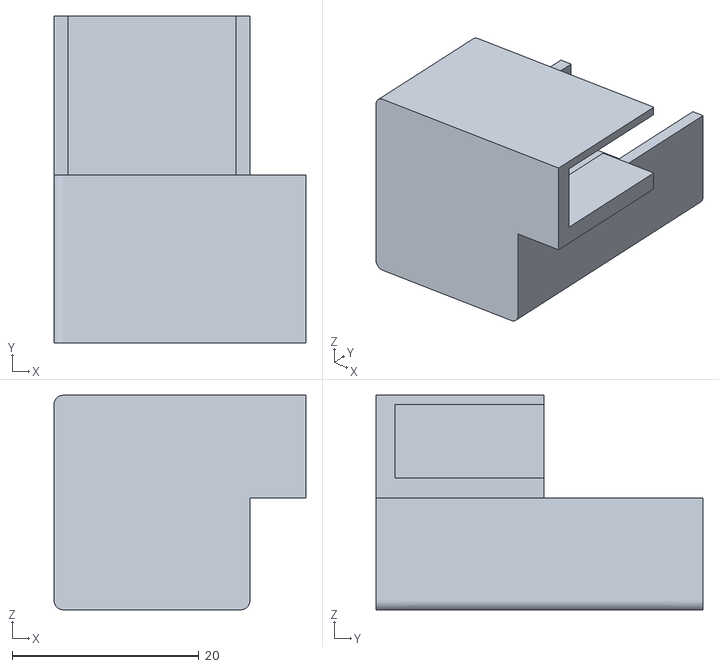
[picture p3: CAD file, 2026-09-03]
hardware/enclosures/omk-gateway/onyx-usb-holder.stl
27.0 x 35.0 x 23.0

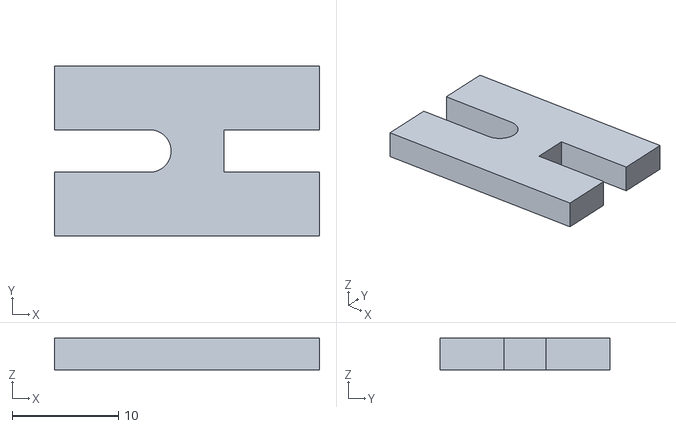
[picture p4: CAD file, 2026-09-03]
hardware/enclosures/sen66-node/sen66-node-cable-jig.stl
25.0 x 16.0 x 3.00

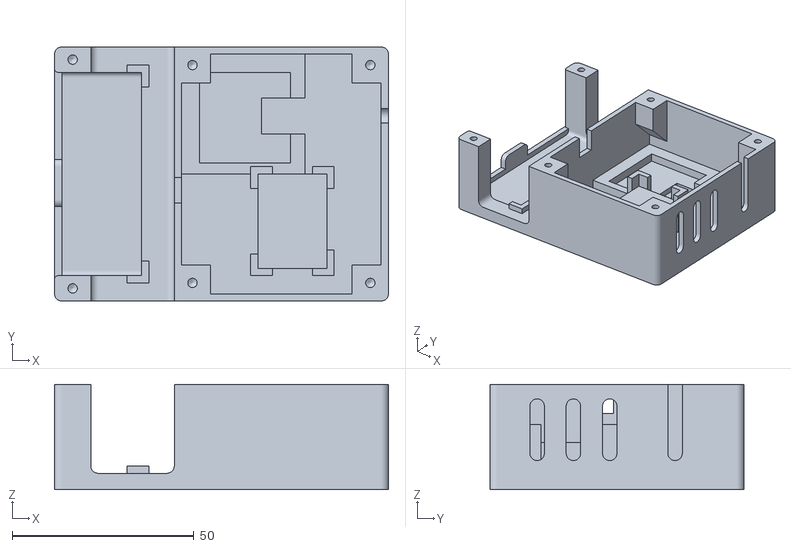
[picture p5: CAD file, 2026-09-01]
hardware/enclosures/sen66-node/sen66-node-body.stl
92.0 x 70.0 x 29.0

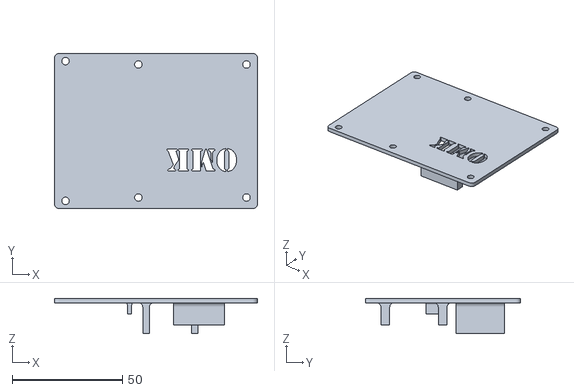
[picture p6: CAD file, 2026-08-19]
hardware/enclosures/sen66-node/sen66-node-lid.stl
92.0 x 70.3 x 16.0

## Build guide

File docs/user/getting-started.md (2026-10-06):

# 1-1. OMK導入ガイド

おうちモニタキット（OMK）は、住宅の電力・環境・行動を計測するシステムです。データを収集・保存するOMK Gateway、計測するセンサ・機器、現在の値と機器の状態を表示するDashboardで構成します。

推奨するGateway構成は、Raspberry Pi 4、Touch Display 2（7インチ）、SORACOM Onyxです。Gatewayのセットアップ後に、空気質センサのSEN66とAtomS3 Liteを組み合わせた「SEN66 Node」を1台製作し、計測を始めます。

分からない用語がある場合は[「用語集」](glossary.md)を参照してください。

## 導入の順序

| 章 | 行うこと | 章の終了時に確認すること |
| --- | --- | --- |
| 2. OMK Gatewayを製作・セットアップする | 部品を用意し、Gatewayを組み立て、OSとOMKを設定する | Dashboard、保存機能、OMK AP、Gateway側のBLE・Bルートサービスが準備でき、Gatewayのセットアップが完了している |
| 3. SEN66 Nodeを製作・セットアップする | SEN66 Nodeを組み立て、設定・登録し、設置する | 実際の計測値がGatewayへ届き、Dashboardの値と最終更新が更新される |
| 4. Dashboardを使う | Touch Display 2で表示設定、機器の状態確認、データ書き出しの方法を確認する | 日常の計測確認とデータの取り出しができる |

各ページ末尾の「次へ」に沿って進めてください。まず対応機器と計測項目を確認し、部品の準備、Gatewayの製作、SEN66 Nodeの製作、Dashboardの操作へと進みます。

## OMKのハードウェア構成とデータの流れ

```mermaid
flowchart LR
    sen66["SEN66"] -->|配線| node["SEN66 Node<br/>AtomS3 Lite"]
    node -->|Wi-Fi| gw["OMK Gateway<br/>Raspberry Pi 4<br/>データ収集・保存<br/>Dashboard"]
    ble["BLEセンサ<br/>SwitchBotなど"] -->|BLE| gw
    meter["スマートメーター"] -->|Wi-SUN| adapter["RS-WSUHA-P"]
    adapter -->|USB| gw
    gw -->|配線| display["Touch Display 2"]
    gw -->|USB| onyx["SORACOM Onyx"]
    onyx -->|LTE| external["外部通信<br/>遠隔管理・クラウド送信"]
    classDef gateway fill:#163a63,color:#fff,stroke:#071f3a,stroke-width:4px,font-size:20px;
    class gw gateway;
```

- Gatewayがセンサからデータを集めて保存し、Touch Display 2にDashboardを表示します。
- SEN66 Nodeは、配線したSEN66の計測値をWi-FiでGatewayへ送ります。Gatewayと通信できる位置へ設置します。
- BLEセンサはGatewayで直接受信できます。
- Bルートを使う場合は、RS-WSUHA-Pがスマートメーターと通信します。
- OnyxはGateway自身の外部通信に使います。SORACOM Harvestへの送信や遠隔管理には、利用するサービス側の設定も必要です。

## OMK内部をつなぐネットワーク

図のNodeとGatewayのWi-Fi通信には、Gatewayが用意するOMK APを使います。APはAccess Point（アクセスポイント）の略です。OMK APは、Gateway・Node・管理端末を結ぶOMK専用のローカルネットワークです。

初回セットアップでは、パッケージを取得するために既存Wi-Fiでインターネットへ接続します。OMK APへ切り替えると、Raspberry Piの内蔵Wi-FiはAP専用になり、既存Wi-Fiには接続しなくなります。その後、Gateway自身の外部通信はOnyxが担います。

OMK APへ接続した端末のインターネット通信は、Gateway経由では転送しません。管理端末の通信によって意図せずSORACOMの通信量・料金が増えることを防ぎます。構築後のローカル計測・保存・表示は、住宅側ネットワークに依存せず利用できます。

次へ：[「1-2. 対応センサ・機器と取得データ」](supported-devices.md)

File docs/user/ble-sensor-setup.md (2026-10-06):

# BLEセンサを追加する

推奨構成の製作が完了した後で、SwitchBotなどのBLEセンサをGatewayへ追加する手順です。GatewayのBLE Sensor Managerを導入済みで、Touch Display 2からDashboardを操作できることを確認してください。

## 用意するセンサ

計測したい内容に合わせて選びます。次の製品は参考例です。

| 用途 | 参考製品 |
| --- | --- |
| 人感・在不在 | [SwitchBot 人感センサーPro](https://www.switchbot.jp/products/switchbot-presence-sensor) |
| ドア・窓の開閉 | [SwitchBot 開閉センサー](https://www.switchbot.jp/products/switchbot-contact-sensor) |
| 消費電力・電源状態 | [SwitchBot プラグミニ（JP）](https://www.switchbot.jp/products/switchbot-plug-mini) |
| 温度・湿度 | [SwitchBot 温湿度計](https://www.switchbot.jp/products/switchbot-meter) |
| CO₂濃度・温度・湿度 | [SwitchBot CO2センサー（Meter Pro CO2）](https://www.switchbot.jp/products/switchbot-co2-meter) |
| 温度・湿度（防水タイプ） | [SwitchBot 防水温湿度計](https://www.switchbot.jp/products/switchbot-indoor-outdoor-meter) |

## この手順の前に

- 対応機種を[「1-2. 対応センサ・機器と取得データ」](supported-devices.md#switchbot対応機器)で確認します。
- センサの電源を入れ、Gatewayの近くへ置きます。BluetoothペアリングやSwitchBotハブとの接続は不要です。

## BLEセンサを探索して登録する

1. 管理メニューの「機器管理」を開き、「センサを追加」を押します。
2. 対象のセンサの「このセンサを登録」を押します。
3. 登録画面で次の項目を入力します。

   | 項目 | 入力内容 |
   | --- | --- |
   | OMK センサID | センサを区別するID。自動入力された候補をそのまま使えます。 |
   | 表示名 | Dashboardに表示する名前。例：リビング |
   | 設置場所（任意） | 設置位置のメモ |

4. 「登録する」を押します。
5. 「登録済みセンサ」に対象が表示され、「最終受信」が更新され、状態が「正常」になれば登録・受信を確認できます。

登録後は設置場所へ戻し、「最終受信」が更新されることを確認します。候補に出ない場合は[「トラブルシューティング」](troubleshooting.md#センサや機器の値が更新されない)を参照してください。

### 「候補（未確認）」と表示された場合

これは受信した機器の機種をまだ確定できていないという表示です。製品自体の実機試験の有無を示すものではありません。参考値は登録確認用で、登録前の計測データとしては保存・送信されません。

防水温湿度計や人感センサーなどは、機種を自動判定できず「候補（未確認）」と表示されることがあります。実物の機種と候補名を照合し、カードの「未確認プレビュー」を見ます。温湿度計を手で温めたときに温度が上がるか、人感センサーの前で動いたときに検知状態が変わるかで、対象の機器かを確かめます。

対象の機器だと分かったら、機種名の付いた「…と確認して登録」を押します。登録画面の実物確認欄にチェックを入れ、上と同じ項目を入力して「登録する」を押します。「未対応のSwitchBot機器」は登録できません。

### 登録内容を変更・削除する

「登録済みセンサ」の「編集」でID、表示名、設置場所を変更し、「保存する」を押します。「このセンサを有効にする」のチェックで有効・無効を切り替えられます。

「センサ登録を削除」は登録情報を削除する操作です。過去の計測データは残ります。

## 追加完了の確認

設置場所でセンサの「最終受信」が更新され、状態が「正常」になれば追加完了です。Dashboardの表示設定で「おすすめ」を選び、計測値を確認します。

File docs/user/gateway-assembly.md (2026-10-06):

# 2-2. Gatewayの組み立て

用意したRaspberry Pi 4、Touch Display 2（7インチ）、SmartiPi Touch Pro 3 サイズSを組み立てます。メーカーの手順に沿いながら、OMK用の接続を整える補助ガイドです。

Touch Display 2とケース、Onyxを組み合わせたOMK Gatewayの完成例。画面はセンサ追加後の表示

写真はセンサ追加後の完成例です。このページでは組み立てまで行い、OSとDashboardは次のページで設定します。

## この手順の前に

- Raspberry Piの電源とUSB機器をすべて外します。ディスプレイのケーブルやGPIO電源線は、電源を切ってから接続してください。
- ケース・ディスプレイの付属品、ネジに合うドライバー、ポートカバー加工用のカッター、Onyx、利用開始済みのSORACOM Air SIM（nano SIM、plan-D）、USBキーボードを用意します。
- microSDへのOS書き込みは次のページで行います。組み立て中はカードを入れず、カードの差し込み口へ後からアクセスできるようにします。

## 1. 公式手順でケースとディスプレイを組む

[SmartiPi Touch Pro 3公式組み立てガイド](https://smarticase.com/pro3)の、**Raspberry Pi Official Display 2とRaspberry Pi 4**の説明に従います。OMK標準構成ではカメラやHATを追加しません。

1. ディスプレイ側に映像ケーブルと電源ケーブルを取り付けます。Pi 4にはTouch Display 2付属のPi 4用ケーブルを使い、Pi 5用と取り違えないでください。
2. ディスプレイをケース前面へ収め、公式手順のネジと取り回しで固定します。
3. ケース付属のmicroSD延長部品を取り付け、Raspberry Pi 4を固定します。USB端子がケース外から使える通常の取り付け位置にします。
4. ディスプレイの映像ケーブルをPiの**DISPLAY（DSI）端子**へ、電源線をGPIOへ接続します。microSD延長部品をPiのカードスロットへ接続します。

端子の向きは[Raspberry Pi公式のTouch Display 2接続手順](https://www.raspberrypi.com/documentation/accessories/touch-display-2.html)のPi 4向け説明・写真で照合してください。カメラ端子と取り違えず、コネクタのロックを開けてからケーブルを差し、最後にロックを戻します。GPIOの電源線は指定のピン位置・向きに合わせます。

## 2. ケースを閉じて設置する

1. ケーブルがネジ穴や蓋の縁に重ならず、折れ曲がりや引っ張りがないことを確認します。
2. ポートカバーを使う場合は、公式手順に沿ってカッターで使用する端子の部分を切り抜きます。背面カバーと台座を固定します。ケース上部のmicroSD差し込み口と、USB・電源端子を使える状態にします。
3. Raspberry Pi 4用電源を接続できるようにケーブルを配置します。まだコンセントへはつなぎません。画面の横向き表示は次のソフトウェアセットアップで設定します。

## 3. SIMとOnyxを取り付ける

OnyxはUSBへ接続する前に、[SORACOM公式のSIM挿入手順](https://users.soracom.io/ja-jp/guides/usb-dongles/soracom-onyx/hardware/)に従い、本体のイラストとSIMの向きを照合して挿入し、カバーを閉じます。その後、OnyxをRaspberry PiのUSB端子へ接続します。

回転コネクタと3Dプリント固定具を用意した場合は、この段階で取り付けます。取り付け条件は[「OMK Gateway筐体」](../../hardware/enclosures/omk-gateway/README.md)を参照してください。USB端子に力をかけず、Onyxの放熱を妨げないようにします。

## 4. Bルート用アダプタを接続する（利用する場合）

Bルートを使う予定でRS-WSUHA-Pを用意している場合は、GatewayのUSB端子へ接続し、そのまま次のセットアップへ進みます。

Bルートを使わない場合、またはアダプタをまだ用意していない場合は、未接続で進められます。

## 5. ソフトウェア設定を始められる状態にする

- Touch Display 2がケース内に固定され、Piへ映像・電源の両方が接続されている。
- SIMを入れたOnyxがPiのUSB端子へ接続されている。
- USBキーボードをPiへ接続してある（AP切り替え後に使用）。
- microSDを挿せる状態で、Piの電源はまだ入れていない。
- Bルートを使い、RS-WSUHA-Pを用意している場合はUSBへ接続してある。使わない場合や未入手の場合は未接続でよい。

これでGatewayの物理的な組み立てが完了しました。

次へ：[「2-3. Gatewayセットアップ」](gateway-setup.md)

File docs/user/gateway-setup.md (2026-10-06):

# 2-3. Gatewayセットアップ

組み立てたGatewayにOSとOMKを設定します。Windows PCから始め、OMK AP切り替え後はGatewayのTouch Display 2とUSBキーボードで操作します。

## この手順の前に

- Touch Display 2、ケース、Raspberry Pi 4の組み立てを済ませ、USBキーボードを接続します。
- 利用開始済みのSORACOM Air SIM（nano SIM、plan-D）をOnyxへ挿し、OnyxをGatewayへUSB接続しておきます。ほかのUSBモデムは接続しません。
- 64GB以上を目安にしたmicroSD、カードリーダー、Windows PC、インターネットに接続できる既存Wi-Fiを用意します。スマートフォンのテザリングを既存Wi-Fiとして使用する場合は、作業中に自動停止しない設定にしてください。
- Bルートを使用する場合はRS-WSUHA-PをGatewayへ接続します。組み立て時に接続済みの場合はそのまま使用します。未使用・未入手の場合は、未接続のままセットアップを完了して問題ありません。
- Gatewayの電源はOS書き込み後に入れます。

コマンドは1つずつ実行し、エラーが出たら次へ進まず[「トラブルシューティング」](troubleshooting.md#パッケージやomkのダウンロードが失敗する)を参照してください。

## 1. Raspberry Pi ImagerでOSを書き込む

Windows PCにmicroSDカードを接続し、Raspberry Pi Imagerで次を選びます。

- 機器：Raspberry Pi 4
- OS：**Raspberry Pi OS（Debian 13 / Trixie、64ビット、デスクトップあり）**
- 書き込み先：用意したmicroSDカード

書き込み前のOSカスタマイズで、次を設定してください。

| 項目 | 設定内容 |
| --- | --- |
| ホスト名 | 同じネットワーク内で重複しない名前（例：`omk-gateway`） |
| 地域（Localisation） | Tokyoを選択し、タイムゾーンが`Asia/Tokyo`になっていることを確認する |
| ユーザー名 | `omkdev` |
| パスワード | 自分で決めたパスワード。SSH接続と`sudo`で使うため、安全な場所に記録する |
| Wi-Fi | 初期設定に使う既存Wi-FiのSSIDとパスワード |
| SSH | `Enable SSH`を有効にし、`Use password authentication`を選択 |
| Raspberry Pi Connect | `Enable Raspberry Pi Connect`はOFF |

Imagerの画面操作は[Raspberry Pi公式ガイド](https://www.raspberrypi.com/documentation/computers/getting-started.html#install-using-imager)も参照してください。

書き込みと検証が完了したら、PCからmicroSDを安全に取り外してGatewayのカードスロット（組み立てたケースのmicroSD延長部品）へ挿します。Touch Display 2、SIM入りOnyx、USBキーボードの接続を確かめ、Piの電源を入れて起動を待ちます。

## 2. GatewayへSSH接続する

この手順ではWindows PowerShellからSSH接続します。PuTTYなど、他のSSHクライアントを使用しても構いません。

PowerShellを使う場合は、まず次を実行します。

```powershell
ssh -V
```

OpenSSHのバージョンが表示されれば、下のSSH接続手順へ進みます。`ssh`コマンドが見つからない場合は、Windowsの「オプション機能」から「OpenSSH Client」を追加し、もう一度`ssh -V`を実行してください。

Windows PCをRaspberry Piと同じ既存Wi-Fiへ接続し、Windows PowerShellで次を実行します。`<ホスト名>`はImagerで設定した名前に置き換えてください。

```powershell
ssh omkdev@<ホスト名>.local
```

初回は接続先の確認が表示されます。表示された接続先を、Imagerで設定したホスト名に`.local`を付けたものと照合します。IPアドレスを指定した場合は、[「トラブルシューティング」](troubleshooting.md#windowsからホスト名で接続できない)の手順でGateway上のIPアドレスを調べ、その値と照合します。一致していたら`yes`を入力し、続いてImagerで設定したパスワードを入力します。パスワード入力中は文字や`*`が表示されません。入力後にEnterを押してください。

ホスト名で接続できない場合は、[「トラブルシューティング」](troubleshooting.md#ssh接続できない)を参照してください。

## 3. GitHubからOMKのソースコードを取得する

SSH接続先のGatewayで、次を実行します。`git clone`は、GitHubからOMKのソースコード一式を`~/projects/omk`へダウンロードするコマンドです。

```bash
mkdir -p ~/projects
cd ~/projects
git clone https://github.com/shattori-criepi/omk.git omk
cd omk
```

## 4. Gatewayのセットアップを開始する

以下はGateway上のコマンドです。初回だけ`--with-base`を付け、OS更新とDockerを導入します。`--with-soracom`により、基本設定の後にOnyxの設定も実行されます。Onyxはこのコマンドの前から接続しておいてください。

```bash
./scripts/setup-omk-gateway.sh --with-base --with-soracom
```

`sudo`のパスワードを求められたら、Imagerで設定した`omkdev`のパスワードを入力します。

## 5. 基本設定後にセットアップを再開する

OSなどの基本設定が`Setup result: SUCCESS`で完了し、再起動または再ログインが必要な場合、セットアップはいったん停止して操作を案内します。画面に表示された方の操作を行い、接続し直してセットアップを再開します。案内なしで処理が続く場合は、そのまま手順6の確認メッセージへ進みます。`Setup result: FAILURE`なら基本設定未完了なので、再起動表示だけで完了と判断せず[「トラブルシューティング」](troubleshooting.md#パッケージやomkのダウンロードが失敗する)を参照してください。

### 再起動のメッセージが表示された場合

```text
A reboot is required. Reboot, reconnect, then rerun this command without --with-base to resume.
```

Gatewayで次を実行します。

```bash
sudo reboot
```

起動を待ち、手順2と同じコマンドでSSH接続し直します。

### 再ログインのメッセージが表示された場合

```text
Docker group membership needs a new login session. Re-login, then rerun this command without --with-base to resume.
```

`exit`でSSHを切断し、手順2と同じコマンドで接続し直します。

### 再接続後にセットアップを再開する

どちらの場合も、再接続後は次を実行します。**再開時は`--with-base`を外してください。**

```bash
cd ~/projects/omk
./scripts/setup-omk-gateway.sh --with-soracom
```

## 6. OMK APへの切り替え

手順4・5のスクリプトは、Onyx設定、Dashboardとデータ保存などのサービス準備・起動を行い、最後にOMK APへ切り替えます。**ここでスクリプトを追加実行する必要はありません。**

OMK APはGateway・Node・管理端末をつなぐローカルネットワークです。PCやNodeのインターネット通信はGateway経由では転送しません。外部通信はGateway自身がOnyxを使うため、AP側端末の通信でSORACOM回線を意図せず消費しません。

有効化するとPiの内蔵Wi-FiはOMK専用となり、既存Wi-Fiから切断されます。**切り替え前に、PCのSORACOMユーザーコンソールで対象SIMのセッション状態が「オンライン」になっていることを確認してください。** つながらなければ[「トラブルシューティング」](troubleshooting.md#onyxで外部通信できない)を確認してから進みます。Onyx設定で`Optional external DNS/HTTPS reachability check failed`等の`WARNING`が出た場合も、後続のダウンロードに必要な外部通信を復旧してからAPを有効化します。SIMの「オンライン」だけでは外部通信まで確認できません。

実行中の確認には、表示された順に答えます。設定済みの項目では一部の確認が省略される場合があります。

| 確認メッセージ | 入力・操作 |
| --- | --- |
| `Apply these NetworkManager profile changes? [y/N]` | `y`を入力する |
| `Show the OMK AP password now? [y/N]` | 既定の`N`のままEnterを押す |
| `Activate omk-ap now? This can disconnect SSH [y/N]` | Onyxの接続を確認後、`y`を入力する |

最終AP切り替えは独立した処理として実行されるため、この時点のSSH切断後も進みます。`queued`という表示は切り替えの受付であり、完了の判定は手順9で行います。これより前のダウンロード中などの通信断は、[「トラブルシューティング」](troubleshooting.md#パッケージやomkのダウンロードが失敗する)で対処してください。

### AP切替後の操作方法

ここからは**GatewayのTouch Display 2とUSBキーボード**を使います。`Ctrl+Alt+T`でターミナルを開き、次の手順7・8のコマンドを本体上で実行します。パスワードを求められたらImagerで決めた`omkdev`のパスワードを入力します。ダウンロードにはOnyxを使います。

PCのWi-Fi一覧でGatewayの`OMK-XXXXXX`形式のSSIDが見えることを確かめ、次へ進んでください。見つからない場合は[「トラブルシューティング」](troubleshooting.md#omk-apがwi-fi一覧に見えない)を参照します。

## 7. BLE Sensor Managerを設定する

GatewayでBLEセンサを扱うために必要な機能を導入します。Gateway上で次を実行してください。パッケージの取得にはOnyx経由のインターネット接続を使います。

```bash
cd ~/projects/omk
./scripts/setup-ble-sensor-manager.sh
```

スクリプトが完了したら、サービスの状態を確認します。

```bash
systemctl is-active omk-ble-sensor-manager.service
```

`active`なら次へ進みます。それ以外ならセットアップのエラーを確認し、[「トラブルシューティング」](troubleshooting.md#パッケージやomkのダウンロードが失敗する)を参照してください。

## 8. Bルートサービスを準備する

### この手順の前に

- RS-WSUHA-Pを接続済みなら、そのまま使用します。
- Bルートを使う予定で、用意したRS-WSUHA-Pをまだ接続していない場合は、ここでGatewayのUSBへ接続します。
- 未使用・未入手なら、アダプタ未接続でも進められます。

Onyxは外部通信のため接続したままにします。この工程ではBルートサービスを導入し、接続済みならアダプタも設定します。BルートID・パスワードは不要です。

Gateway本体のターミナルで実行します。

```bash
cd ~/projects/omk
./scripts/setup-broute-meter.sh
```

- RS-WSUHA-Pを接続している場合：`Use this FT230X serial adapter as RS-WSUHA-P? ... [y/N]`と表示されたら、接続した実物がRS-WSUHA-Pであることを確認して`y`を入力します。シリアルポートが設定され、サービス起動を試みます。設定済みなら、この確認は表示されません。抜き差しを求められた場合はRS-WSUHA-Pだけを抜き、数秒待って同じUSB端子へ接続し直します。
- アダプタ未接続の場合：シリアルポート未設定のまま、サービスを導入・有効化して終了します。

アダプタやBルートID・パスワードが未設定である旨の警告は、この段階では正常です。アダプタを接続していても、認証情報が未登録ならサービスが`active`にならない場合があります。サービスが停止していることも起動していることも、Gatewayの完了条件にはしません。`ERROR`で終了した場合は次へ進まず、[「トラブルシューティング」](troubleshooting.md#パッケージやomkのダウンロードが失敗する)を参照してください。

```bash
systemctl is-enabled omk-broute-meter.service
```

スクリプトがエラーなく完了し、`enabled`ならサービスの準備完了です。

## 9. セットアップ完了を確認する

ターミナルを閉じ、Touch Display 2で次を確認します。

- Dashboardの表示画面が開き、右上の歯車から管理メニューを操作できる。
- 「機器管理」が開き、BLE Sensor Managerへの接続エラーが出ない（機器は未登録で構いません）。
- 「Bルート設定」が開く。ID・パスワードは「未設定」で正常です。接続状態の表示はアダプタ設定やサービス起動状態によって変わるため、「サービス停止」を固定の条件にしません。
- 「OMKアクセスポイント参照」のSSIDが、PCやスマートフォンのWi-Fi一覧に見える。
- 手順7・8のセットアップがエラーなく完了し、BLEサービスは`active`、Bルートサービスは`enabled`になっている。

センサを追加していないので、計測値が空でも正常です。画面が出ない場合は[「トラブルシューティング」](troubleshooting.md#touch-display-2にdashboardが表示されない)を参照してください。

**これでGatewayのセットアップが完了しました。** Dashboard・保存機能・OMK APとGateway側のBLE・Bルート機能が準備できました。

次へ：[「3-1. SEN66 Nodeの組み立て」](sen66-node-assembly.md)

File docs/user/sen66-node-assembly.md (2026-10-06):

# 3-1. SEN66 Nodeの組み立て

SEN66とAtomS3 Liteを接続し、3Dプリントした試作ケースへ収める手順です。このページでは配線までを行い、蓋を開けたまま次の初期設定・計測確認へ進みます。

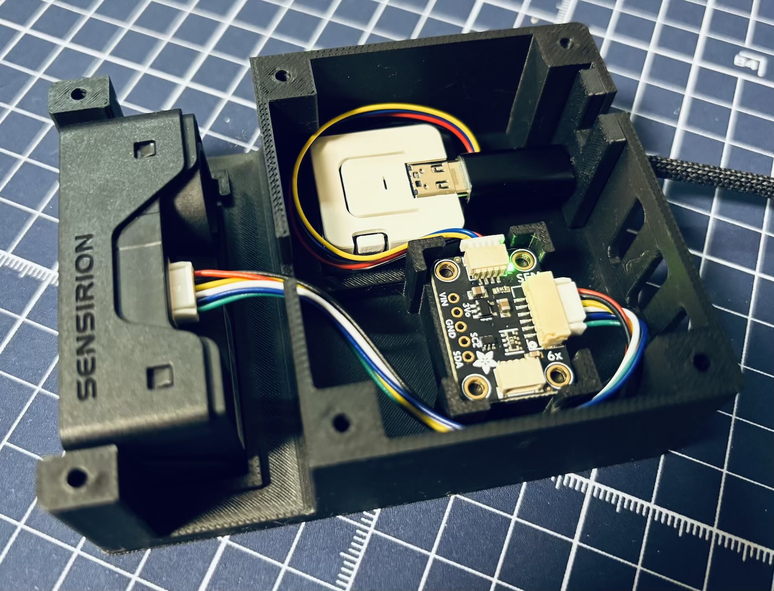
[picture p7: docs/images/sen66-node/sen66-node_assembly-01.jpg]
蓋を外したSEN66 Node。左にSEN66、右手前に接続基板、右奥にAtomS3 Liteを配置した組み立て例


SEN66 NodeはOMKの推奨センサ構成です。OMKの利用に必須ではありませんが、初回は動作確認も兼ねて1台製作します。

## この手順の前に

Gatewayのセットアップを終え、Dashboardを使える状態から始めます。以下の部品と3Dプリントしたケースをそろえ、**AtomS3 LiteのUSBをGatewayや電源へつながない状態**で組み立てを始めます。SEN66の配線が終わってから、次のページでGatewayへUSB接続します。

## 必要な部品

実際に使用している参考構成です。別製品を選ぶ場合は、下のケーブル・固定具の条件に合わせてください。価格、在庫、納期は各販売元で確認できます。

| 部品 | 使用・参考製品 | 用途・条件 |
| --- | --- | --- |
| 空気質センサ | [Sensirion SEN66](https://www.digikey.jp/ja/products/detail/sensirion-ag/SEN66-SIN-T/25700945) | 温湿度・空気質の計測用 |
| 接続基板 | [Adafruit SEN6x Breakout for Sensirion SEN66 - STEMMA QT / Qwiic](https://www.digikey.jp/ja/products/detail/adafruit-industries-llc/6331/26761418) | SEN66とAtomS3 Liteを接続 |
| Node用ハードウェア | [M5Stack AtomS3 Lite](https://www.switch-science.com/products/8778) | 次の工程でOMK Nodeとして設定し、センサのデータをGatewayへ送信 |
| SEN66用ケーブル | [JST GH 1.25MM PITCH 6 PIN CABLE 100mm（Adafruit 5754）](https://www.digikey.jp/ja/products/detail/adafruit-industries-llc/5754/21839797) | SEN66と接続基板の接続用 |
| Grove/Qwiic変換ケーブル | [4-PIN STEMMA/GROVE - QT/QWIIC 4"変換ケーブル 100mm](https://www.digikey.jp/ja/products/detail/adafruit-industries-llc/4528/11627737) | 接続基板とAtomS3 Liteの接続用 |
| ケース | 3Dプリントしたケース本体と蓋 | データは[STL](#stl)を参照 |
| ネジ | M3×8mmネジ6本 | 蓋の固定用 |
| ケーブル固定具（任意） | 3Dプリントした固定具 | 適合するUSBケーブルを使う場合に、必要に応じて使用 |
| USB電源 | USB-A出力のUSB電源 | 設置後の常時給電用 |
| USB-C to USB-Aケーブル | [Anker Zolo USB-C & USB-A ケーブル](https://www.ankerjapan.com/products/a8052)など | Nodeの初期設定に使うため、データ通信・給電の両方に対応したもの |

## 工具・作業用品

| 工具・作業用品 | 用途・条件 |
| --- | --- |
| M3タップとタップハンドルなどの加工用工具 | 電子部品を入れる前にケースのネジ穴を加工する |
| ドライバー | 用意したM3×8mmネジの頭に合うもの。蓋の固定用 |

## ケーブル・固定具の条件

- **SEN66用ケーブル**：Adafruit 5754は、両端のコネクタの表裏の向きが反転したケーブルです。別のJST-GH 1.25mm 6ピンケーブルを使う場合は、コネクタ形状だけでなく、両端の向きと配線がAdafruit 5754と同じ製品を選んでください。
- **ケーブル固定具（任意）**：適合するケーブルで必要に応じて使用すると、USBケーブルが抜けにくくなります。適合を確認しているのはAnker Zolo USB-C & USB-A ケーブルです。別製品ではUSB-Cプラグ周辺の形状が合わない場合があります。収まらないものは無理に押し込まないでください。固定具なしでもSEN66 Nodeを構築・利用できます。

## 組み立ての流れ

1. ケース本体・蓋（使用する場合はケーブル固定具も）に割れ、反り、穴の詰まりがないかを見ます。電子部品を入れる前に、ネジ穴へM3タップ加工をします。
2. 加工で出た樹脂の切りくずやゴミを取り除きます。
3. **USB給電を外した状態で**、SEN66と接続基板の6ピン端子を、SEN66用ケーブルでつなぎます。コネクタの突起と差し込み口の形を合わせ、無理に押し込まず奥まで差し込みます。
4. 接続基板のSTEMMA QT / Qwiic端子とAtomS3 LiteのGrove端子を、Grove/Qwiic変換ケーブルでつなぎます。
5. 写真と同じ配置で、SEN66、接続基板、AtomS3 Liteをケース本体へ収めます。SEN66のコネクタは接続基板側へ、基板のコネクタ面は上へ、AtomS3 LiteのUSB端子はケースのケーブル出口へ向けます。
6. USB-CケーブルのUSB-C側をAtomS3 Liteへ接続します。適合する固定具を使う場合は、プラグの根元を支える位置に取り付けます。**反対側はまだGatewayや電源へ接続しません。** ケーブルを蓋や部品の間に挟まず、SEN66の吸気・排気口を塞がないように通します。
7. SEN66、接続基板、AtomS3 Liteの配線と配置を写真と照合します。蓋は固定せず、ネジ6本と一緒に保管しておきます。

蓋の固定は、次のページで初期設定・登録と計測値の確認を済ませてから行います。

## STL

[ケースのSTLデータ](../../hardware/enclosures/sen66-node/)から、ケース本体と蓋を使用します。ケーブル固定具は任意です。

- `sen66-node-body.stl`：本体
- `sen66-node-lid.stl`：蓋
- `sen66-node-cable-jig.stl`：ケーブル固定具（任意）

ここまででSEN66とAtomS3 Liteの配線・ケースへの収納が完了しました。

次へ：[「3-2. SEN66 Nodeをセットアップする」](esp32-node-setup.md)

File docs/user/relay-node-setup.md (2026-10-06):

# 中継専用OMK Nodeをセットアップする

[「OMK Nodeで計測範囲を拡張する」](node-and-sensors.md)で中継専用Nodeが必要と判断した方の作業手順です。AtomS3 Liteを準備し、Gatewayで設定してから設置・通信確認を行います。

## この手順の前に

- Gatewayのセットアップを済ませ、OMK APとTouch Display 2のDashboardを使える状態にします。
- 通信確認に使うBLEセンサは、[「BLEセンサを追加する」](ble-sensor-setup.md)に従って登録を済ませます。SEN66 Nodeを使って確認する場合は、そのNodeの設定・登録を済ませます。

## 1. AtomS3 Liteを準備する

| 部品 | 参考製品・実使用例 | 準備するもの |
| --- | --- | --- |
| 小型端末 | [M5Stack AtomS3 Lite](https://www.switch-science.com/products/8778) | 新品・未セットアップのもの。センサは接続しません。 |
| USB電源 | USB-A出力のACアダプター（5V、1A以上を目安） | 設置場所での常時給電用 |
| USBケーブル | データ通信・給電対応のUSB-A → USB-Cケーブル | Gatewayでの設定と設置後の給電に使用 |
| 給電用アダプタ（任意） | [Type-Cオス USB-Aオス変換アダプタ](https://www.amazon.co.jp/dp/B0CKVP8DZ8) | 設置後にUSBケーブルの代わりに使用する場合 |

使用済みNodeの接続先を変える場合は、[「OMK Nodeを更新・再設定する」](node-maintenance.md#既存nodeを再セットアップする)の手順を使ってください。

## 2. GatewayへUSB接続する

AtomS3 Liteをデータ通信対応のUSBケーブルでGatewayへ接続します。ほかのAtomS3 Liteや同種の開発ボードは、セットアップ中だけGatewayから取り外します。OnyxとRS-WSUHA-Pは接続したままで構いません。

## 3. Dashboardからセットアップする

1. Touch Display 2のDashboardで「管理メニュー → 機器管理」を開きます。
2. 「接続: USB接続」のカードに「USB接続されたNode候補」と「OMK Nodeをセットアップ」が表示されることを確認します。
3. 接続した実物を確かめ、「未セットアップのAtomS3 Liteであることを確認しました」にチェックを入れます。初回設定の再開時には、この確認欄が表示されないことがあります。
4. 「OMK Nodeをセットアップ」を押します。
5. USB接続と給電を維持し、「セットアップ完了」と表示されるまで待ちます。Logical IDの登録は行いません。

既存Nodeの再セットアップが表示された場合は、[「OMK Nodeを更新・再設定する」](node-maintenance.md)を参照してください。失敗した場合は[「トラブルシューティング」](troubleshooting.md#nodeセットアップを診断する)で表示内容を確認します。

## 4. 設置する

1. 設定したAtomS3 LiteをGatewayから取り外します。
2. 選んだ設置場所へ置き、USB電源に接続します。常時給電してください。

## 5. 通信を確認する

1. Dashboardの「機器管理」で、設置したNodeの「接続」が「オンライン」になることを確認します。「Wi-Fi設定済み」「接続センサ: 未検出」の表示で使えます。
2. 対象のBLEセンサを使う場合は、そのセンサの「最終受信」が更新されることを確認します。離れたSEN66 Nodeを使う場合は、そのNodeが「オンライン」になり、計測値が更新されることを確認します。
3. 更新が続かない場合は、設置したNodeをGatewayや対象機器に近づけ、位置を調整して再確認します。

設置後も対象の計測値や受信時刻が更新されれば、作業完了です。

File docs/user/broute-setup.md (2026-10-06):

# Bルートでスマートメーターを追加する

Gatewayセットアップで導入したBルートサービスを使い、低圧スマートメーターの計測を始めます。Touch Display 2でDashboardを操作できることを確認し、RS-WSUHA-Pと、電力会社から発行されたBルートID・パスワードを用意してください。

## 1. アダプタの設定を確認する

Gatewayセットアップ時にRS-WSUHA-Pを接続し、実物確認に`y`と答えてスクリプトが完了していれば、アダプタは設定済みです。接続を維持したまま手順2へ進みます。スクリプトの再実行は不要です。

### 後からアダプタを追加する場合

アダプタ未接続でGatewayセットアップを完了した場合や、シリアルポートの設定を済ませていない場合は、次を行います。

1. RS-WSUHA-PをGatewayのUSBへ接続します。接続済みのAtomS3 Liteは設置場所のUSB電源へ戻し、ほかのUSBシリアル機器も一時的に取り外します。Onyxは外部通信のため接続したままにします。
2. GatewayのUSBキーボードで`Ctrl+Alt+T`を押し、ターミナルを開きます。パッケージ取得のため、Gateway自身がOnyx経由でインターネットへ接続できることを確認します。
3. 次を実行します。

   ```bash
   cd ~/projects/omk
   ./scripts/setup-broute-meter.sh
   ```

4. `Use this FT230X serial adapter as RS-WSUHA-P? ... [y/N]`と表示されたら、接続した実物がRS-WSUHA-Pであることを確認して`y`を入力します。接続先を設定済みの場合、この確認は表示されません。
5. スクリプトの完了まで待ちます。RS-WSUHA-Pの抜き差しを求められた場合は、そのアダプタだけを抜き、数秒待って同じUSB端子へ接続し直します。OnyxやGatewayの電源は外しません。

スクリプトは認証情報を尋ねません。BルートID・パスワードの未登録により、サービスが起動しない場合があります。スクリプトがエラーで停止した場合は[「トラブルシューティング」](troubleshooting.md#パッケージやomkのダウンロードが失敗する)を参照してください。

## 2. BルートID・パスワードを登録する

1. Touch Display 2でDashboardの「管理メニュー → Bルート設定」を開きます。
2. 電力会社から発行された情報を「BルートID」「パスワード」に入力します。
3. 「保存して接続」を押します。
4. 画面上部の「接続状態」が「接続済み」になることを確認します。

## 3. 計測を確認する

Dashboardでは現在の電力に加え、本日の買電量・売電量も表示できます。30分周期のBルート積算値・30分値は、最後に受信してから45分以内が`normal`、45分超～90分以内が`delayed`、90分超が`unavailable`です。

Dashboardの表示設定で「おすすめ」を選び、表示画面で電力データと「最終更新」が更新されれば追加完了です。接続できない場合や値が届かない場合は[「トラブルシューティング」](troubleshooting.md#bルートのデータを取得できない)を参照してください。

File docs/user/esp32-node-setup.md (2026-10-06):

# 3-2. SEN66 Nodeをセットアップする

AtomS3 Liteは市販のハードウェアです。OMK用ファームウェアと設定を書き込むと、センサのデータをGatewayへ送る「OMK Node」になります。このページでは、前のページで組み立てたSEN66 NodeをGatewayへUSB接続し、Dashboardから設定・登録して計測を始めます。

新品・未セットアップのAtomS3 Liteを使い、以下の順に進めます。

## この手順の前に

- Gatewayのセットアップを完了し、DashboardとOMK APを使える状態にします。
- SEN66、接続基板、AtomS3 Liteの配線を済ませておきます。**ケースの蓋はまだ固定しません。**
- データ通信に対応したUSBケーブルと、設置場所でNodeへ給電するUSB電源を用意します。

## 1. GatewayへUSB接続する

SEN66を配線したAtomS3 LiteのUSBケーブルを、**GatewayのUSB端子**へ接続します。このUSB接続は、給電と初回設定の両方に使います。取り違えを防ぐため、ほかのAtomS3 Liteや同種の開発ボードは、セットアップ中だけGatewayのUSBから取り外してください。OnyxとRS-WSUHA-Pは接続したままで構いません。

## 2. Dashboardからセットアップする

1. Touch Display 2のDashboardで、右上の歯車から「管理メニュー → 機器管理」へ進みます。
2. 「接続: USB接続」と表示されたOMK Nodeのカードを見ます。新品・未セットアップでは「USB接続されたNode候補」と「OMK Nodeをセットアップ」が表示されます。既存のOMK Nodeで「OMK Nodeを再セットアップ」が表示されたら、[「トラブルシューティング」](troubleshooting.md#nodeセットアップを診断する)の使用済みNodeの項目を確認してください。
3. GatewayのUSBに接続した実物が**未セットアップのAtomS3 Lite**であることを確かめ、「未セットアップのAtomS3 Liteであることを確認しました」の行をタップしてチェックを入れます。初回設定を途中から再開する場合、この確認欄は表示されないことがあります。
4. 「OMK Nodeをセットアップ」を押します。Gatewayに用意されたファームウェアの書き込みと、OMK APへ接続するためのWi-Fi設定が自動で行われます。
5. **USB接続と給電を維持したまま、「セットアップ完了」と表示されるまで待ちます。**

「セットアップ完了」を確認したら、USBを接続したまま次のSEN66登録へ進みます。

「セットアップ失敗」と表示された場合やNodeが見つからない場合は、[「トラブルシューティング」](troubleshooting.md#nodeセットアップを診断する)を参照してください。

## 3. SEN66を確認して登録する

Logical IDは、Nodeに接続したSEN66を区別する名前で、Dashboardや計測データで使います。ファームウェアのセットアップとは別に、この登録が必要です。

1. 「機器管理」で対象Nodeの「接続センサ」が「SEN66（検出済み）」になったら、「Logical IDを登録」を押します。
2. `sen66-001`などのIDを入力します。1〜48文字の英数字、`-`、`_`を使い、複数台では異なるIDを付けてください。
3. 「登録する」を押します。
4. Nodeカードに入力したLogical IDが表示されることを確認します。
5. 管理メニューの「表示設定」で「おすすめ」を選び、「保存してダッシュボードを確認」を押します。温度・湿度・CO₂濃度などの実測値が表示されることを確認してから、次の設置へ進みます。

「対応機能」の「SEN66対応」は接続済みという意味ではありません。接続の有無は「接続センサ」で見ます。

USB接続中のWi-Fi状態は「Wi-Fi設定済み」と表示されます。「登録済み」の表示は、設置場所で給電し直した後に確認します。

## 4. 設置して正常動作を確認する

1. 計測値を確認したら、AtomS3 LiteのUSBケーブルをGatewayから取り外し、**給電を止めます。**
2. ケースの蓋を仮置きし、ケーブル（固定具を使う場合は固定具も）に当たらずに閉まることを確かめます。M3×8mmネジ6本で固定し、SEN66の吸気・排気口を塞がないようにします。
3. Gatewayと通信できる設置場所へ置き、USBケーブルを設置場所のUSB電源へ接続します。Nodeには常時給電します。
4. Dashboardの「管理メニュー → 機器管理」で、対象Nodeの「接続」が「オンライン」になることを確認します。
5. 同じカードにLogical IDと「登録済み」、「接続センサ: SEN66（検出済み）」が表示され、Dashboardの表示画面の計測値と「最終更新」が更新されることを確認します。

これでSEN66 Nodeの製作・登録・設置と、Dashboardでの計測確認が完了しました。

値が出ない、Nodeがオンラインにならない場合は[「トラブルシューティング」](troubleshooting.md#センサや機器の値が更新されない)へ進みます。

次へ：[「4-1. Dashboardの使い方」](dashboard.md)

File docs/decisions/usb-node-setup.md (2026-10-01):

# Gateway USB Node setup

正式対象はAtomS3 Liteのみ。Gatewayは追跡対象のprebuilt packageを検証し、system-manager venvの`esptool==4.11.0`で書き込む。開発環境のespressif32 7.0.1 / tool-esptoolpy 2.41100.0の`esptool.__version__`も4.11.0であることを確認済み。

## 開発者のpackage更新手順

1. firmware sourceを変更する。
2. host testsと関連testsを実行する。
3. `pio run -d firmware/esp32/omk-node -e atom-s3-lite`を実行する。
4. sourceをcommitする。
5. リポジトリ内のclean HEADから`./scripts/build-omk-node-package.sh`を実行する。
6. `firmware/esp32/omk-node/prebuilt/atom-s3-lite/`の3 binaryとmanifestを確認し、source commit・version・SHA-256を照合する。[ライセンス監査の更新手順](../../firmware/esp32/omk-node/LICENSE_AUDIT.md)に従い、同じbuildのapp/bootloader情報からレビュー済み`sbom.spdx.json`を再生成し、配布binary・manifest・SBOMのhashを照合する。`LICENSE_AUDIT.md`の来歴も更新し、依存やリンク対象に差があれば第三者通知と再配布義務を再確認する。
7. packageを別commitにする。
8. pushする。
9. Gatewayでpullする。初回導入時は`scripts/setup-system-manager.sh`を再実行してvenv依存とdialout membershipを更新する。
10. Dashboardから対象Nodeをセットアップする。

生成scriptはGit状態取得の失敗を停止条件とし、untrackedを含むdirty treeを拒否し、build前後のHEADとclean状態を確認する。既存`.pio/`成果を再利用しないようPlatformIO cleanの後にbuildする。生成対象は3 binaryとmanifestのみで、SBOM・監査記録・第三者通知は自動更新しない。`source_commit`はbuild元の40桁SHAでありpackage commitではない。runtimeでGateway HEADとの一致は要求しない。`.pio/`やNode固有credentialは追跡しない。今回同梱したpackageのsourceはmanifestを参照する。

## 固定package仕様と境界

schema_version=1、target=atom-s3-lite、chip=esp32s3。segment配列は次の順序と名前、offsetで固定する。

| filename | offset | 最大サイズ |
|---|---|---|
| bootloader.bin | 0x00000000 | 0x8000 |
| partitions.bin | 0x00008000 | 0x1000 |
| firmware.bin | 0x00010000 | 0x200000 |

manifestの形式、regular file、symlink不使用、サイズ、SHA-256、segmentの過不足をUSBアクセス前に検証する。検証したbytesをprivate temporary directoryへsnapshotし、その固定ファイルだけを渡す。merged imageや全flash eraseは使用しない。NVS 0x9000とfactory secret 0xf000は通常書込みに含めない。

## 機器分類・identity・secret

探索対象はttyACMへ解決される既存allowlistのみ。ttyUSBへ解決されるby-idも除外する。OMK identifyに応答する既存Nodeは、Gateway credentialが欠けても新品にしない。OMK node_idとeFuse base MACからFNV-1aで算出したnode_idが一致する場合のみ通常書込みを行う。

identify未確認の場合はESP32-S3 chipと一意なMACを確認する。descriptorやOUIからAtomS3 Liteとは断定せず、実物確認を必須にする。同node_idのcredentialが存在すればrecovery_requiredとして停止する。明示確認した新品のみrandom 32-byte secretを生成し、OMKP + raw secretを0xf000へ書く。credentialは0600、directoryは0700。永続化とfsync後、factory書込みを試みる。書込み前のidentity失敗ではcredentialを削除し、試行後の失敗では保持する。既存Nodeではfactory secretとNVS prov_popを変更しない。

setup開始時に公開ttyACM名をallowlist内の優先パス（存在すればby-id）へ一度だけ解決し、以後その内部パスを保持する。initial MACを基準に各write boundaryで再確認する。書込み前のMAC検査とfactory書込み後は`--after no_reset`でbootloader内に留め、途中の再起動と次のserial openとの競合を避ける。factory書込み後、firmware書込み前にも再確認する。再列挙は選択した同一パスだけを待ち、別ttyを探索して追従しない。同じby-idで戻った場合もeFuse MACを確認する。MAC確認による再起動後、USB v2 identifyのnode_id一致を確認してからWi-Fiを送る。

## API・権限・完了条件

- `GET /api/nodes/usb-candidates`: 既存Node／未確認ESP32-S3／復旧必要をkindで分類。setup中はcacheのみ。公開deviceはttyACM名とし、MACを含み得るby-id文字列をAPI/UIへ出さない。
- `POST /api/nodes/usb-setup`: device、node_id、strict booleanのconfirm_atom_s3_liteだけを受け付け202を返す。追加fieldは拒否。
- `GET /api/nodes/usb-setup/status`: stage、node_id、安全なerror codeのみ。
- `POST /api/nodes/usb-provision`: 既存Wi-Fiのみの互換APIとして維持。標準UIはsetupを使用。
- `POST /api/nodes/usb-reinitialize`: 使用済みNodeの明示的な再セットアップ。旧PoP・Wi-Fi・Logical IDを置換/解除し、通常setupと同じlock・statusを使用する。[再試行とcredentialの扱い](../../services/system-manager/README.md#usb-node-setup)を参照する。

setupはoperation lockとserial access lockを既存provisioningと共有し同時に1件。setup中のcandidate pollingはcacheのみを返しportを開かない。idle時はserial lockの下で探索する。system-managerは既存非rootユーザーで動作し、setupでdialout groupを追加する。flash用sudo/helperや任意コマンドAPIは追加しない。ブラウザからはDashboard backendを通しBearer tokenを公開しない。

Wi-Fi送信後は対象node_idの新しいMQTT registration status（provisioned/registered）を待つ。setupではmosquitto_sub -Rで過去のretained statusだけによる誤成功を防ぐ。受信は現在のGatewayへの接続確認になるが、Mesh経路の全hop検査は行わない。タイムアウトは失敗とし、Wi-Fi設定済みだけでsetup完了に置き換えない。

PC用flash-omk-node.shは既存H3 guardを維持し開発・復旧用に残す。復旧ではcredentialを削除して新品扱いにせず、factory/NVSの状態と保存済みcredentialを確認する。

## 実機確認

新品・既存（Gateway credentialあり／なし）での完走、再列挙、USB差替え停止、工場secretの維持、電断後の復旧、AP変更後の再setup、SEN66登録、SEN66なしのBLE/Mesh、fresh Gatewayのdialout権限を確認する。自動testsはfake serial/esptoolを用い実USBを書き込まない。

以下は2026-09-11時点の実装・レビュー記録であり、テスト件数とcommit SHAは現在の配布物を示さない。現行packageの来歴は`manifest.json`とライセンス監査記録を参照する。

## 実装時の検証記録（2026-09-11）

- system-manager全tests: 129 passed。
- Dashboard全tests（USB UI、Node登録、proxy含む）: 123 passed。
- scriptsのpackage／flash／USB provisioning testsとomk-node firmware host tests: 187 passed。
- `bash scripts/tests/test_setup_omk_gateway.sh`、`bash scripts/tests/test_setup_ble_sensor_manager.sh`: 成功。
- `pio run -d firmware/esp32/omk-node -e atom-s3-lite`: 成功。clean HEADからpackage生成も成功。
- `git diff --check`、変更したshell scriptsの`bash -n`、admin.jsの`node --check`: 成功。

API testsはsandbox内でTestClientが停止したため、ローカル通信可能な実行環境で再検証した。Dashboardの既存Node.jsハーネスには新しいstatus APIのidle応答を追加した。実USBは使用せず、実機flash・commit・pushは行っていない。

## 変更ファイル一覧

- [docs/decisions/usb-node-setup.md](../../docs/decisions/usb-node-setup.md)
- [docs/user/dashboard.md](../../docs/user/dashboard.md)
- [docs/user/esp32-node-setup.md](../../docs/user/esp32-node-setup.md)
- [firmware/esp32/omk-node/README.md](../../firmware/esp32/omk-node/README.md)
- [firmware/esp32/omk-node/prebuilt/atom-s3-lite/bootloader.bin](../../firmware/esp32/omk-node/prebuilt/atom-s3-lite/bootloader.bin)
- [firmware/esp32/omk-node/prebuilt/atom-s3-lite/firmware.bin](../../firmware/esp32/omk-node/prebuilt/atom-s3-lite/firmware.bin)
- [firmware/esp32/omk-node/prebuilt/atom-s3-lite/manifest.json](../../firmware/esp32/omk-node/prebuilt/atom-s3-lite/manifest.json)
- [firmware/esp32/omk-node/prebuilt/atom-s3-lite/partitions.bin](../../firmware/esp32/omk-node/prebuilt/atom-s3-lite/partitions.bin)
- [scripts/build-omk-node-package.sh](../../scripts/build-omk-node-package.sh)
- [scripts/setup-system-manager.sh](../../scripts/setup-system-manager.sh)
- [scripts/tests/test_build_omk_node_package.py](../../scripts/tests/test_build_omk_node_package.py)
- [services/dashboard/README.md](../../services/dashboard/README.md)
- [services/dashboard/app/main.py](../../services/dashboard/app/main.py)
- [services/dashboard/app/static/admin.js](../../services/dashboard/app/static/admin.js)
- [services/dashboard/app/templates/admin_sensors.html](../../services/dashboard/app/templates/admin_sensors.html)
- [services/dashboard/tests/test_display.py](../../services/dashboard/tests/test_display.py)
- [services/dashboard/tests/test_switchbot_unrecognized.py](../../services/dashboard/tests/test_switchbot_unrecognized.py)
- [services/dashboard/tests/test_usb_node_provisioning_ui.py](../../services/dashboard/tests/test_usb_node_provisioning_ui.py)
- [services/system-manager/README.md](../../services/system-manager/README.md)
- [services/system-manager/requirements.txt](../../services/system-manager/requirements.txt)
- [services/system-manager/src/omk_system_manager/main.py](../../services/system-manager/src/omk_system_manager/main.py)
- [services/system-manager/src/omk_system_manager/node_provisioning.py](../../services/system-manager/src/omk_system_manager/node_provisioning.py)
- [services/system-manager/src/omk_system_manager/node_setup.py](../../services/system-manager/src/omk_system_manager/node_setup.py)
- [services/system-manager/tests/test_api.py](../../services/system-manager/tests/test_api.py)
- [services/system-manager/tests/test_node_setup.py](../../services/system-manager/tests/test_node_setup.py)

## commit前レビュー（2026-09-11）

26ファイル、実際のesptool argv、prebuilt partition tableとSHA-256を監査した。次の不整合のみ修正し、再現テストを追加した。

- Git status失敗の空出力をcleanとして扱っていた。build前後ともGit失敗時に停止する。
- by-id文字列に含まれるMACが候補API／DOMへ出得た。公開値をttyACM名に限定し、内部ではallowlistのby-idを保持する。
- setup POST失敗時に前回の完了statusを今回の成功として表示し得た。受付不明時は完了を表示しない。
- jobのfailure codeが未翻訳だった。固定の日本語説明に変換し、未知の文字列は表示しない。

unsupported chip／ambiguous MAC、hash不一致のwrite 0回、absolute path／missing binary／duplicate segment拒否、by-idの内部保持、固定subprocess argv、dialout追加順のテストも補完した。testのfactory secret比較は失敗出力にbytesを含めない形にした。

検証: system-manager 138 passed、Dashboard 125 passed、関連scripts／firmware host tests 189 passed。Gateway／BLE setup script tests、AtomS3 Lite PlatformIO build、bash -n、JS構文確認、git diff --checkも成功。prebuilt packageは変更せず、source_commitは2e961df52583260fbd1a69493bbdf2412169cdc1のまま。実機flash・commit・pushは行っていない。

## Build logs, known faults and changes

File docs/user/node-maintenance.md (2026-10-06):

# OMK Nodeを更新・再設定する

導入済みのOMK NodeのLogical ID変更、接続先の再設定、ファームウェア更新を行うときのページです。初回のSEN66 Node導入は[「3-2. SEN66 Nodeをセットアップする」](esp32-node-setup.md)を参照してください。

## 登録済みのLogical IDを変更・解除する

「管理メニュー → 機器管理」のNodeカードで「Logical IDを変更」を押し、新しいIDを入力して「変更内容を登録」を押します。

「Logical ID登録を解除」を押すと、SEN66の登録を解除します。Wi-Fi設定や過去の計測データは残ります。再登録する場合は[「3-2. SEN66 Nodeをセットアップする」](esp32-node-setup.md#3-sen66を確認して登録する)の登録手順を参照してください。

## 既存Nodeを再セットアップする

別のGatewayへ移す場合や、microSD交換後に使い直す場合、接続先のOMK APを設定し直す場合は、この手順を使います。接続先のGatewayでは、[「2-3. Gatewayセットアップ」](gateway-setup.md)を完了しておきます。

Logical IDを登録済みのNodeが以前と同じWi-Fiへ接続できる場合は、再接続時にLogical IDが自動で復元されます。「機器管理」で「オンライン」と以前のLogical IDが表示され、計測値も届いていれば、再セットアップは不要です。

再セットアップすると、Node IDは変わりませんが、**Wi-Fiは接続先Gateway用に設定し直され、以前のLogical IDは解除されます。** SEN66を使う場合は、完了後に登録し直してください。

1. 対象のAtomS3 LiteだけをGatewayへUSB接続します。ほかの同種USB機器は一時的に取り外します。OnyxとRS-WSUHA-Pは接続したままで構いません。
2. Dashboardの「管理メニュー → 機器管理」で、「接続: USB接続」のNodeカードにある「OMK Nodeを再セットアップ」を押します。
3. 確認画面で、Wi-Fiが再設定されLogical IDが消去されることを読み、実行します。
4. USB接続と給電を維持し、「セットアップ完了」と表示されるまで待ちます。
5. SEN66を使う場合は[「3-2. SEN66 Nodeをセットアップする」](esp32-node-setup.md#3-sen66を確認して登録する)の登録手順でLogical IDを登録し、[「3-2. SEN66 Nodeをセットアップする」](esp32-node-setup.md#4-設置して正常動作を確認する)の手順で設置と計測を確認します。組み立て済みケースの蓋は外す必要はありません。センサを接続せず中継だけに使う場合は[「中継専用OMK Nodeをセットアップする」](relay-node-setup.md#4-設置する)の設置・通信確認を行います。

「OMK Nodeの再セットアップを再試行」が表示された場合は、そのボタンから再開します。完了しない場合は[「トラブルシューティング」](troubleshooting.md#nodeセットアップを診断する)を参照してください。

## ファームウェアを更新する

現在、Dashboardには設定を保持したまま更新する専用ボタンはありません。「OMK Nodeを再セットアップ」では、上記のとおりWi-Fiの再設定とLogical IDの解除が行われます。

Wi-FiやLogical IDを保持する通常更新には、開発・保守用の実行環境が必要です。更新手順は[「OMK ESP32 Node」](../../firmware/esp32/omk-node/README.md#factory-flashとpartition-table)を参照してください。

更新後は[「3-2. SEN66 Nodeをセットアップする」](esp32-node-setup.md#4-設置して正常動作を確認する)の設置確認に沿って、Nodeが「オンライン」に戻り、同じLogical IDで計測値が表示されることを確認します。接続先を変える再設定は、このページの再セットアップ手順を使います。

配布済みファームウェアに含まれる第三者ソフトウェアの許諾は[「OMK Node firmware — Third-party notices」](../../firmware/esp32/omk-node/prebuilt/atom-s3-lite/THIRD_PARTY_NOTICES.md)を参照してください。バイナリを再配布する場合は同文書を同梱してください。

## 保守完了の確認

対象Nodeが「オンライン」に戻り、SEN66のLogical IDと計測値、または中継するセンサの受信が更新されることを確認します。

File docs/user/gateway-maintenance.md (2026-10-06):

# Gatewayソフトウェアを更新・保守する

構築済みGatewayの更新、機能追加、再設定、状態確認を説明します。初めて構築する場合は[「2-3. Gatewayセットアップ」](gateway-setup.md)、問題が起きた場合は[「トラブルシューティング」](troubleshooting.md)を参照してください。

## GatewayのOMKソフトウェアを更新する

更新にはGateway自身のインターネット接続が必要です。標準構成ではSORACOM Onyxを使います。Onyxを使わない場合は、有線LANなどの接続を用意してください。OMK APは機器とGatewayをつなぐローカルネットワークで、AP側端末の外部通信は転送しません。

更新中はDashboardや計測が一時的に停止します。セットアップには既存データや認証情報を保持する処理がありますが、サービスの再起動、設定ファイル・権限の更新、旧設定の移行も行います。実行前に[「4-1. Dashboardの使い方」](dashboard.md#データを書き出す)に従って重要な計測データをUSBへ書き出し、独自設定がある場合は控えを残してください。

### 1. Gatewayへ接続する

Gatewayへの接続・操作方法は、本ページの[構築後のGatewayへ接続する](#構築後のgatewayへ接続する)を参照してください。

以下のコマンドはGateway上で実行してください。

```bash
cd ~/projects/omk
git status --short
```

何も表示されなければ、次へ進みます。ファイル名が表示された場合は、手元の変更や追加ファイルがあるため、ここで更新を止めてください。この手順では、変更のない状態からの更新を扱います。

### 2. GitHubからOMKソースコードの最新版を取得する

`git pull`は、GitHub上の更新を取得して、Gateway内のOMKソースコードを更新するコマンドです。稼働中のサービスへの反映は、次のセットアップ再実行で行います。

```bash
git pull --ff-only
```

取得が完了したら次へ進みます。`Already up to date.`と表示された場合は、すでに最新版です。

### 3. セットアップを再実行する

標準構成では次を順に実行します。**通常の更新では`--with-base`を付けず、BLEは個別スクリプトで更新します。** 各コマンドが完了したことを確認してから次を実行してください。

```bash
./scripts/setup-omk-gateway.sh --with-soracom
```

APの確認メッセージには[「2-3. Gatewayセットアップ」](gateway-setup.md#6-omk-apへの切り替え)に沿って答えます。最終AP切り替え処理はSSH切断後も進みますが、前段のパッケージ導入等に同じ保証はありません。切断された場合は[接続し直して](#構築後のgatewayへ接続する)、次を実行します。

```bash
cd ~/projects/omk
./scripts/setup-ble-sensor-manager.sh
```

続いて、Bルートサービスを更新します。利用中のRS-WSUHA-Pは接続したまま、AtomS3 LiteなどほかのUSBシリアル機器は作業中だけ外します。Onyxは外部通信のため接続したままにします。Bルート未使用ならアダプタ未接続のままで実行できます。

```bash
./scripts/setup-broute-meter.sh
```

Bルート計測は再実行中に停止する場合があります。FT230Xの実物確認が出たらRS-WSUHA-Pの接続を確認して答えます。

Onyxなしや表示端末を変更した構成では、[「標準構成以外・高度な構成」](advanced-configuration.md)に従って最初のコマンドを調整します。失敗時は[「トラブルシューティング」](troubleshooting.md#パッケージやomkのダウンロードが失敗する)へ進みます。

### 4. 更新後の動作を確認する

セットアップが完了したら、[状態を確認する](#状態を確認する)の表に沿って、Dashboardと使用中の機器の表示を見ます。

Gatewayを更新しても、設置済みOMK Nodeのファームウェアは自動更新されません。Nodeの更新は[「OMK Nodeを更新・再設定する」](node-maintenance.md#ファームウェアを更新する)を参照してください。

## セットアップを再実行する

Gateway全体の設定をやり直す場合は、Gatewayのターミナルで`cd ~/projects/omk`を実行し、上の[手順3](#3-セットアップを再実行する)へ進みます。特定の機能だけを再設定する場合は、次の節にある専用コマンドを使います。

## 個別サービスを再設定する

標準Gatewayでは以下のサービスは導入済みです。計測機器の追加は[「BLEセンサを追加する」](ble-sensor-setup.md)または[「Bルートでスマートメーターを追加する」](broute-setup.md)を参照してください。以下は旧構成への導入や個別の再設定用で、Gateway自身のインターネット接続が必要です。

### BLEセンサ・OMK Nodeを使う

BLE Sensor Managerを導入します。

```bash
cd ~/projects/omk
./scripts/setup-ble-sensor-manager.sh
```

完了したら、[「BLEセンサを追加する」](ble-sensor-setup.md#bleセンサを探索して登録する)か、[「3-2. SEN66 Nodeをセットアップする」](esp32-node-setup.md)の登録手順を参照してください。センサの接続・設置は[「OMK Nodeで計測範囲を拡張する」](node-and-sensors.md)、SEN66の組み立ては[「3-1. SEN66 Nodeの組み立て」](sen66-node-assembly.md)を参照してください。

### Bルートを使う

RS-WSUHA-PをGatewayへ接続します。AtomS3 LiteなどほかのUSBシリアル機器は、セットアップ中だけ取り外してください。Onyxは外部通信のため接続したままにします。

```bash
cd ~/projects/omk
./scripts/setup-broute-meter.sh
```

`Use this FT230X serial adapter as RS-WSUHA-P? ... [y/N]`と表示されたら、接続した実物がRS-WSUHA-Pであることを確かめて`y`を入力します。完了したら、[「Bルートでスマートメーターを追加する」](broute-setup.md#2-bルートidパスワードを登録する)でBルートIDとパスワードを入力します。

### SORACOM Onyxを追加・再設定する

初めてOnyxを追加する場合は、設定中のインターネット接続としてGatewayを有線LANなどへ接続します。SIMは利用開始済みのSORACOM Air SIMを使います。

SIMを装着する場合は、OnyxをUSBから外し、本体の表示に合わせてSIMの金属端子の向きを確かめて挿入します。その後、GatewayへUSB接続してください。接続済みのOnyxを再設定する場合は、そのまま次のコマンドを実行できます。ほかのUSBモデムは、セットアップ中だけ取り外します。

通常のSORACOM Air SIMでは、次のコマンドでAPNに`soracom.io`が使われます。plan-DUのSIMを使う場合だけ、末尾に`--apn du.soracom.io`を付けます。

```bash
cd ~/projects/omk
./scripts/setup-soracom-onyx.sh
```

既存のOnyxを再設定する場合も同じコマンドを使います。すでに接続中の場合は、その接続を保持します。APNを変更する目的の再設定では、その指定だけで既存接続が切り替わるとは限らないため、接続結果を確認してください。

完了したら、SORACOMユーザーコンソールで対象SIMのセッション状態が「オンライン」になっていることを見ます。接続できない場合は[「トラブルシューティング」](troubleshooting.md#onyxで外部通信できない)を参照してください。

## 状態を確認する

GatewayのTouch Display 2でDashboardを操作します。別の表示端末を使う場合は[「標準構成以外・高度な構成」](advanced-configuration.md#pcやタブレット等からdashboardを使う場合)を参照してください。

| 対象 | 確認する場所と表示 |
| --- | --- |
| OMK AP | PCのWi-Fi一覧に、設定済みのSSIDが表示される。SSIDはDashboardの「OMKアクセスポイント参照」で見られる。 |
| Dashboard | 表示画面が開く |
| 登録済みBLEセンサ | 「機器管理」の「登録済みセンサ」で、対象の「最終受信」が更新され、状態が「正常」になる |
| OMK Node | 「機器管理」で、無線接続しているNodeの「接続」が「オンライン」になる。SEN66を使う場合は、表示画面に計測値が表示される。 |
| Bルート | 「Bルート設定」の「接続状態」が「接続済み」になる |

機器の行は、使用しているものだけ確認します。表示が戻らない場合は、[「トラブルシューティング」](troubleshooting.md)の該当する症状へ進んでください。サービスやログによる詳細な診断は、[「開発ガイド」](../developer/development.md#gatewayでの確認)を参照してください。

## 再起動・シャットダウンする

Dashboardの管理メニューから「システム操作」を開き、「再起動」または「シャットダウン」を選んで、確認画面の「実行」を押します。この間は計測も停止します。

電源を外す場合は、シャットダウンが完了してから外してください。シャットダウン後は、電源を入れ直すまで利用できません。画面操作は[「4-1. Dashboardの使い方」](dashboard.md#gatewayを再起動シャットダウンする)も参照してください。

## 構築後のGatewayへ接続する

Gatewayでは、USBキーボードを接続して`Ctrl+Alt+T`でターミナルを開きます。PCから操作するときは次の方法があります。

- **近くのPC**：Touch Display 2の「OMKアクセスポイント参照」で接続情報を表示し、PCをOMK APへ接続します。PowerShellで`ssh omkdev@192.168.50.1`を実行します。Gatewayの外部通信はOnyxを使います。
- **SORACOM Napterで遠隔接続**：PCをインターネットへ接続し、SORACOMユーザーコンソールで対象SIMが「オンライン」であることを確認します。Napterのオンデマンドリモートアクセスを開始し、[SORACOM公式のSSH接続手順](https://users.soracom.io/ja-jp/docs/napter/login-with-ssh/)の「PCのターミナルを使ってSSH接続する」に従います。接続先・ポートはNapterの表示値、ユーザー名は`omkdev`、パスワードはImagerで設定したものです。

## 保守完了の確認

更新・再設定が終わり、Dashboardと利用中の機器の値が更新されることを確認できたら保守完了です。

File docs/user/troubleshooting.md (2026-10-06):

# トラブルシューティング

推奨構成（Raspberry Pi 4、Touch Display 2、SORACOM Onyx）での対処を症状別に示します。解決したら、各項目のリンク先へ戻ってください。

## SSH接続できない

### Windowsからホスト名で接続できない

初期セットアップ中は、WindowsのWi-Fi接続先をImagerでGatewayに設定したSSIDに合わせます。OMK APへの切り替え後は、[「2-3. Gatewayセットアップ」](gateway-setup.md#ap切替後の操作方法)を使います。

`<ホスト名>.local`で接続できない場合は、IPアドレスを指定します。Touch Display 2とUSBキーボードでGatewayのターミナルを開き、次を実行してください。

```bash
hostname -I
```

複数のアドレスが表示される場合は、次のコマンドで既存Wi-FiのIPアドレスを調べます。`inet`の後に表示されるアドレスを使い、末尾の`/24`などは含めません。

```bash
ip -4 addr show wlan0
```

Windows PowerShellで、`<IPアドレス>`を調べた値に置き換えて接続します。

```powershell
ssh omkdev@<IPアドレス>
```

IPアドレスが表示されない場合は、Gatewayのデスクトップのネットワークメニューから既存Wi-Fiを選び、Wi-Fiのパスワードを入力して接続します。その後、もう一度IPアドレスを調べてください。

接続できたら[「2-3. Gatewayセットアップ」](gateway-setup.md#3-githubからomkのソースコードを取得する)へ戻ります。Touch Display 2とUSBキーボードがあれば、そのままGatewayのターミナルで手順を続けることもできます。

### OSを書き直した後にホスト鍵の警告が出る

`REMOTE HOST IDENTIFICATION HAS CHANGED!`と表示された場合の対処です。**自分で同じGatewayのOSを書き直した場合に限り**、Windows PowerShellで古い接続先の記録を削除します。`<接続先>`には、警告が出たSSHコマンドで指定したホスト名またはIPアドレスを入れてください。

```powershell
ssh-keygen -R <接続先>
```

[「2-3. Gatewayセットアップ」](gateway-setup.md#2-gatewayへssh接続する)に戻り、接続し直します。OSを書き直していない場合や接続先が同じGatewayか分からない場合は、記録を削除せず、接続先のIPアドレスを上の手順で調べ直してください。

## sudoのパスワード入力が分からない

セットアップ中にパスワードを求められたら、Imagerで設定した`omkdev`のパスワードを入力し、Enterを押します。入力中に文字や`*`が表示されないのは正常です。そのまま実行中の手順を続けてください。

## Gatewayセットアップが途中で停止した

次のメッセージは、再起動または再ログインを待つ正常な停止です。

```text
A reboot is required. Reboot, reconnect, then rerun this command without --with-base to resume.
```

この場合はGatewayを再起動して接続し直します。

```text
Docker group membership needs a new login session. Re-login, then rerun this command without --with-base to resume.
```

この場合はSSHを切断して接続し直します。直接操作している場合はデスクトップからログアウトし、ログインし直します。

操作と再開コマンドは[「2-3. Gatewayセットアップ」](gateway-setup.md#5-基本設定後にセットアップを再開する)に従ってください。**基本設定が`Setup result: SUCCESS`で完了した後の再開では、`--with-base`を外します。** `FAILURE`の場合は、再起動が必要という表示だけで完了と判断せず、次の再開手順へ進みます。

## パッケージやOMKのダウンロードが失敗する

テザリングやWi-Fiの切断、apt・pip・Dockerの取得失敗は、**接続を復旧し、先行処理が終わったことを確認してから、失敗したセットアップ手順を再実行**します。続きの工程へ飛ばしたり、同じセットアップを同時に複数起動したりしないでください。

### 1. Gateway自身のネットワークを復旧する

- **OMK APへの切り替え前**：Gatewayのデスクトップで既存Wi-Fiへ接続し直します。テザリングなら接続元の通信と自動停止設定も確認します。別のWi-Fiへ移す場合は、PCも同じWi-Fiへ接続してSSH接続し直します。
- **OMK APへの切り替え後**：[Onyxの通信を復旧](#onyxで外部通信できない)します。OMK APはそのまま維持します。Onyxなしの構成ではGatewayに有線LANなどのインターネット接続を用意します。

### 2. 前のパッケージ処理の終了を確認する

切断前の処理やOSの自動更新がまだ動いている場合があります。Gatewayのターミナルで次を実行し、前のパッケージ処理が残っていないか確認します。

```bash
pgrep -a -x 'apt|apt-get|dpkg|unattended-upgr'
```

インストール・更新が進行中なら終了を待ちます。OSの更新画面も確認し、元のセットアップ・pip・Dockerビルドもまだ動いていないことを元の画面や`ps -ef`で確認します。状態が判断できなければ、末尾の[技術的な診断](#技術的な診断が必要な場合)へ進みます。スクリプト側もaptのロック競合では最大約5分待ちますが、通常のダウンロードエラーには同じ待機は行いません。

**lockファイルの手動削除や、apt/dpkgの強制終了はしないでください。** 再起動は先行処理が終わってから行います。

`dpkg was interrupted`など、未完了のパッケージ設定が報告された場合は、先行処理終了後に`sudo dpkg --audit`で状態を確認します。`sudo dpkg --configure -a`を実行するよう明示された場合は、その修復を行い、完了を確認してからセットアップを再試行します。依存関係エラーが残る場合は、同じセットアップの繰り返しで解決すると考えず[技術的な診断](#技術的な診断が必要な場合)へ進んでください。

### 3. 失敗した手順を再実行する

リポジトリ取得済みなら、Gatewayで`cd ~/projects/omk`を実行してから、次の表で停止位置を確認します。

| 停止位置 | 再開方法 |
| --- | --- |
| `git clone`中 | 取得先が作られていなければ同じcloneを再実行します。`omk`が存在する場合は中身と取得結果を確認し、完成済みならそのまま使います。不完全なフォルダーを上書き・削除してやり直さず、内容を確認して別名で退避してから取得し直します。 |
| base setup中で`Setup result: FAILURE` | `logs/setup/setup-*.log`の今回のログとエラーを確認します。ネットワーク・パッケージ状態を直した後、初回の`./scripts/setup-omk-gateway.sh --with-base --with-soracom`を再実行します。失敗時にも再起動要否は出るので、それだけではbase完了ではありません。 |
| baseは`SUCCESS`で、その後に停止 | 必要な再起動・再ログインを済ませ、`./scripts/setup-omk-gateway.sh --with-soracom`で再開します。**`--with-base`は付けません。** |
| BLEのapt/pip取得など | `./scripts/setup-ble-sensor-manager.sh`を再実行します。 |
| Bルートのapt/pip取得など | 接続条件を中断した手順に合わせ、`./scripts/setup-broute-meter.sh`を再実行します。Gatewayセットアップ時にRS-WSUHA-Pを接続していた場合は接続を維持します。未使用・未入手なら未接続のまま再実行できます。後から計測を始める場合はアダプタを接続します。 |
| 再起動・再ログイン待ち | [「2-3. Gatewayセットアップ」](gateway-setup.md#5-基本設定後にセットアップを再開する)に従い、新しいログインで再開します。 |

再実行は、処理の一部分から自動的に続けるものではなく、指定したスクリプトをもう一度実行します。既存設定の保持や不完全なPython仮想環境の再作成に対応していますが、パッケージ再取得、設定更新、サービス再起動も行います。あらゆる途中状態からの復旧や、稼働中の計測を止めずに実行できることは保証していません。

base setupは再実行のたびにOSの`full-upgrade`を行います。完了済みのbaseを、後続の失敗を理由に繰り返さないでください。同じエラーが続く場合は、表示と失敗した工程を控えて[技術的な診断](#技術的な診断が必要な場合)へ進みます。

成功を確認したら、[「2-3. Gatewayセットアップ」](gateway-setup.md)または[「Gatewayソフトウェアを更新・保守する」](gateway-maintenance.md)の中断した箇所へ戻り、次の工程へ進みます。

## OMK AP・Dashboardを利用できない

### OMK APへの切り替えでSSHが切れた

最終AP切り替え時に既存Wi-Fi経由のSSHが切れるのは正常です。独立して起動したAP切り替え処理は切断後も進みます。SSIDが見えることを確認したら、[「2-3. Gatewayセットアップ」](gateway-setup.md#ap切替後の操作方法)に従い、GatewayのUSBキーボードでBLE・Bルートの設定を続けます。

### OMK APがWi-Fi一覧に見えない

1. Gatewayの電源ケーブルを接続し、起動を待ちます。PCやスマートフォンをGatewayの近くへ移動し、Wi-Fi一覧を開き直してください。
2. Touch Display 2でDashboardが開ける場合は、「管理メニュー → OMKアクセスポイント参照」に表示されるSSIDを探します。
3. 初回セットアップでAP切り替えの確認がまだ表示されている場合は、[「2-3. Gatewayセットアップ」](gateway-setup.md#6-omk-apへの切り替え)を完了します。設定済みなら、Dashboardの「管理メニュー → システム操作 → 再起動」を実行し、起動後にWi-Fi一覧を開き直します。

SSIDが見つかったら、次の接続手順へ進みます。

### OMK APへ接続できない・パスワードが分からない

Touch Display 2で「管理メニュー → OMKアクセスポイント参照」を開き、「表示」を押します。PCやスマートフォンで、画面と同じSSIDを選び、表示されたWi-Fiパスワードを入力してください。これは`omkdev`のログインパスワードとは別です。

接続できたら、下のDashboardのURLを開きます。**Wi-FiパスワードやQRコードを第三者へ不用意に共有しないでください。**

### PCからDashboardを開けない

WindowsのWi-Fi接続先が、Gatewayの`OMK-XXXXXX`形式のSSIDになっているかを見ます。異なるWi-Fiに接続していたらOMK APへ切り替え、ブラウザのアドレス欄へ次を入力します。

```text
http://192.168.50.1:8000/
```

`https://`では開けません。Windowsの「インターネットなし」は正常です。別端末の接続手順は[「標準構成以外・高度な構成」](advanced-configuration.md#pcやタブレット等からdashboardを使う場合)を参照してください。

### Touch Display 2にDashboardが表示されない

起動後に少し待っても表示されない場合は、GatewayのターミナルまたはSSH接続先で次を実行し、再起動します。

```bash
sudo reboot
```

表示されたら[「2-3. Gatewayセットアップ」](gateway-setup.md#9-セットアップ完了を確認する)へ戻ります。表示されない場合は、末尾の[技術的な診断](#技術的な診断が必要な場合)へ進んでください。

### Dashboardにセンサが表示されない

「管理メニュー → 機器管理」を開きます。

- BLEセンサが「登録済みセンサ」にない場合は、[「BLEセンサを追加する」](ble-sensor-setup.md#bleセンサを探索して登録する)へ進みます。登録済みでも無効になっている場合は、「編集」で有効にします。
- SEN66を接続したNodeに「Logical IDを登録」が表示されている場合は、[「3-2. SEN66 Nodeをセットアップする」](esp32-node-setup.md#3-sen66を確認して登録する)を完了します。
- 機器管理に計測値が表示されるのに表示画面に出ない場合は、「管理メニュー → 表示設定」で「おすすめ」を選ぶか、「カスタム」の表示項目に追加します。

登録前のセンサは表示されません。登録と表示設定ができたら、[「4-1. Dashboardの使い方」](dashboard.md#表示画面)へ戻ります。

## センサや機器の値が更新されない

「管理メニュー → 機器管理」で対象機器の表示に合わせて対処します。

| 症状 | 対処と復帰の目安 |
| --- | --- |
| OMK Nodeがオンラインにならない | NodeのUSB電源とケーブルを接続し直し、Gatewayの近くで給電します。「オンライン」に戻ったら、[「3-2. SEN66 Nodeをセットアップする」](esp32-node-setup.md#4-設置して正常動作を確認する)へ戻ります。 |
| SEN66が「未検出」のまま | Nodeの電源を外し、[「3-1. SEN66 Nodeの組み立て」](sen66-node-assembly.md)の配線写真に合わせて接続し直します。給電後に「SEN66（検出済み）」となったら登録へ進みます。 |
| BLEセンサが探索候補に出ない | 機種を[「1-2. 対応センサ・機器と取得データ」](supported-devices.md#switchbot対応機器)と照合します。電源・電池を入れ直し、Gatewayの近くへ置いて「センサを追加」で再検索します。CO₂センサはしばらく待って再検索してください。 |
| 登録済みBLEセンサの「最終受信」が更新されない | 電源・電池を入れ直し、Gatewayの近くへ移動します。「最終受信」が更新される場所へ設置してください。 |

検出できたセンサは[「4-1. Dashboardの使い方」](dashboard.md#管理メニュー)で登録します。登録済みの場合は表示画面へ戻り、計測値の更新を見ます。

## Nodeセットアップを診断する

Dashboardのセットアップ画面に表示される症状から進んでください。**セットアップ中はUSB接続と給電を維持します。**

| 症状・表示 | 対処 |
| --- | --- |
| USB接続したAtomS3 Liteが候補に出ない・「USB機器確認」で失敗する | 処理開始前か「セットアップ失敗」の表示後に、対象のAtomS3 Liteを1台だけGatewayへ直接接続します。データ通信対応のUSBケーブルへ交換し、機器管理を開き直します。 |
| 「firmware package確認」で失敗する | [「Gatewayソフトウェアを更新・保守する」](gateway-maintenance.md#gatewayのomkソフトウェアを更新する)を実行してから、Nodeのセットアップをやり直します。 |
| 「Wi-Fi設定」や「OMK接続確認」で失敗する | NodeをGatewayの近くへ置き、PCのWi-Fi一覧にOMK APのSSIDが表示されるかを見ます。表示されなければ[APが見えない場合](#omk-apがwi-fi一覧に見えない)へ進みます。 |
| 使用済みNodeのセットアップが止まり、再セットアップを案内される | [「OMK Nodeを更新・再設定する」](node-maintenance.md#既存nodeを再セットアップする)へ進みます。 |

「OMK接続確認」（`waiting_for_registration`）が長時間続いた後に`mqtt_registration_timeout`となる場合、このガイドでは原因や確実な復旧手順を確定していません。表示内容と発生した工程を記録し、末尾の[技術的な診断](#技術的な診断が必要な場合)を参照してください。Gatewayセットアップの再実行やNode交換で直るとは案内しません。

上記の基本確認で解決した場合は[「3-2. SEN66 Nodeをセットアップする」](esp32-node-setup.md#2-dashboardからセットアップする)へ戻ります。書込み中の失敗や、上記で解決しない場合は、末尾の[技術的な診断](#技術的な診断が必要な場合)へ進んでください。通常の更新は[「OMK Nodeを更新・再設定する」](node-maintenance.md#ファームウェアを更新する)を使います。

## Bルートのデータを取得できない

Gatewayセットアップ中でBルートID・パスワードをまだ入力していない場合、サービスが起動しないことは正常です。計測を始めるときに、[「Bルートでスマートメーターを追加する」](broute-setup.md)に従って認証情報を登録してください。以下は、計測開始後の確認項目です。

「管理メニュー → Bルート設定」を開き、表示に合わせて対処します。

| 表示・症状 | 対処 |
| --- | --- |
| アダプターが接続されていない | RS-WSUHA-PをGatewayへ接続します。初回設定が未完了なら、[「Bルートでスマートメーターを追加する」](broute-setup.md)を実行します。 |
| ID・パスワードが「未設定」、または「認証エラー」 | 電力会社から発行されたBルートIDとパスワードを入力し直し、「保存して接続」を押します。 |
| 「スマートメータ未検出」・「再試行待ち」 | BルートID・パスワードを発行時の情報と照合し、Gatewayをスマートメーターに近い場所へ移動します。「今すぐ再試行」が表示されていれば押します。 |
| アダプターが応答しない | RS-WSUHA-Pだけを抜き、数秒待って同じUSBポートへ接続し直します。 |
| 接続してもアダプター未接続の表示が続く・「サービス停止」 | [「Gatewayソフトウェアを更新・保守する」](gateway-maintenance.md#bルートを使う)を実行します。 |

「接続済み」になったら、[「4-1. Dashboardの使い方」](dashboard.md#表示画面)で電力データを確認します。

## SORACOM Onyx / Napterを利用できない

### Onyxで外部通信できない

1. OnyxをGatewayのUSBポートへ接続し直します。
2. SORACOMユーザーコンソールのSIM管理で、使用中のSIMが利用開始済みで、休止・利用中断になっていないかを見ます。未開始・休止中なら利用を開始・再開します。
3. SIMを挿し直す場合は、OnyxをGatewayから外し、本体の表示に合わせてSIMを挿入してから接続します。
4. 接続が戻らない場合は、[「Gatewayソフトウェアを更新・保守する」](gateway-maintenance.md#soracom-onyxを追加再設定する)のセットアップを実行します。plan-DUのSIMでは、同じ節にあるAPN指定を付けてください。

SIM管理の「オンライン」は回線の接続状態です。セットアップで外部DNS/HTTPSの確認に`WARNING`が出ていた場合は、インターネットへの疎通も確認してからダウンロードを再試行します。Gatewayの初回構築中は[停止位置に応じた再開手順](#3-失敗した手順を再実行する)で続けてください。

SIMやOnyxの識別番号（ICCID・IMSI・IMEI）は、公開するログ・画面写真やGitHubのIssueへ載せないでください。

### NapterでSSH接続できない

1. PCをインターネットに接続できるWi-Fiなどへ接続します。OMK APはPCへインターネット接続を提供しません。
2. SORACOMユーザーコンソールで対象SIMが「オンライン」かを見ます。オフラインなら、上のOnyxの対処を行います。
3. Napterの接続情報が期限切れなら、オンデマンドリモートアクセスを作成し直します。PCからのSSHには現在表示されている接続先とポートを使い、ユーザー名を`omkdev`にします。パスワードはImagerで設定したものです。

具体的な画面操作は[SORACOM公式のSSH接続手順](https://users.soracom.io/ja-jp/docs/napter/login-with-ssh/)を参照してください。接続できたら、中断していたGateway上の作業へ戻ります。

## USBメモリへデータを書き出せない

「管理メニュー → データ書き出し」を開き、画面の表示に合わせて対処します。

### USBメモリを認識しない・書き出しボタンを押せない

| 表示・症状 | 対処 |
| --- | --- |
| 「USBメモリが見つかりません」 | USBメモリをGatewayへ挿し直します。認識しなければ別のUSBメモリを使います。 |
| 「USBメモリを1つだけ接続してください」 | 書き出し中でないことを確かめ、対象以外のUSBメモリを取り外します。 |
| 「FAT32 または exFAT のUSBメモリを接続してください」 | FAT32またはexFATのUSBメモリに交換します。 |
| 「USBメモリを確認できません」と表示される | 別のUSBメモリに交換します。 |
| USBは「利用可能」だがボタンを押せない | 書き出すデータを1項目以上選びます。 |

ボタンを押せるようになったら、[「4-1. Dashboardの使い方」](dashboard.md#データを書き出す)へ戻ります。

### 書き出しが失敗する・必要なデータが含まれない

- 「書き出しに失敗しました」と表示されたら、対象期間を短くし、データの種類を減らして再試行します。長期間・大容量の場合はexFATのUSBメモリを使います。
- 空き容量を調べる場合は、下の手順で安全に取り外してからWindows PCへ接続し、エクスプローラーの「PC」でUSBメモリの空き容量を見ます。不足していれば、空き容量の多い別のUSBメモリを使ってください。
- 必要なデータがない場合は、計測した日付が開始日・終了日の範囲に入っているか、対象データにチェックが入っているかを見ます。直近の計測分は書き出せる状態になるまで時間がかかるため、時間を置いて再度書き出します。

### 「USBメモリを安全に取り外せません」と表示される

**この表示が出ている間はUSBメモリを抜かないでください。** 次の方法で取り外します。

1. USBメモリを接続したまま、「管理メニュー → システム操作 → シャットダウン」を選んで実行します。Gatewayの計測も停止します。
2. Gatewayのシャットダウン完了を待ってから、USBメモリを取り外します。
3. Gatewayの電源を入れ直し、[「4-1. Dashboardの使い方」](dashboard.md#データを書き出す)で再度書き出します。

ほかの書き出しエラーの後にUSBを交換する場合も、「USBメモリを取り外せます」が表示されていなければ、この方法で停止してから取り外します。シャットダウンを実行できない場合は、USBを接続したまま[技術的な診断](#技術的な診断が必要な場合)へ進んでください。

## microSD交換後にGatewayを再構築する

新しいmicroSDで[「2-3. Gatewayセットアップ」](gateway-setup.md)を完了します。既存Nodeは[「OMK Nodeを更新・再設定する」](node-maintenance.md#既存nodeを再セットアップする)に従い、再接続または再セットアップします。BLEセンサは[「BLEセンサを追加する」](ble-sensor-setup.md#bleセンサを探索して登録する)に従って登録し直します。完了後はDashboardの表示画面に計測値が表示されることを確認します。

## 技術的な診断が必要な場合

このページの対処で解決しない場合の、開発・保守向けの参照先です。

| 対象 | 診断・実装の文書 |
| --- | --- |
| Gateway・Dashboard | [「開発ガイド」](../developer/development.md#gatewayでの確認)、[「OMK Dashboard」](../../services/dashboard/README.md) |
| OMK Node | [「OMK ESP32 Node」](../../firmware/esp32/omk-node/README.md#troubleshooting) |
| BLEセンサ | [「OMK BLEセンサマネージャー」](../../services/ble-sensor-manager/README.md) |
| Bルート | [「Bルート・スマートメータ」](../../services/broute-meter/README.md#実機通信のトラブルシュート) |
| USB書き出し | [「data-exporter」](../../services/data-exporter/README.md)、[「OMK System Manager」](../../services/system-manager/README.md) |

## 復旧の確認

症状が解消したら、中断していた作業へ戻ります。再実行が成功したことと、画面・計測値が更新されることを確認してください。

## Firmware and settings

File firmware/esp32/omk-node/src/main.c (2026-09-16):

#include <string.h>
#include "esp_log.h"
#include "esp_partition.h"
#include "esp_bt.h"
#include "nvs.h"
#include "nvs_flash.h"
#include "discovery_ble.h"
#include "boot_diagnostics.h"
#include "node_state.h"
#include "mqtt_registration.h"
#include "mesh_network.h"
#include "mesh_netif.h"
#include "node_registration.h"
#include "node_identity.h"
#include "node_protocol.h"
#include "sensor_manager.h"
#include "usb_provisioning.h"
#include "wifi_station.h"
#include "gateway_credentials.h"

#ifdef OMK_DEVELOPMENT_SET_WIFI_CREDENTIALS
#include "development_wifi_config.h"
#endif

#define FACTORY_MAGIC "OMKP"
#define REINITIALIZE_MAGIC "OMKR"
#define POP_BYTES 32
static const char *TAG = "omk-node";

typedef struct __attribute__((packed)) { char magic[4]; unsigned char pop[POP_BYTES]; } factory_secret_t;

/* Idempotent: factory data remains authoritative until an NVS read-back matches.
 * Thus a power cut before erase simply retries on the next boot. */
static void import_factory_pop(void) {
    const esp_partition_t *part = esp_partition_find_first(ESP_PARTITION_TYPE_DATA, 0x40, "factory_secret");
    factory_secret_t source, verified;
    if (!part || esp_partition_read(part, 0, &source, sizeof(source)) != ESP_OK) return;
    bool reinitialize = memcmp(source.magic, REINITIALIZE_MAGIC, 4) == 0;
    if (!reinitialize && memcmp(source.magic, FACTORY_MAGIC, 4)) return;
    /* OMKR is written only after explicit destructive confirmation. Keep the
     * record until every selective reset and PoP read-back succeeds. Retrying
     * after power loss is safe, even if the new PoP was already committed. */
    if (reinitialize) {
        ESP_ERROR_CHECK(node_registration_clear());
        ESP_ERROR_CHECK(gateway_credentials_reset_for_setup());
    }
    nvs_handle_t nvs;
    ESP_ERROR_CHECK(nvs_open(NODE_NVS_NAMESPACE, NVS_READWRITE, &nvs));
    size_t length = sizeof(verified.pop);
    esp_err_t existing = nvs_get_blob(nvs, NODE_NVS_PROVISIONING_POP_KEY, verified.pop, &length);
    if (existing == ESP_OK && length == sizeof(verified.pop) && !memcmp(verified.pop, source.pop, POP_BYTES)) {
        ESP_ERROR_CHECK(esp_partition_erase_range(part, 0, part->size)); nvs_close(nvs); return;
    }
    ESP_ERROR_CHECK(nvs_set_blob(nvs, NODE_NVS_PROVISIONING_POP_KEY, source.pop, POP_BYTES));
    ESP_ERROR_CHECK(nvs_commit(nvs));
    length = sizeof(verified.pop);
    ESP_ERROR_CHECK(nvs_get_blob(nvs, NODE_NVS_PROVISIONING_POP_KEY, verified.pop, &length));
    if (length == sizeof(verified.pop) && !memcmp(verified.pop, source.pop, POP_BYTES)) ESP_ERROR_CHECK(esp_partition_erase_range(part, 0, part->size));
    nvs_close(nvs);
}

void app_main(void) {
    ESP_ERROR_CHECK(nvs_flash_init());
    boot_diagnostics_init();
#ifdef OMK_DEVELOPMENT_CLEAR_REGISTRATION
    /* This image is built only by reset-omk-node-registration.sh.  Keep the
     * operation before all normal boot work so it cannot alter Wi-Fi, PoP, or
     * factory-secret state.  The script immediately restores production FW. */
    esp_err_t reset_err = node_registration_clear_for_development();
    if (reset_err == ESP_OK) {
        ESP_LOGI(TAG, "Development registration reset verified");
    } else {
        ESP_LOGE(TAG, "Development registration reset failed: %s", esp_err_to_name(reset_err));
    }
    return;
#endif
#ifdef OMK_DEVELOPMENT_SET_WIFI_CREDENTIALS
    /* This image is built only by set-omk-node-wifi.sh. It verifies the
     * node-specific PoP before and after writing only ESP-IDF's persisted STA
     * configuration. The script immediately restores production firmware. */
    esp_err_t set_err = node_state_verify_provisioning_pop();
    if (set_err == ESP_OK) {
        set_err = wifi_station_set_saved_credentials_for_development(
            OMK_DEVELOPMENT_WIFI_SSID, OMK_DEVELOPMENT_WIFI_SSID_LENGTH,
            OMK_DEVELOPMENT_WIFI_PSK, OMK_DEVELOPMENT_WIFI_PSK_LENGTH);
    }
    if (set_err == ESP_OK) {
        set_err = node_state_verify_provisioning_pop();
    }
    if (set_err == ESP_OK) {
        ESP_LOGI(TAG, "Development Wi-Fi credential write verified");
    } else {
        ESP_LOGE(TAG, "Development Wi-Fi credential write failed: %s",
                 esp_err_to_name(set_err));
    }
    return;
#endif
    import_factory_pop();
    ESP_LOGI(TAG, "Factory provisioning state initialized");

    ESP_LOGI(TAG, "Normal boot begin");
    uint64_t node_id;
    ESP_ERROR_CHECK(node_identity_get_id(&node_id));
    bool has_wifi_credentials = false;
    esp_err_t wifi_err = wifi_station_init_network_core();
    if (wifi_err == ESP_OK) {
        /* Match Espressif's Mesh examples: create and attach the default STA
         * netif before esp_wifi_init(), so its event handlers own the first
         * root association. */
        wifi_err = mesh_netifs_init();
    }
    if (wifi_err == ESP_OK) wifi_err = wifi_station_prepare(&has_wifi_credentials);
    if (wifi_err != ESP_OK) {
        ESP_LOGW(TAG, "Wi-Fi credential check failed; discovery continues: %s",
                 esp_err_to_name(wifi_err));
    } else if (has_wifi_credentials) {
        ESP_LOGI(TAG, "Starting Mesh network");
        wifi_err = mesh_network_start_prepared();
        if (wifi_err != ESP_OK) {
            ESP_LOGW(TAG, "Mesh network start failed: %s; discovery continues",
                     esp_err_to_name(wifi_err));
        } else {
            ESP_LOGI(TAG, "Mesh network started; starting MQTT registration");
            esp_err_t mqtt_err = mqtt_registration_start();
            if (mqtt_err != ESP_OK) {
                ESP_LOGW(TAG, "MQTT registration start failed: %s; discovery continues",
                         esp_err_to_name(mqtt_err));
            } else {
                ESP_LOGI(TAG, "MQTT registration initialized");
            }
        }
    }
    /* USB Serial/JTAG is available during the normal application lifecycle.
     * It replaces the temporary setup AP without requiring a button, a reset,
     * or a gateway wlan0 mode transition. */
    esp_err_t usb_err = usb_provisioning_start(node_id);
    if (usb_err != ESP_OK) {
        ESP_LOGE(TAG, "USB provisioning transport failed: %s", esp_err_to_name(usb_err));
    }
    esp_err_t sensor_err = sensor_manager_start();
    if (sensor_err != ESP_OK) {
        ESP_LOGW(TAG, "Sensor manager start failed: %s; continuing",
                 esp_err_to_name(sensor_err));
    } else {
        ESP_LOGI(TAG, "Sensor manager started");
    }
    // Safe once per boot for BLE-only operation; never repeat this in a
    // discovery lifecycle because the released Classic BT memory is permanent.
    ESP_ERROR_CHECK(esp_bt_controller_mem_release(ESP_BT_MODE_CLASSIC_BT));
    uint8_t provisioning_state = has_wifi_credentials
        ? OMK_NODE_PROVISIONING_STATE_PROVISIONED
        : OMK_NODE_PROVISIONING_STATE_UNREGISTERED;
    esp_err_t registration_err = node_registration_get_provisioning_state(
        has_wifi_credentials, &provisioning_state);
    if (registration_err != ESP_OK) {
        ESP_LOGW(TAG, "Could not read registration state; using Wi-Fi state: %s",
                 esp_err_to_name(registration_err));
    }
    ESP_ERROR_CHECK(discovery_ble_start(node_id, provisioning_state));
    ESP_LOGI(TAG, "OMK Node discovery advertising started");
}

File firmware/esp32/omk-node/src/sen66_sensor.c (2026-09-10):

#include "sen66_sensor.h"

#include <math.h>
#include <string.h>

#include "esp_timer.h"
#include "freertos/FreeRTOS.h"
#include "freertos/task.h"

#define SEN66_I2C_ADDRESS 0x6B
#define SEN66_I2C_FREQUENCY_HZ 100000
#define SEN66_I2C_TIMEOUT_MS 100
#define SEN66_DEVICE_RESET_COMMAND 0xD304
#define SEN66_START_CONTINUOUS_MEASUREMENT_COMMAND 0x0021
#define SEN66_STOP_MEASUREMENT_COMMAND 0x0104
#define SEN66_GET_DATA_READY_COMMAND 0x0202
#define SEN66_READ_MEASURED_VALUES_COMMAND 0x0300
#define SEN66_GET_PRODUCT_NAME_COMMAND 0xD014

static esp_err_t sen66_send_command(i2c_master_dev_handle_t device, uint16_t command) {
    uint8_t buffer[] = {(uint8_t)(command >> 8), (uint8_t)command};
    return i2c_master_transmit(device, buffer, sizeof(buffer), SEN66_I2C_TIMEOUT_MS);
}

static uint8_t sen66_crc8(const uint8_t *data) {
    uint8_t crc = 0xFF;
    for (size_t byte = 0; byte < 2; ++byte) {
        crc ^= data[byte];
        for (uint8_t bit = 0; bit < 8; ++bit) {
            crc = (crc & 0x80) ? (uint8_t)((crc << 1) ^ 0x31) : (uint8_t)(crc << 1);
        }
    }
    return crc;
}

static esp_err_t sen66_read_response(i2c_master_dev_handle_t device, uint16_t command,
                                     uint8_t *values, size_t value_size) {
    if (value_size == 0 || value_size > 32 || value_size % 2 != 0) {
        return ESP_ERR_INVALID_ARG;
    }

    esp_err_t err = sen66_send_command(device, command);
    if (err != ESP_OK) {
        return err;
    }
    vTaskDelay(pdMS_TO_TICKS(20));

    uint8_t response[48];
    memset(response, 0xFF, sizeof(response));
    size_t word_count = value_size / 2;
    err = i2c_master_receive(device, response, word_count * 3, SEN66_I2C_TIMEOUT_MS);
    if (err != ESP_OK) {
        return err;
    }
    for (size_t word = 0; word < word_count; ++word) {
        const uint8_t *response_word = &response[word * 3];
        if (response_word[2] != sen66_crc8(response_word)) {
            return ESP_ERR_INVALID_CRC;
        }
        values[word * 2] = response_word[0];
        values[word * 2 + 1] = response_word[1];
    }
    return ESP_OK;
}

static uint16_t sen66_u16(const uint8_t *value) {
    return ((uint16_t)value[0] << 8) | value[1];
}

static sensor_identity_t identify_device(i2c_master_dev_handle_t device) {
    uint8_t name[32];
    if (sen66_read_response(device, SEN66_GET_PRODUCT_NAME_COMMAND, name, sizeof(name)) != ESP_OK)
        return SENSOR_ID_ERROR;
    /* SEN6x datasheet 4.8.18: string<32>, ASCII, null terminated, CRC/word.
     * Padding after NUL is unspecified. Never accept prefixes as exact models. */
    size_t length = 0;
    while (length < sizeof(name) && name[length] != 0) {
        if (name[length] < 0x20 || name[length] > 0x7E) return SENSOR_ID_ERROR;
        ++length;
    }
    if (length == 0 || length == sizeof(name)) return SENSOR_ID_ERROR;
    if (strcmp((char *)name, "SEN66") == 0) return SENSOR_ID_EXACT;
    if (strcmp((char *)name, "SEN63C") == 0 || strcmp((char *)name, "SEN65") == 0 ||
        strcmp((char *)name, "SEN68") == 0) return SENSOR_ID_AMBIGUOUS;
    return SENSOR_ID_NO_MATCH;
}

static esp_err_t add_device(i2c_master_bus_handle_t bus, i2c_master_dev_handle_t *device) {
    i2c_device_config_t config = {
        .dev_addr_length = I2C_ADDR_BIT_LEN_7, .device_address = SEN66_I2C_ADDRESS,
        .scl_speed_hz = SEN66_I2C_FREQUENCY_HZ,
    };
    return i2c_master_bus_add_device(bus, &config, device);
}

sensor_identity_t sen66_sensor_identify(i2c_master_bus_handle_t bus) {
    if (!bus) return SENSOR_ID_ERROR;
    esp_err_t err = i2c_master_probe(bus, SEN66_I2C_ADDRESS, SEN66_I2C_TIMEOUT_MS);
    if (err == ESP_ERR_NOT_FOUND) return SENSOR_ID_NO_MATCH;
    if (err != ESP_OK) return SENSOR_ID_ERROR;
    i2c_master_dev_handle_t device = NULL;
    if (add_device(bus, &device) != ESP_OK) return SENSOR_ID_ERROR;
    sensor_identity_t result = identify_device(device);
    if (i2c_master_bus_rm_device(device) != ESP_OK) return SENSOR_ID_ERROR;
    return result;
}

esp_err_t sen66_sensor_probe(i2c_master_bus_handle_t bus, sen66_sensor_t *sensor) {
    if (bus == NULL || sensor == NULL) {
        return ESP_ERR_INVALID_ARG;
    }

    memset(sensor, 0, sizeof(*sensor));
    sensor->state = SEN66_SENSOR_STATE_ABSENT;
    if (sen66_sensor_identify(bus) == SENSOR_ID_EXACT) {
        sensor->state = SEN66_SENSOR_STATE_PROBED;
        return ESP_OK;
    }
    return ESP_ERR_NOT_FOUND;
}

esp_err_t sen66_sensor_start(i2c_master_bus_handle_t bus, sen66_sensor_t *sensor) {
    if (bus == NULL || sensor == NULL || sensor->state != SEN66_SENSOR_STATE_PROBED) {
        return ESP_ERR_INVALID_STATE;
    }

    esp_err_t err = add_device(bus, &sensor->device);
    if (err != ESP_OK) {
        return err;
    }

    /* Revalidate after selection, immediately before the first mutation. */
    if (identify_device(sensor->device) != SENSOR_ID_EXACT) {
        sen66_sensor_close(sensor);
        return ESP_ERR_INVALID_STATE;
    }
    /* Recovery (or an MCU reboot) may leave a confirmed SEN66 measuring.
     * Reset is idle-only. Stop can NACK if already idle; the following identity
     * read and reset must still succeed. Never do this during discovery. */
    (void)sen66_send_command(sensor->device, SEN66_STOP_MEASUREMENT_COMMAND);
    vTaskDelay(pdMS_TO_TICKS(1400));
    if (identify_device(sensor->device) != SENSOR_ID_EXACT) {
        sen66_sensor_close(sensor);
        return ESP_ERR_INVALID_STATE;
    }
    err = sen66_send_command(sensor->device, SEN66_DEVICE_RESET_COMMAND);
    if (err == ESP_OK) {
        vTaskDelay(pdMS_TO_TICKS(1200));
        err = sen66_send_command(sensor->device, SEN66_START_CONTINUOUS_MEASUREMENT_COMMAND);
    }
    if (err == ESP_OK) {
        vTaskDelay(pdMS_TO_TICKS(50));
        sensor->state = SEN66_SENSOR_STATE_MEASURING;
        return ESP_OK;
    }

    i2c_master_bus_rm_device(sensor->device);
    sensor->device = NULL;
    sensor->state = SEN66_SENSOR_STATE_ABSENT;
    return err;
}

esp_err_t sen66_sensor_stop(sen66_sensor_t *sensor) {
    if (sensor == NULL) {
        return ESP_ERR_INVALID_ARG;
    }

    esp_err_t err = ESP_OK;
    if (sensor->device != NULL && sensor->state == SEN66_SENSOR_STATE_MEASURING &&
        identify_device(sensor->device) == SENSOR_ID_EXACT) {
        err = sen66_send_command(sensor->device, SEN66_STOP_MEASUREMENT_COMMAND);
        if (err == ESP_OK) {
            vTaskDelay(pdMS_TO_TICKS(1400));
        }
    }
    if (sensor->device != NULL) {
        i2c_master_bus_rm_device(sensor->device);
    }
    sensor->device = NULL;
    sensor->state = SEN66_SENSOR_STATE_ABSENT;
    return err;
}
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

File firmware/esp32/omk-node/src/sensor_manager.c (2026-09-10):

#include "sensor_manager.h"

#include <inttypes.h>
#include <stdlib.h>
#include "driver/i2c_master.h"
#include "esp_log.h"
#include "esp_timer.h"
#include "freertos/FreeRTOS.h"
#include "freertos/task.h"
#include "node_registration.h"
#include "sensor_driver.h"

static const char *TAG = "sensor_manager";
#ifndef OMK_SENSOR_I2C_SDA_GPIO
#define OMK_SENSOR_I2C_SDA_GPIO 2
#endif
#ifndef OMK_SENSOR_I2C_SCL_GPIO
#define OMK_SENSOR_I2C_SCL_GPIO 1
#endif
#define SENSOR_I2C_FREQUENCY_HZ 100000
#define SENSOR_RETRY_INTERVAL_MS 60000
#define SENSOR_MEASUREMENT_INTERVAL_MS 10000
#define SENSOR_MEASUREMENT_LIVENESS_TIMEOUT_MS 60000

static i2c_master_bus_handle_t sensor_i2c_bus;
typedef struct {
    sensor_endpoint_t endpoint;
    const sensor_driver_t *driver;
    void *context;
    unsigned consecutive_read_failures;
    bool logical_id_warning_logged;
    bool mqtt_warning_logged;
    bool recovery_pending;
    uint32_t recovery_count;
    uint32_t measurement_timeout_count;
    uint64_t last_successful_measurement_ms;
    uint64_t next_attempt_ms;
} sensor_slot_t;

static uint64_t monotonic_milliseconds(void) {
    return (uint64_t)(esp_timer_get_time() / 1000);
}

static void recover_sensor(sensor_slot_t *slot, const char *reason) {
    ESP_LOGW(TAG, "Recovering %s after %s", slot->driver->driver_id, reason);
    ++slot->recovery_count;
    slot->driver->diagnostics(slot->recovery_count, slot->measurement_timeout_count);
    slot->driver->connected(false);
    // The endpoint may now contain a different sensor. Release locally only.
    slot->driver->close(slot->context);
    free(slot->context);
    slot->context = NULL;
    slot->driver = NULL;
    slot->consecutive_read_failures = 0;
    slot->recovery_pending = true;
    slot->next_attempt_ms = monotonic_milliseconds() + SENSOR_RETRY_INTERVAL_MS;
}

static void sensor_slot_tick(sensor_slot_t *slot) {
    if (monotonic_milliseconds() < slot->next_attempt_ms) return;
    if (!slot->driver) {
        const sensor_driver_t *selected = NULL;
        sensor_identity_t identity = sensor_discover(&slot->endpoint, sensor_drivers,
                                                     sensor_driver_count, &selected);
        slot->next_attempt_ms = monotonic_milliseconds() + SENSOR_RETRY_INTERVAL_MS;
        if (identity != SENSOR_ID_EXACT) {
            ESP_LOGI(TAG, "Sensor identity unresolved (%d); retrying in 60 seconds", identity);
            return;
        }
        void *context = calloc(1, selected->context_size);
        if (!context) return;
        esp_err_t err = selected->start(&slot->endpoint, context);
        if (err != ESP_OK) {
            selected->connected(false);
            selected->close(context);
            free(context);
            slot->next_attempt_ms = monotonic_milliseconds() + SENSOR_RETRY_INTERVAL_MS;
            ESP_LOGW(TAG, "%s startup failed: %s", selected->driver_id, esp_err_to_name(err));
            return;
        }
        slot->driver = selected;
        slot->context = context;
        selected->connected(true);
        slot->consecutive_read_failures = 0;
        slot->last_successful_measurement_ms = monotonic_milliseconds();
        slot->next_attempt_ms = slot->last_successful_measurement_ms + SENSOR_MEASUREMENT_INTERVAL_MS;
        ESP_LOGI(TAG, "%s continuous measurement started", selected->driver_id);
        return;
    }

    bool data_ready = false;
    esp_err_t err = slot->driver->read(slot->context, &data_ready);
    if (err != ESP_OK) {
        ++slot->consecutive_read_failures;
        ESP_LOGW(TAG, "%s read failed: %s (consecutive_failures=%u)",
                 slot->driver->driver_id, esp_err_to_name(err), slot->consecutive_read_failures);
        // Loss of identity is immediate; ordinary transient I/O retains the
        // existing three-failure recovery policy.
        if (err == ESP_ERR_INVALID_STATE || slot->consecutive_read_failures >= 3) {
            recover_sensor(slot, "identity lost or consecutive read failures");
            return;
        }
    } else if (data_ready) {
        slot->consecutive_read_failures = 0;
        slot->last_successful_measurement_ms = monotonic_milliseconds();
        if (slot->recovery_pending) {
            ESP_LOGI(TAG, "%s measurement recovered", slot->driver->driver_id);
            slot->recovery_pending = false;
        }
        char logical_id[OMK_NODE_LOGICAL_ID_MAX_LENGTH + 1];
        err = node_registration_get_logical_id(logical_id, sizeof(logical_id));
        if (err != ESP_OK) {
            if (!slot->logical_id_warning_logged) {
                ESP_LOGI(TAG, "%s publish waiting for logical ID", slot->driver->driver_id);
                slot->logical_id_warning_logged = true;
            }
        } else {
            slot->logical_id_warning_logged = false;
            err = slot->driver->publish(slot->context, logical_id);
            if (err != ESP_OK && !slot->mqtt_warning_logged) {
                ESP_LOGW(TAG, "%s MQTT publish unavailable: %s", slot->driver->driver_id, esp_err_to_name(err));
                slot->mqtt_warning_logged = true;
            } else if (err == ESP_OK) {
                slot->mqtt_warning_logged = false;
            }
        }
    }
    if (monotonic_milliseconds() - slot->last_successful_measurement_ms >= SENSOR_MEASUREMENT_LIVENESS_TIMEOUT_MS) {
        ++slot->measurement_timeout_count;
        ESP_LOGW(TAG, "%s measurement timeout: no successful measurement for %" PRIu64 " s; recovering",
                 slot->driver->driver_id,
                 (monotonic_milliseconds() - slot->last_successful_measurement_ms) / 1000);
        recover_sensor(slot, "measurement liveness timeout");
        return;
    }
    slot->next_attempt_ms = monotonic_milliseconds() + SENSOR_MEASUREMENT_INTERVAL_MS;
}

static void sensor_manager_task(void *arg) {
    (void)arg;
    // Current board profile has one candidate endpoint. More slots do not
    // require model branches; multi-sensor Logical IDs remain a future change.
    sensor_slot_t slots[] = {{ .endpoint = {
        .transport = SENSOR_TRANSPORT_I2C, .handle = sensor_i2c_bus,
        .location.i2c_address = 0x6B,
    } }};
    for (;;) {
        for (size_t i = 0; i < sizeof(slots) / sizeof(slots[0]); ++i) sensor_slot_tick(&slots[i]);
        uint64_t now = monotonic_milliseconds();
        uint64_t wait_ms = SENSOR_RETRY_INTERVAL_MS;
        for (size_t i = 0; i < sizeof(slots) / sizeof(slots[0]); ++i) {
            uint64_t remaining = slots[i].next_attempt_ms > now ? slots[i].next_attempt_ms - now : 1;
            if (remaining < wait_ms) wait_ms = remaining;
        }
        vTaskDelay(pdMS_TO_TICKS(wait_ms) ? pdMS_TO_TICKS(wait_ms) : 1);
    }
}
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

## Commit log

2026-07-29 Add Raspberry Pi setup automation
2026-07-29 firmware: add ESP32 SEN66 PlatformIO node
2026-07-30 feat: add ESP32 SEN66 MQTT publishing
2026-07-30 feat: add generic MQTT sensor collector
2026-08-03 Add ESP32-C3 schematic generation PoC
    [esp32-c3-main.kicad_sch]
2026-08-03 Add ESP32-C3 firmware support
2026-08-03 Complete ESP32-C3 main schematic
    [esp32-c3-main.kicad_sch]
2026-08-03 Add SEN66 carrier schematic
    [sen66-carrier.kicad_sch]
2026-08-03 Integrate JST PH connectors into schematics
    [esp32-c3-main.kicad_sch, sen66-carrier.kicad_sch]
2026-08-03 Integrate XGL4020 inductor into main schematic
    [esp32-c3-main.kicad_sch]
2026-08-04 Add Ichijo power flow to dashboard
2026-08-04 Add live latest-state cache to sensor collector
2026-08-04 Persist latest sensor state for dashboard
2026-08-04 Make latest sensor state readable
2026-08-04 Fix data transformer timer description
2026-08-04 Archive cancelled ESP32-C3 PCB work
    [esp32-c3-main.kicad_pcb]
2026-08-05 Fix Ichijo load power calculation
2026-08-05 Reorder dashboard power sidebar
2026-08-05 Align dashboard power detail values
2026-08-05 Fix Harvest uploader mount check
2026-08-10 docs: record AtomS3 Lite SEN66 wiring verification
2026-08-12 Add SwitchBot BLE sensor setup and management
2026-08-12 Fix SwitchBot BLE runtime and decoder
2026-08-12 Refine SwitchBot BLE manufacturer decoding
2026-08-12 Stabilize BLE sensor setup workflow
2026-08-12 Show latest values for registered BLE sensors
2026-08-12 Style registered BLE sensor values
2026-08-12 Add BLE sensor editing and simplify admin icon
2026-08-12 Proxy BLE sensor updates through dashboard
2026-08-12 Add SwitchBot motion sensor support
2026-08-12 Add SwitchBot contact sensor support
2026-08-12 Fix contact sensor manufacturer classifier
2026-08-12 Fix contact sensor state polarity
2026-08-12 Fix contact sensor manufacturer state decoding
2026-08-12 Add SwitchBot waterproof sensor support
2026-08-12 Rename SwitchBot models to sensor names
2026-08-12 Aggregate environment sensors for Harvest
2026-08-12 Add SwitchBot Plug Mini support
2026-08-14 Add BLE sensor deletion support
2026-08-15 Add ESP32 node provisioning and gateway registration
    [partitions.csv]
2026-08-15 Add OMK node registration reset tool
    [main.c]
2026-08-15 Simplify initial Wi-Fi provisioning flow
2026-08-15 Fix Harvest uploader thread safety
2026-08-17 Relay SwitchBot Meter data over MQTT
2026-08-17 feat(node): unify SEN66 and BLE relay firmware
2026-08-17 feat(gateway): prefer direct BLE over relay
2026-08-17 feat(ble): resolve relay devices through gateway registry
2026-08-17 Refine dashboard block sizing and battery display
2026-08-17 Refine dashboard power labels and block naming
2026-08-19 Refine dashboard labels and power flow status
2026-08-19 Fix dashboard admin asset caching and power flow UI
2026-08-19 Finalize dashboard power labels and spacing
2026-08-19 Update battery display label test
2026-08-19 Finalize dashboard navigation and save flow
2026-08-19 Add SEN66 node enclosure models
    [sen66-node-body.stl, sen66-node-lid.stl]
2026-08-19 Fix SwitchBot CO2 advertisement decoding
2026-08-20 Reorganize repository structure
    [esp32-c3-main.kicad_pcb, esp32-c3-main.kicad_sch, sen66-carrier.kicad_sch]
2026-08-20 Clean up repository documentation and samples
2026-08-20 Unify ESP32 nodes on common firmware
2026-08-21 fix: restore retained logical device status
2026-08-25 Add SwitchBot Presence Sensor support
2026-08-25 Improve Presence Sensor admin display
2026-09-01 data-transformerのBLE Parquet対応を整備
2026-09-01 data-transformerの管理topicとdegraded記録を改善
2026-09-01 data-transformerの旧BLE入力に対応
2026-09-01 CSV書き出しengineとCLIを追加
2026-09-01 omk-export launcherの配置を修正
2026-09-01 data-exporterのCSV変換を高速化
2026-09-01 USBメモリへの安全なexport backendを追加
2026-09-01 USB exportのautomount対応とlockを修正
2026-09-01 USB helperのlsblk tree取得を修正
2026-09-01 USB exportの管理APIと画面を追加
2026-09-02 USB export管理画面を実機投入向けに補強
2026-09-02 USB書き出し画面をタッチ操作向けに改善
2026-09-02 USB書き出し画面を7インチ向けに再設計
2026-09-02 USB書き出し画面を横画面向けに圧縮
2026-09-02 USB書き出し状態表示を改善
2026-09-02 USB書き出しのunmount確認と状態表示を修正
2026-09-02 書き出し画面のスクロールを修正
2026-09-02 USB helperをhost mount namespaceで実行
2026-09-02 Complete ESP32 reset reason mapping
2026-09-02 Add USB node provisioning to sensor management UI
2026-09-02 fix(mesh): prevent root conflicts and recover SEN66
    [sensor_manager.c]
2026-09-03 docs: add reference OMK parts list
    [onyx-usb-holder.stl]
2026-09-03 BLE relayをraw observationへ汎用化
2026-09-03 BLE relayでscan responseを取得する
2026-09-03 開閉センサーのtimeout状態をopenとしてdecode
2026-09-03 BLE relayのdirect優先をGatewayで制御
2026-09-03 開閉センサーの可変manufacturer領域を許容
2026-09-03 登録済みプラグのmanufacturer広告をdecode
2026-09-03 BLE raw relayの送信頻度を制限
2026-09-03 SEN66 Nodeケーブル固定治具を追加
    [sen66-node-cable-jig.stl]
2026-09-03 展示用デモモードを追加
2026-09-03 展示用デモモードの表示と画面切替を修正
2026-09-03 デモ用模擬データを実測値に更新
2026-09-04 Finalize gateway AP activation flow
2026-09-09 Fix SwitchBot motion sensor classification
2026-09-09 Improve unsupported SwitchBot handling
2026-09-09 Make B-route USB recovery device-independent
2026-09-09 Harden ESP32 firmware flashing identity checks
2026-09-10 Harden SwitchBot model identification
2026-09-10 Harden Node sensor identification and recovery
2026-09-11 Harden USB export device identity
2026-09-11 Reclaim inactive BLE relay slots
2026-09-11 Disable OMK Node setup buttons while running
2026-09-11 Clarify SEN66 detection and registration flow
2026-09-11 Hide stale Node sensor state during USB detection
2026-09-16 Complete B-route first-time setup flow
2026-09-16 Add OMK Node reinitialization flow
2026-09-16 Support multiple SEN66 sensors in Harvest
2026-09-16 Support unconfirmed SwitchBot sensor registration
2026-09-16 Fix B-route adapter recovery and sensor naming
2026-09-18 Support manufacturer-only Presence Sensor Pro
2026-09-18 Polish demo display and sensor keyboard UI
2026-09-28 Fix SwitchBot CO2 high-value decoding
2026-10-01 Align developer documentation with current implementation
2026-10-06 Streamline OMK first-time setup flow
2026-10-14 WIP: migrate unpushed ESP32 firmware from Khadas Mind
2026-11-04 Prepare 021ff22-equivalent prebuilt and release documentation
    Use the preserved SEN66-002 app with the existing bootloader and partition
    table. Keep the embedded 26b3ac5 version and record its correspondence to
    source checkpoint 021ff22 in provenance.json.
    Align the manifest and SPDX SBOM with the packaged files, and document
    the remaining Root/parent-switch validation and unresolved layer-3 Mesh
    relay issue. Runtime source and build settings are unchanged.
    Validation: 346 firmware host tests, 7 package host tests, 30 installed
    distribution checks, and staged git diff --check passed.
